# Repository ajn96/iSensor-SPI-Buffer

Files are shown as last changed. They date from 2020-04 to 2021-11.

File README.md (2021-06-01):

# iSensor SPI Buffer
The iSensor SPI Buffer is a hardware and software solution designed to buffer iSensor IMU data, enabling asynchronous sampling systems (specifically embedded Linux systems) such as the Raspberry Pi, BeagleBone, Nvidia Jetson, etc. to capture IMU data at high sampling rates **with accurate timestamps and** **without data loss**. Output data is provided through a USB Virtual COM port and/or a user SPI port allowing transparent augmentation of an existing IMU interface system.

The firmware runs on an STM32F303 microprocessor to enable full-throughput, buffered IMU data capture with a variety of output data formats. An ADG1611 analog switch IC to enable routing SYNC and DATA READY signals from the host system directly to the IMU. The SPI buffer board is designed to be compatible with all current and future iSensor IMU products. 

A custom PCB was designed to fit the profile and form factor of an ADIS1649x IMU. This profile allows the iSensor SPI Buffer to act as a drop-in solution for existing, high-performance solutions. The buffer interface is designed to mimic the iSensor page convention and SPI settings out-of-the box. 

Additional hardware and software resources are linked below.

[Detailed Register Map](markdown/REGISTER_DEFINITION.md)

[USB CLI Definition](markdown/USB_CLI.md)

[Python USB Interfacing Library](PythonUtil/)

[SD Card Data Logging Scripts](markdown/SD_SCRIPTS.md)

[Firmware Documentation (Doxygen)](https://ajn96.github.io/iSensor-SPI-Buffer/files.html)

[Software Timing Characterization](markdown/TIMING.MD)

[STM32 Processor Pin Map](markdown/PIN_MAP.md)

[Programming Guide](markdown/BUILDING.md)

A video walkthrough and tutorial of the SPI Buffer Board's features is hosted on YouTube. Click on the image below to check it out!

(http://www.youtube.com/watch?v=azpeXvWH4VI "iSensor SPI Buffer Board Walkthrough 07/09/2020")

## Hardware Platform

This firmware is designed to operate in the STMicro processor family - specifically the STM32F303 processor. The STM32F303RET6 variant of the processor family was chosen for this application because of its large SRAM and low cost. 

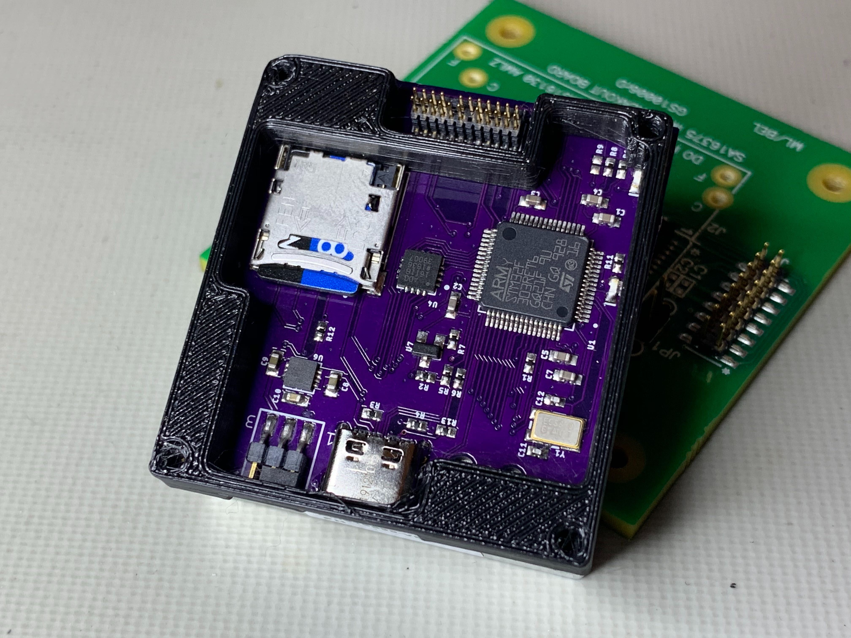
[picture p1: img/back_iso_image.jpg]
iSensor SPI Buffer Isometric Image


Revision B of the PCB design includes the following features:

- STM32F303RET6 processor (64k SRAM, hardware SPI peripherals, DMA fabric)
- ADG1611 analog switch - used for mapping SYNC and DATA READY signals from the IMU to the buffer board or SPI host
- ADP1706 high-transient linear regulator - used to regulate USB 5V and power both the IMU and buffer board
  - Power supply selection jumper for powering the buffer board & IMU from the 24-pin IMU connector or USB
- USB C expansion port - Provides a USB virtual COM port command line interface to read/write registers and stream IMU data
- SD card slot - Allows IMU data to be captured "headless" without the use of a PC or SPI host
- LEDs - used to indicate buffer state and SPI buffer errors
- 24-pin IMU connectors - used to interface with and pass through IMU and SPI Buffer data to and from a host using SPI
- ADIS1650x footprint - used to enable the evaluation and use of compact iSensor IMUs

The iSensor SPI Buffer was designed to sit between an iSensor IMU and the SPI host without changing any existing PCB designs. 

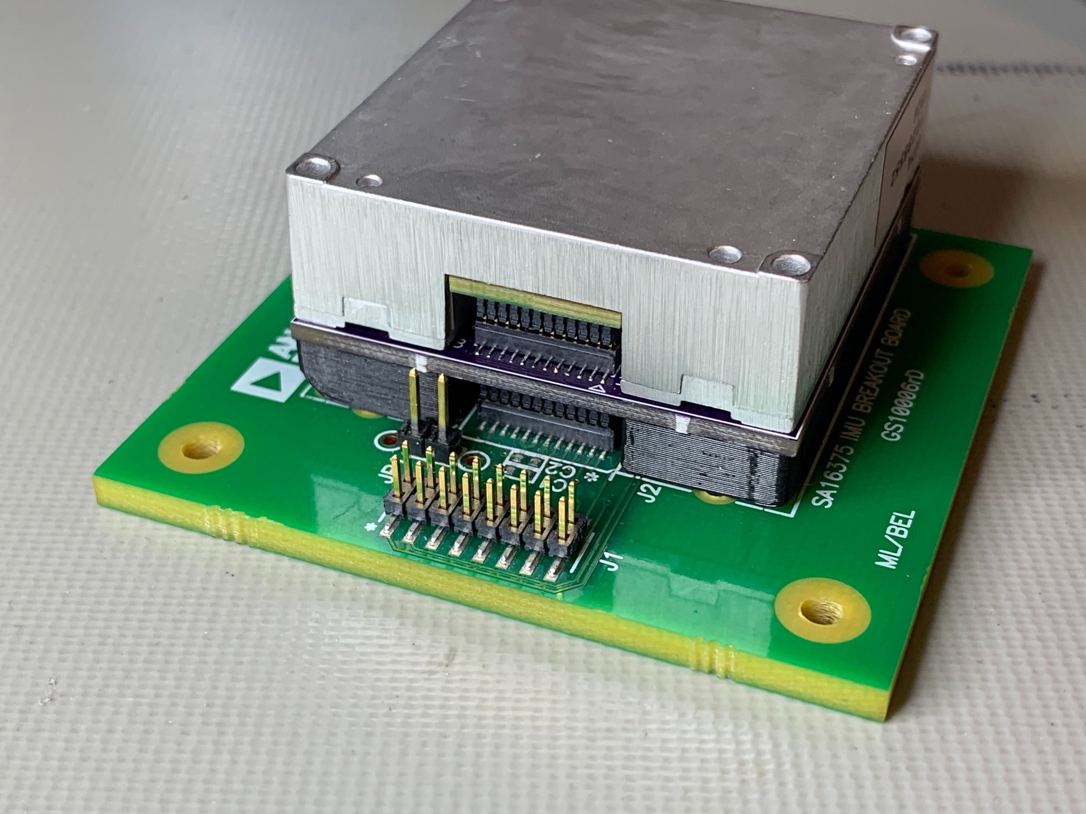
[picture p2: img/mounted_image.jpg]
iSensor SPI Buffer Mounted Image


## Development Environment and Hardware

### Software / IDE

The code contained in this repository was developed using the freely available [STM32 Cube IDE](https://my.st.com/content/my_st_com/en/products/development-tools/software-development-tools/stm32-software-development-tools/stm32-ides/stm32cubeide). A compatible project file is also included in this repository to make getting stared as easy as possible. 

### Hardware

A [TC2030-IDC cable](https://www.tag-connect.com/product/tc2030-idc-6-pin-tag-connect-plug-of-nails-spring-pin-cable-with-legs) must be used to interface with the SWD pads on the Rev B PCB. Development was originally done on an [NUCLEO-F303RE](https://www.st.com/en/evaluation-tools/nucleo-f303re.html) development board. When programming a buffer board, we've continued to use the NUCLEO as the SWD programmer. 

## Linux Driver Support

Support for the SPI Buffer Board in Linux (over SPI) was developed by [spalani7](https://github.com/spalani7). His repository is located  [here](https://github.com/spalani7/adi_imu_driver). For USB interfacing, the included Python library can be utilized for easy integration with any USB capable system.

## Design Requirements and Features

### IMU Register Interface

* "Invisible" SPI pass-through to an iSensor IMU, including modules that implement register pages
* iSensor-SPI-Buffer configuration registers and buffered data acquisition registers will be placed on unassigned IMU pages (Pages 253 - 255)

### Buffered Data Acquisition

* Autonomous IMU data acquisition will be driven by the IMU-generated data ready signal. Data will be stored in the iSensor-SPI-Buffer SRAM until retrieved by a user
* Programmable data request message (MOSI) to be transmitted after each data ready signal. Allows users to customize the register writes, contents, and order
* Programmable data acquisition length after each IMU data ready signal. Allows the user to configure the length of data read back from the IMU
* Programmable data acquisition SPI word size. The default 16-bit length provides support standard register reads, writes, and burst reads on most IMUs

### Configuration Options

* Buffer overflow setting (stop sampling vs delete oldest)
* Data ready input (from IMU) DIO number
* IMU Data ready trigger polarity
* Master SPI (interface between the iSensor-SPI-Buffer firmware and the IMU) 
  * SCLK Frequency
  * Stall time
* Slave SPI (interface between the iSensor-SPI-Buffer firmware and the host processor) 
  * Standard SPI settings (CPOL, CPHA, endianness)

### Buffer Design

* Reading a buffer retrieve register will dequeue data from the buffer data structure to the buffer output registers for retrieval by a user
* The user will can clear the buffer using a control register
* A buffer counter will be added to each buffer for the user to keep track of the state of the buffer. This counter must also be accessible without dequeuing data from buffer
* Using a maximum buffer entry size of 64 bytes, the buffer will provide a minimum of 512 frames of buffering using 32KB SRAM
  * STM32F303 has 80KB of SRAM available, so more than 512 entries may be feasible

## Architecture

### SPI Ports

The iSensor-SPI-Buffer firmware will utilize two hardware SPI ports. One operating as a master (SPI buffer to IMU communication) and the other as a slave (SPI buffer to host)
* The slave SPI port will expose the IMU register interface along with the iSensor-SPI-Buffer configuration registers to the master
* The slave SPI port will support all standard SPI configuration parameters
* The master SPI port will communicate with the IMU using the standard, iSensor SPI protocol
* The master SPI port configuration will be limited to customizing SCLK frequency and stall time

### Program Flow

The iSensor-SPI-Buffer communications interfaces (SPI, SD card logging, USB CLI) are interrupt driven. A main cyclic executive loop handles command execution, interrupt generation, and diagnostics. The cyclic executive flow is shown below:

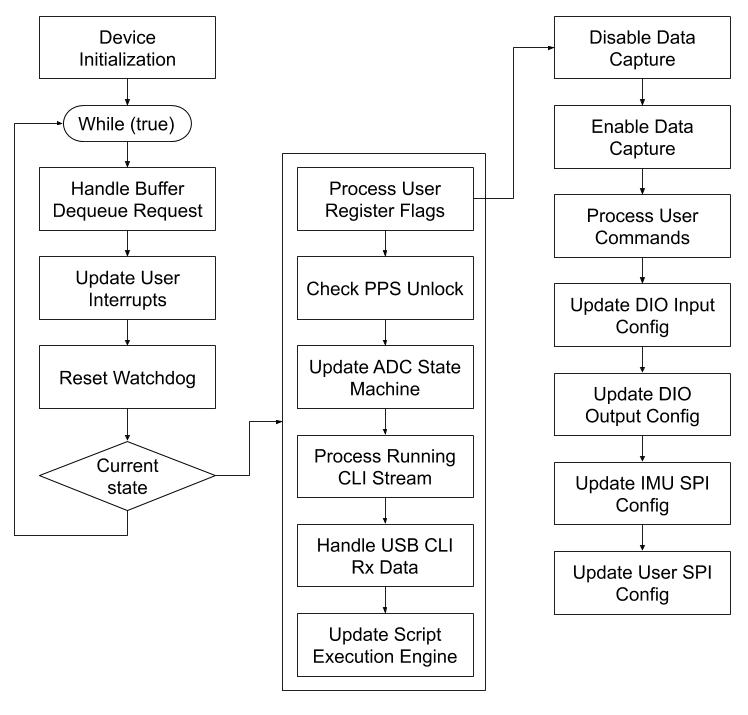
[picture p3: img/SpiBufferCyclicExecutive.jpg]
Cyclic Executive


**User SPI Interrupt**

There will be an ISR to handle user-initiated SPI transactions (slave interface). If the active register page is not one of the SPI buffer pages (253 - 255) all SPI transactions will be forwarded to the IMU downstream. 

SPI transactions will be classified as "read" or "write" by the SPI buffer board the same as the iSensor IMU SPI protocol. A write operation is signaled by setting the MSB of each 16-bit word. The upper 8 bits of the 16-bit transaction contain the register address to be written to as well as the read/write bit. The lower 8 bits of the 16-bit transaction contain the data to be written. 

A single read request transmitted to the SPI buffer on the slave interface will result in *two* SPI transactions sent to the IMU on the master interface. The first transaction sends the register read request to the IMU and the second reads the requested register contents data back from the IMU. The requested IMU register is then loaded into the SPI buffer user SPI transmit buffer so that it is available to the user on the next user SPI transaction.  For write transactions, a single write command will be sent to the IMU. The data resulting from the write transaction is then loaded into the SPI buffer user SPI transmit buffer. Unlike the read operation, a write operation will not automatically generate an additional SPI transaction. The diagram below shows the IMU SPI pass-through process for a register read operation.

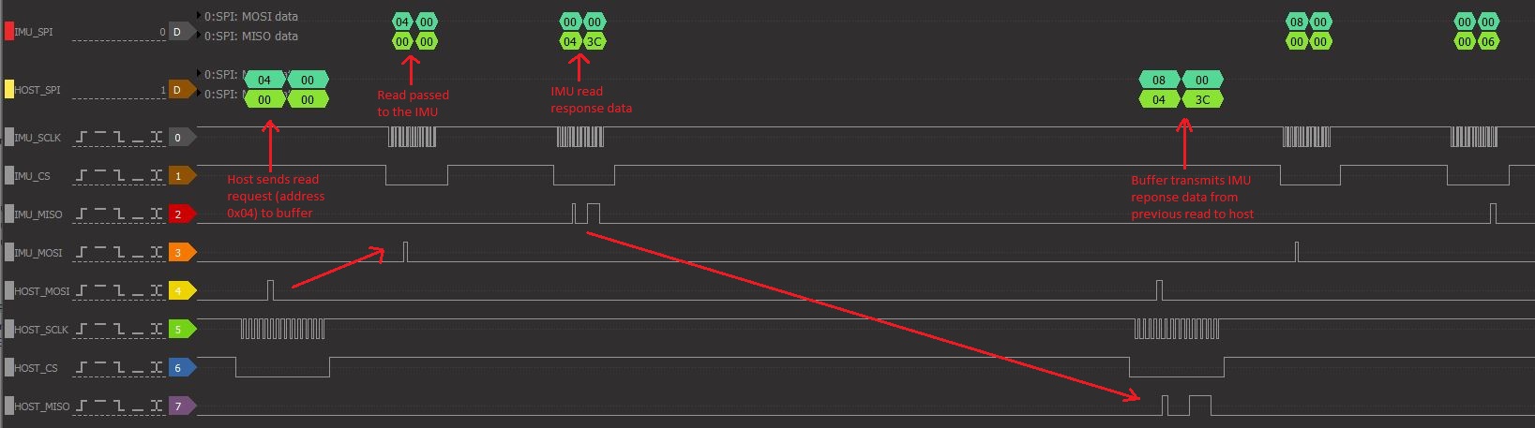
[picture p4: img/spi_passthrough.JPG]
SPI Passthrough


**Autonomous Data Capture**

When the currently selected page is 255 (buffer output register page), the iSensor SPI Buffer firmware will begin to monitor a user-specified GPIO interrupt for data ready signals pulses. Once a data ready pulse is detected, the firmware will transmit the data contained in page 254 (buffer transmit data) in the order specified by the user. Data received from the IMU during each 16-bit transaction will be stored in a new buffer entry in the iSensor-SPI-Buffer SRAM. The firmware will use DMA and timer peripherals to perform the SPI transactions with minimal CPU intervention while giving control over the SPI SCLK and stall time. 

The data capture ISR will be triggered by a user-specified GPIO, corresponding to the IMU data ready signal. The data capture ISR will configure a timer peripheral (which drives SPI word transmission timing) to trigger a DMA between memory and SPI. A DMA done ISR will handle cleaning up the DMA transactions and incrementing buffer pointers following a complete data set acquisition from the IMU. If the selected page is changed off page 255, the IMU data ready interrupt data capture functionality will be disabled (can be re-enabled by writing 255 to the page ID register on any page).

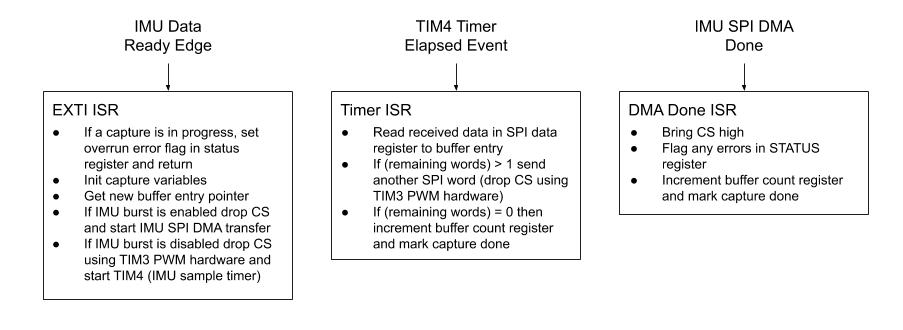
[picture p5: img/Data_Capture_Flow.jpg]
Buffered Capture Data Flow


**User Interrupt Signaling (to host)**

Each of the four DIO lines from the iSensor-SPI-Buffer to the master device can be configured to operate in one of four modes
* Watermark Interrupt Mode: The selected DIO will go high when a specified number of samples are available to be dequeued. This allows a master device to simply monitor the data ready interrupt signal for a positive edge, and then dequeue a large number of IMU data samples
* Buffer Full Interrupt Mode: The selected DIO will go high when the buffer is full
* Error Interrupt Mode: The selected DIO will go high when an error is detected and flagged in the STATUS register
* Pin Pass-Through Mode: The DIO output from the IMU (e.g. a data ready signal or sync signal) will be directly connected to the master device, using an ADG1611 switch. When a DIO is configured in pin pass-through mode it cannot be used for interrupt signaling

The state of each interrupt signal is checked and updated on each iteration of the main cyclic executive loop. This ensures quick response time to changes in the buffer state while maintaining a simple program flow.

**Command Execution**

* When a write is issued the USER_COMMAND register, a COMMAND flag will be set and processed by the cyclic executive loop
* While a command is being executed, the user SPI port will be disabled, and any interrupt lines (data ready or buffer full) will be brought low

### Register Interface

* Configuration registers for iSensor SPI buffer available on page 253
* The data acquisition write data registers (data to transmit per data ready) available on page 254
* Buffer output data registers on page 255
* Volatile output registers available on page 252

## Recovering From a Bad SPI Configuration

This buffer firmware includes a feature that allows the host SPI peripheral on the buffer board to be reconfigured to suit the host's needs. Because of this, it's possible to lock yourself out of the buffer board. A bad SPI configuration will usually look like the buffer board is returning the same value repeatedly for all registers. Note that the buffer board returning 0xFFFF or 0x0000 could be caused by other issues (no power to the buffer board, bad connection to the IMU, etc.) A bad SPI configuration will look similar to the image below.

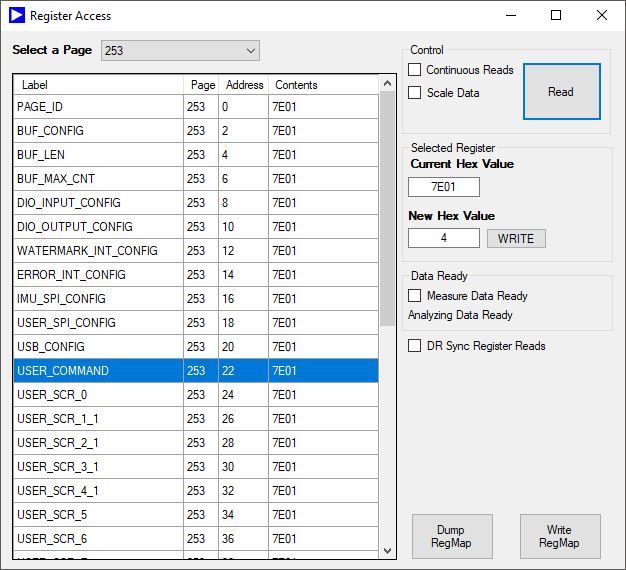
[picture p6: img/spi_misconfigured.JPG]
SPI Misconfigured


Recovering from a bad configuration requires using the USB CLI to communicate with the buffer board's firmware. While not mandatory, we recommend changing the jumper on the buffer board to USB power mode. The jumper just needs to be repositioned as shown below. 

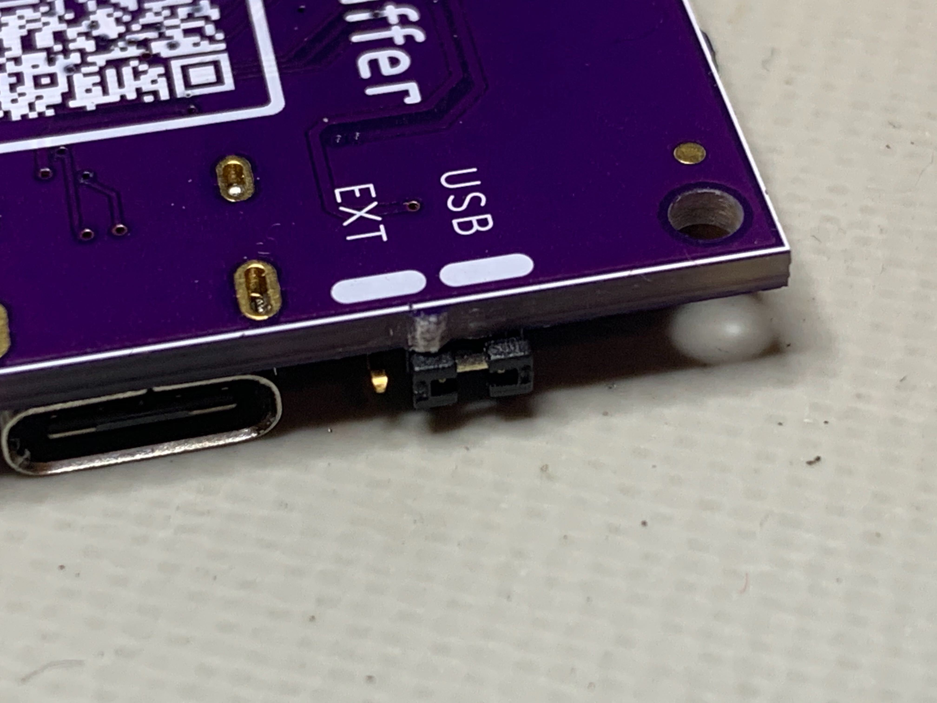
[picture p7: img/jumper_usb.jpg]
USB Jumper Setting


Using a terminal program such as [TeraTerm](https://ttssh2.osdn.jp/index.html.en) or [PuTTY](https://www.chiark.greenend.org.uk/~sgtatham/putty/) in Windows, connect to the board using the enumerated COM port. The virtual USB port will automatically detect the host serial settings, so additional configuration is usually unnecessary. 

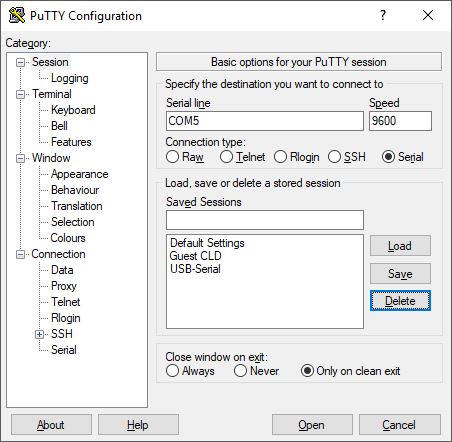
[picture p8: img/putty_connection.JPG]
PuTTY Connection


Once connected to the CLI, you can verify that the board is communicating correctly by typing `help` into the console. You should see a message like the one shown below.

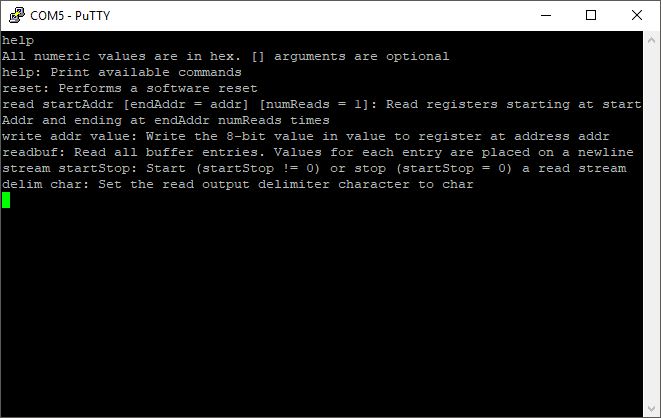
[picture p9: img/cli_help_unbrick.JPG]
CLI Help Print


After you've verified that the CLI is working correctly, type the following command, followed by a carriage return.

`freset`

This will execute a factory reset command followed by a flash update command. The board should now be reset to SPI Mode 3 with CS active low. The default register settings will have also been committed to flash, so they should persist throughout reboots. 

"The SPI who loved me" - PK

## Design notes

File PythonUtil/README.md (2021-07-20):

# iSensor-SPI-Buffer Python Library

This library allows easy programmatic interfacing to the iSensor-SPI-Buffer USB command line interface through a Python API. The API allows for configuration of the iSensor-SPI-Buffer board, as well as double buffered high-throughput data capture from a connected IMU. The image below shows the general flow for IMU data capture using this library.

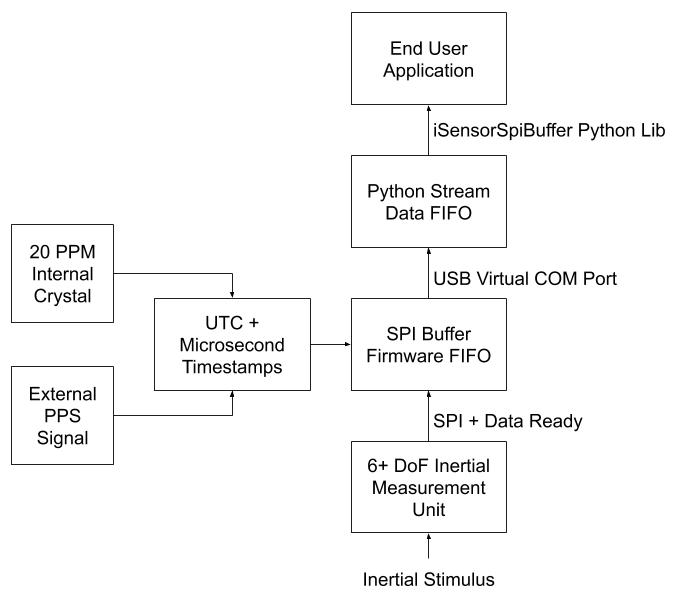
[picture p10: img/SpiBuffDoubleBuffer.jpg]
python_data_flow


### Prerequisites 

* Python 3.7 or newer
* PySerial (pip install pyserial)
* iSensor-SPI-Buffer firmware v1.11 or newer

### Hardware Setup

To use this library, the iSensor-SPI-Buffer board must be connected to your system via USB. For easiest setup, it is recommended to set the buffer board supply jumper to "USB", allowing the buffer board and connected DUT to be powered via a 2A linear regulator (from USB 5V supply).

Once the buffer board is successfully connected and powered over USB, the serial port "ID" must be determined. This port ID is provided to the ISensorSpiBuffer Python class initializer, and is used to set up internal the serial port object for CLI interactions

On Windows, the board will show up as a "USB Serial Device" under the Ports (COM & LPT) section of the device manager. The COM port name (in this example "COM11") is used as the port name for the ISensorSPIBuffer Python library

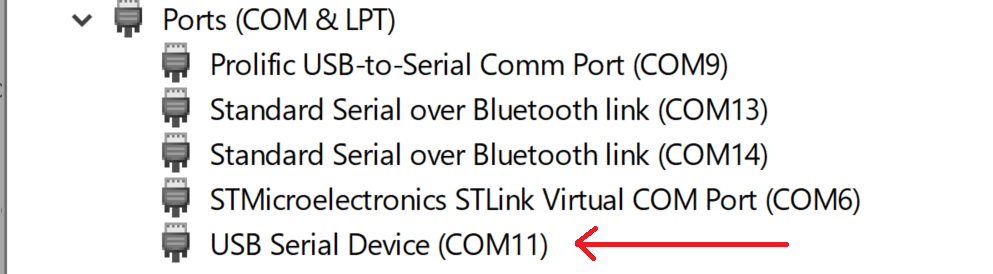
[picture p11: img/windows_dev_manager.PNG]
win_dev_manager


In Linux the port name (dev/ path for the device) can be determined using the included bash script. The following image shows the result from running ListDevPath in a Linux VM (with the buffer board passed in from the VirtualBox host). In this example, the buffer board is "/dev/ttyAMC0", which is provided as the port name for the ISensorSPIBuffer Python library.

linux_dev_list

### Python Setup

The PYTHONPATH variable will likely have to be set to include the spi_buf_cli.py file. To do this on Linux, open a terminal and for example type: `EXPORT PYTHONPATH=/home/usr/pi/Desktop/iSensor-SPI-Buffer/PythonUtil:$PYTHONPATH`. The directory should be modified to point to the location of the PythonUtil folder in the cloned repo.

On Windows, the PYTHONPATH can be updated by setting the Environmental Variable PYTHONPATH to include the PythonUtil directory in the cloned repo.

Once you have identified the port "ID" for the buffer board, connecting to the board is as simple as creating and initializing an instance of the ISensorSPIBuffer Python class. The initializer configures the specified serial port for use with the buffer board and performs basic setup on the buffer board itself.

For the Windows example

`buf = ISensorSPIBuffer("COM11")`

For the Linux example

`buf = ISensorSPIBuffer("/dev/ttyACM0")`

Afterwards, the functionality of the CLI can be checked using the check_connection() function. In addition, the current iSensor-SPI-Buffer firmware version can be checked using the version() call.

The outputs for the included adis1649x example programs are shown below:

**Linux**

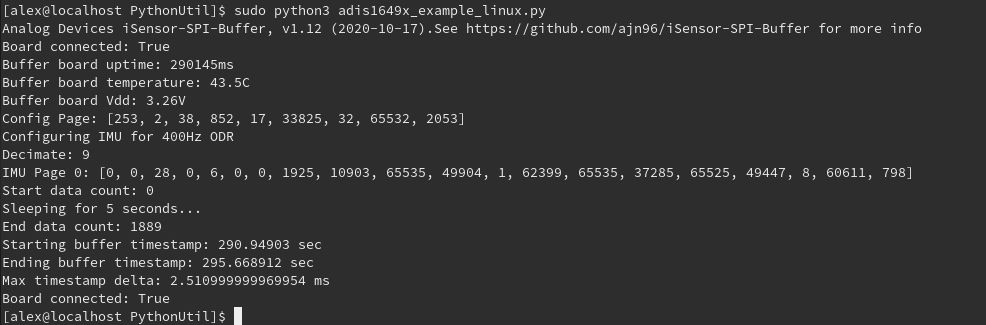
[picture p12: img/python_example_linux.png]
python_example_linux


Note, the IMU output data rate was limited to 400Hz because the program is running in a VM

**Windows**

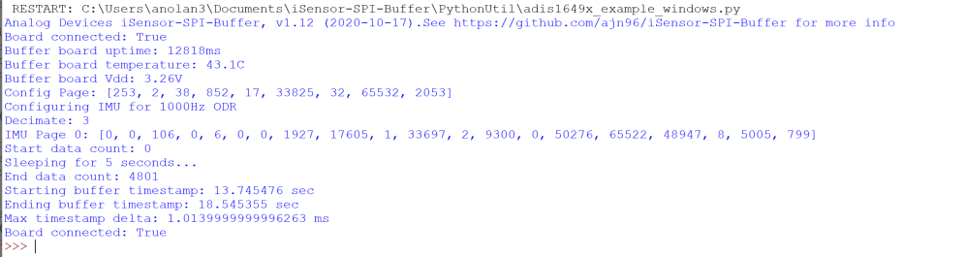
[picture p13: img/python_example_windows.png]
python_example_windows


In this example, the IMU output data rate was set to 1KHz, and each buffer was a burst output from the IMU. Using burst IMU outputs, data rates up to 2KHz seem to work consistently

## Debugging Common Setup Issues

There are a few problems which can cause difficulties using this library with the iSensor-SPI-Buffer board.

1. iSensor-SPI-Buffer firmware version not up to date. This Python library was not designed with backwards compatibility in mind, due to the relatively large number of changes in the firmware CLI behavior over the last few versions. It is intended to be used with the latest version of the iSensor-SPI-Buffer firmware for best operation. If this causes problems and you do not have the ability to update your buffer board firmware, you can download the python library version at the time of the release tag for your older version of firmware. There may be missing features / bug fixes in the older revision.
2. A "halted" stream (on PC side) can cause a watchdog reset event. This occurs when the PC does not request data back from the buffer board fast enough during a stream (mostly see this if you are debugging the Python library execution). After the watchdog reset, the board will show up as "Non-responding" in the Python library. This behavior should be resolved in future revisions of firmware.

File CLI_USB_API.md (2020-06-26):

# iSensor-SPI-Buffer USB Virtual COM Port CLI

## Driver

The USB port on the iSensor-SPI-Buffer is configured to act as a CDC type device, presenting as a virtual COM (serial) port.

The (windows) drivers to interface with the virtual COM port are provided by ST, and can be downloaded here:
https://www.st.com/en/development-tools/stsw-stm32102.html

## Functionality

The iSensor-SPI-Buffer virtual COM port exposes the same iSensor-SPI-Buffer register interface which can be accessed over SPI. In general, the functionality of each register should be the same, regardless of if the register is accessed over USB or SPI. The registers are accessed via a simple command line interface (CLI). This CLI allows a PC to interface with an IMU without the need for a SPI <-> USB board (like EVAL-ADIS-FX3).

## CLI Definition

Commands are sent to the CLI over the virtual COM port. Each command starts with a command word, followed by a number of arguments. Each command ends with a new line character. All values are in hex.

| Command | arg0 | arg1 | arg2 | Description |
| --- | --- | --- | --- | --- |
| help | N/A | N/A | N/A | List available CLI options |
| reset | N/A | N/A | N/A | Trigger a system reset  |
| read | Register address | N/A | N/A | Read a single register, at the address provided |
| read | Start address | End address | N/A | Read multiple registers, accross the address range provided |
| read | Start address | End address | Number of reads | Read multiple registers, accross the address range provided, number of reads times. Each set of reads is terminated by a new line |
| write | Register address | Write Value | N/A | Write a byte to the specified register |

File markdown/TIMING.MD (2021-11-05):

# iSensor-SPI-Buffer Timing Characterization

This document is automatically generated using timing measurements performed by an EVAL-ADIS-FX3, using the NUnit test framework

Test Date: 2021-08-30T10:48:14

Trials per timing measurement: 16

Firmware Revision: 01.15

Firmware Date (YYYY/MM/DD): 2021/08/30

Test source code is available [here](https://github.com/ajn96/iSensor-SPI-Buffer/blob/master/Test/iSensor-SPI-Buffer-Test/FunctionalTimingTests.cs)
## Reset Times

|Parameter|Min|Avg|Max|Units|
| --- | --- | --- | --- | --- |
|Power Cycle Reset||20.31||ms|
|Software Reset Time||28.35||ms|
## SPI Timings

|Parameter|Min|Avg|Max|Units|
| --- | --- | --- | --- | --- |
|Clock Frequency|||11710000|Hz|
|Read Stall|0.40|||us|
|Write Stall|0.80|||us|
|BUF_RETRIEVE Stall|1.20|||us|
## Functional Command Timings

|Parameter|Min|Avg|Max|Units|
| --- | --- | --- | --- | --- |
|Clear Buffer||5.53||us|
|Clear Fault||22.12||ms|
|Factory Reset||2.00||ms|
|Flash Update||29.30||ms|
|PPS Enable||24.56||us|
|PPS Disable||22.02||us|
|IMU Reset||1004.78||us|

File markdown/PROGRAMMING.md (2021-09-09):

# Programming the iSensor SPI Buffer

## Required Hardware

The iSensor SPI Buffer board was heavily based on the STM32 Nucleo-64 ([link](https://www.st.com/en/evaluation-tools/nucleo-f303re.html)) and, as such, is able to be programmed using the same, onboard programmer included with the development board. 

Here's what you'll need to program the SPI Buffer Board:

- STM32 Nucleo-64 ([link](https://www.st.com/en/evaluation-tools/nucleo-f303re.html)) 
- Tag-Connect TC2030-IDC ([link](https://www.tag-connect.com/product/tc2030-idc-6-pin-tag-connect-plug-of-nails-spring-pin-cable-with-legs))
- 6 x 0.1" Jumper Leads/Cables ([link](https://www.amazon.com/Premium-Breadboard-Jumper-100-Pack-Hellotronics/dp/B07GJJRH3M))

## Wiring the Programmer

Using the jumper leads, connect the programmer connector as shown below. 

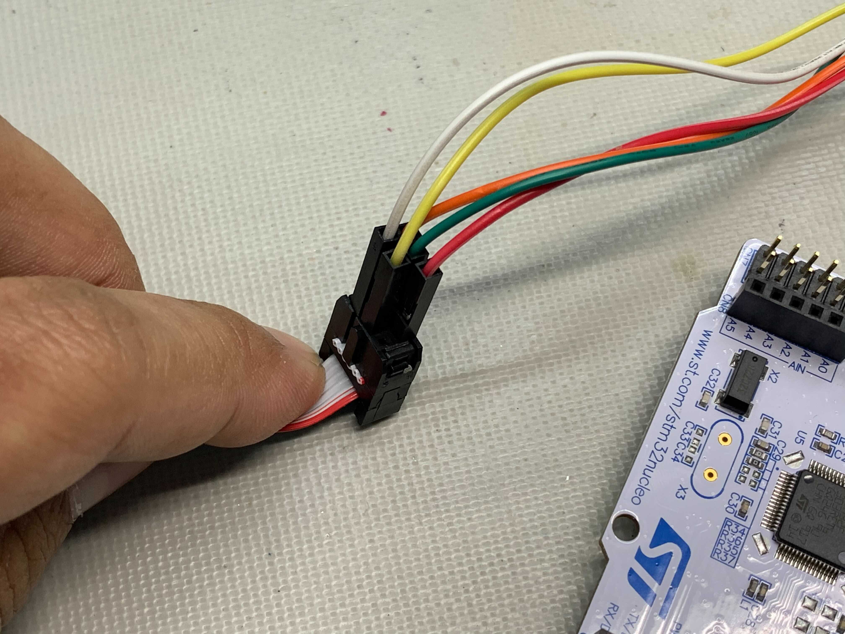
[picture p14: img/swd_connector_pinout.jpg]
SWD Connector Wiring


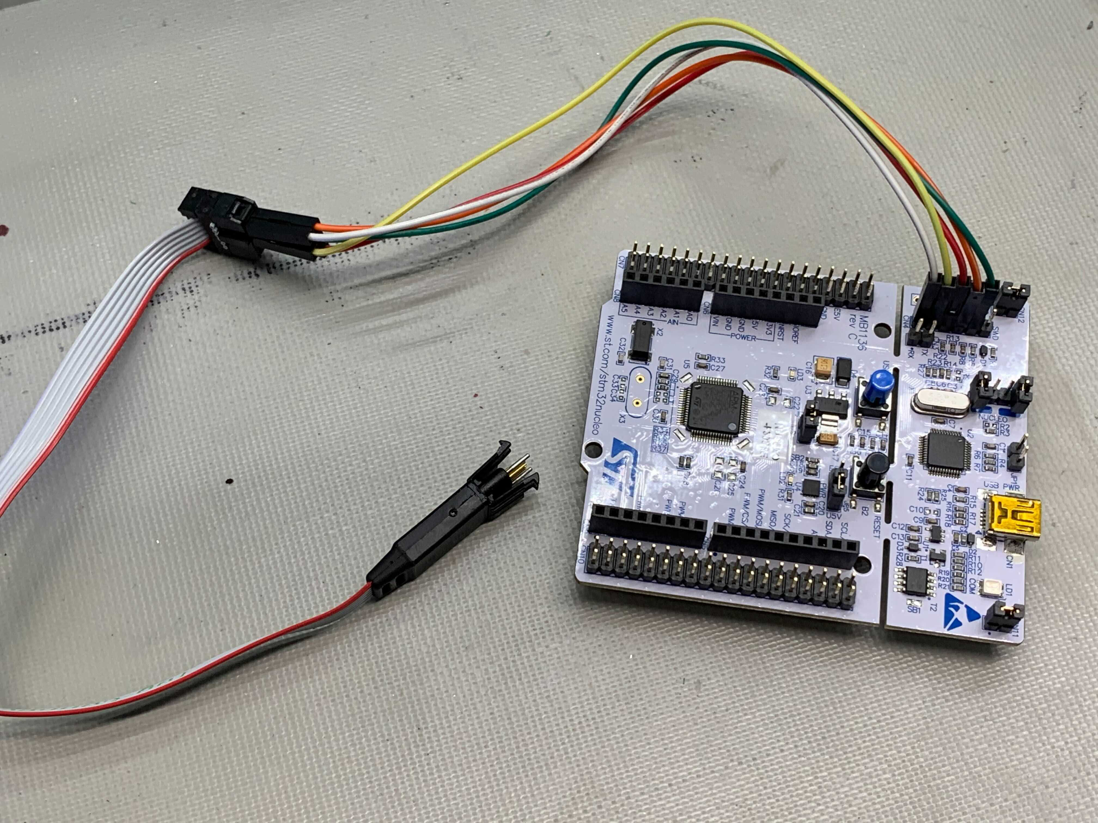
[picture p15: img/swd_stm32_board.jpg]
SWD STM32 Wiring


## Changing the SWD Jumpers to "External Programming" Mode

The STM32 Nucleo-64 must be configured for external programming by changing two jumpers as shown below.

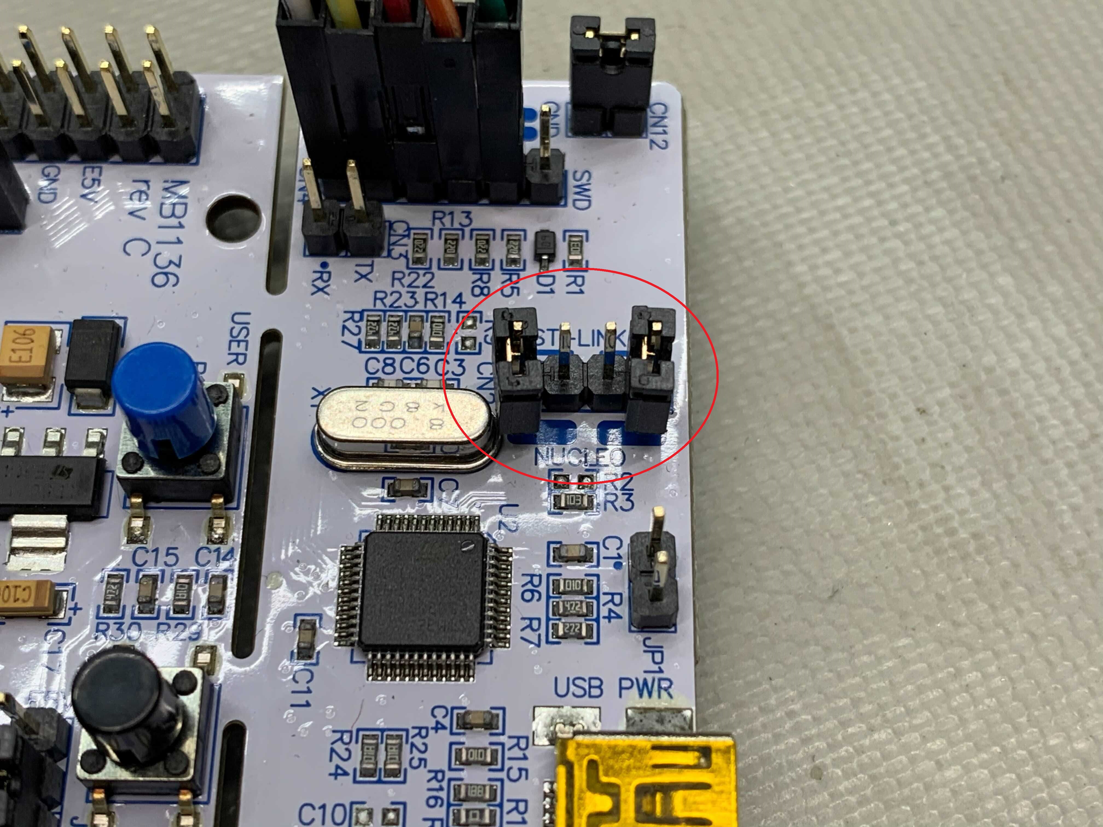
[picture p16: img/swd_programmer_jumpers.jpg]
SWD STM32 External Programming Jumpers


## Connecting the SWD Programmer to the SPI Buffer Board

The Tag-Connect pogo-pin adapter should securely clip into the SWD programming port on the SPI Buffer Board.

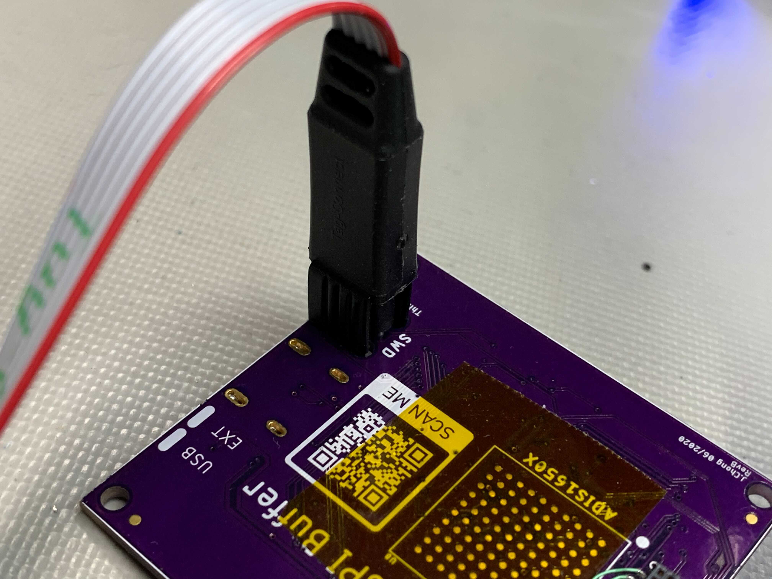
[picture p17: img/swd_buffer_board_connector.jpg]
SWD Tag-Connect Connector


## Powering the Buffer Board

The SPI Buffer Board **must be powered externally during programming!** The SWD port does *not* provide power. Power can be supplied to the SPI Buffer Board using either the USB port or the 24-pin IMU host connector. 

## Loading Firmware to the Buffer Board

To load firmware to the Buffer Board, simply drag and drop iSensor-SPI-Buffer.bin to the "NODE_F303RE" device in the Windows explorer.
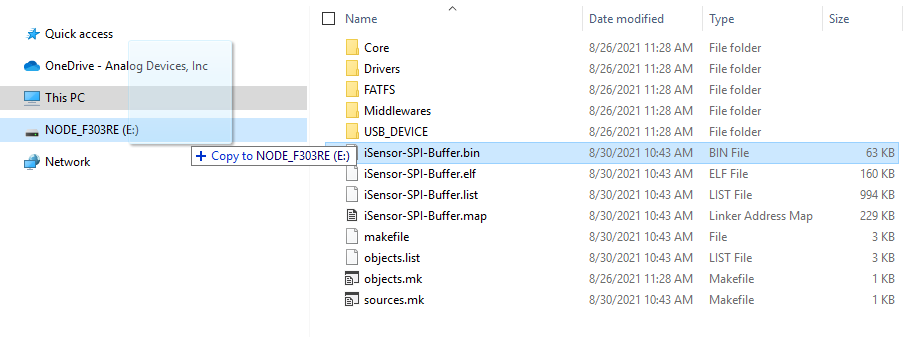
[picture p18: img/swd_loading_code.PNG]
Loading Code


## Debugging Common Issues

### Insufficient Space

If the Programmer cannot connect to the Buffer Board, it may give a "Insufficient Space" error message when attempting to load a firmware binary.

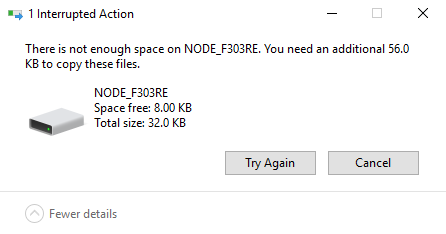
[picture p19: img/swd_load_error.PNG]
Code Loading Error


A common cause of this error is the Buffer Board not being powered up properly. The Buffer Board can be powered over USB or via the 24-pin connector, by changing J4 to the desired setting. The programming process typically works best if you apply power to the buffer board, then plug in the Nucleo pogo pin SWD connection to the buffer board, then finally connect the Nucleo to your PC via USB. Powering up the buffer board after it has already been connected to the Nucleo does not work consistently.

### Invalid Register Values

Updating the buffer board firmware does not change any register values in flash. When code is loaded initially, many registers will start with a value of 0xFFFF. To ensure the buffer board comes up in a good state, it is recommeded to run the Factory Reset command after initial programming (preferrably over the USB CLI).

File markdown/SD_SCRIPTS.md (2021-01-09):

# SD Card Data Logging

The iSensor-SPI-Buffer comes equipped with an microSD card slot to allow for autonomous device configuration and data logging via a simple scripting language. The available SD card script commands are functionally the same as the [USB command line interface](https://github.com/ajn96/iSensor-SPI-Buffer/blob/master/markdown/USB_CLI.md) commands, with a superset of additional program flow commands added.

This SD card script engine can be used for headless data capture with a USB battery pack. This is useful for systems where connecting the IMU to a PC is not feasible.

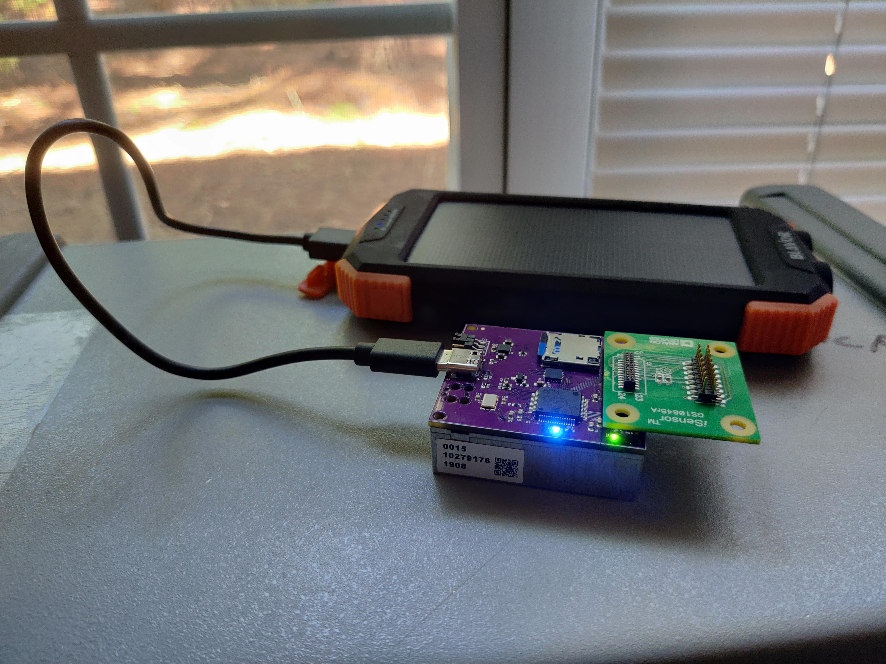
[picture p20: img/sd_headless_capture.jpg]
iSensor SPI Buffer Headless Capture


## Script Format

iSensor-SPI-Buffer SD card scripts use the same command format as the USB CLI, with any data which would normally be sent to the USB virtual COM port being written to the SD card result file. In addition to the USB CLI commands, there are three additional commands supported for SD card scripts which are not supported for the USB CLI:

* loop [loopcount]: Start of a fixed count loop
* endloop: End of a fixed count loop. No loop nesting is allowed
* sleep [sleep time, in ms]: Sleep script execution process

This set of commands gives the user significant flexibility, without making the implementation or script writing process overly complicated. Keeping all loops fixed count, and not including conditional operations ensures that all scripts should finish in a deterministic amount of time. Consistent timing behavior is important, since improperly terminating a script (by power loss, reset, etc) can result in data loss on the SD card.

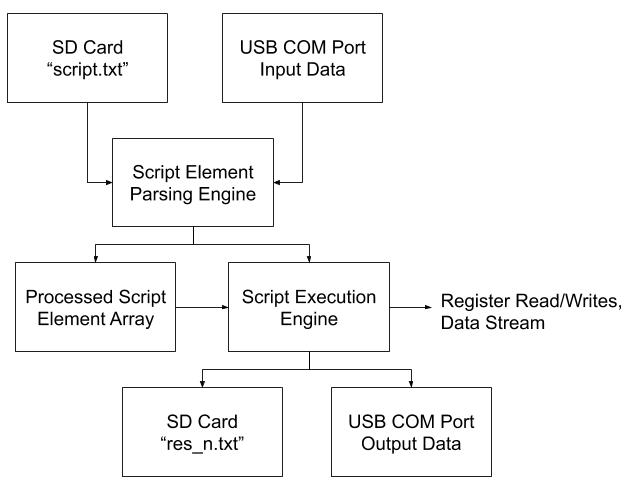
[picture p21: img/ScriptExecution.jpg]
CLI Execution Format


## SD Card Configuration

In order to run an SD card script, the SD card must be formatted FAT32, with a single volume. 

The script file must be saved as "script.txt" in the top level directory of the SD card volume. The output from the script running will be placed in a numbered result file (RES_nnn.TXT, where nnn is the run number, starting at 0) in the top level directory. Each script run will result in a new output file creation by the iSensor-SPI-Buffer firmware, allowing for easy identification of different runs.

At the start of each script run, "Script Starting..." will be printed to the result file.

## Starting a Script

If the iSensor-SPI-Buffer is connected to a host processor, a script can be started by setting the SCRIPT_START bit of the COMMAND register once a correctly formatted SD card is inserted.

If the iSensor-SPI-Buffer is intended to run headless (powered by a USB battery pack), a user can set the SCRIPT_AUTORUN bit of the USB_CONFIG register, and issue a flash update to store the register value to non-volatile memory. If the script autorun bit is set when the iSensor-SPI-Buffer firmware finishes initialization, a script start command will be executed autonomously.

If there is an error starting a script (no SD card, invalid format, invalid script file, etc) the SCRIPT_ERROR bit of the STATUS register will be set. If the script starts successfully, the SCRIPT_RUNNING bit of the STATUS register will be set. This bit will stay set until the script execution process finishes, or is terminated. Once the script has finished, the SCRIPT_RUNNING bit will clear automatically, without the STATUS register being read. This allows a user to monitor the script execution process without register access by looking at the error LED and ERROR interrupt outputs (set ERROR_INT_CONFIG to mask out other error sources).

To cancel a running script, the user can set the SCRIPT_CANCEL bit of the COMMAND register. This will stop the script execution process, close any open files, and unmount the SD card volume. Unfortunately, there is not any way to cancel a script if the iSensor-SPI-Buffer is running headless.

## Example Scripts

These are some potential scripts a user could utilize for the [ADIS16497](https://www.analog.com/en/products/adis16497.html) high performance IMU. These scripts assume that the iSensor-SPI-Buffer registers are already configured as desired by the user.

### Continuous Data Streaming Through Buffer

`write 0 3 //select page 3 on IMU`

`write c 50 //set DEC_RATE to 0x50 (80) to reduce ODR to a rate slower than the SD card can write`

`write 0 0 //Select page 0 on IMU (output data page)`

`stream 1 //enable data streaming`

`write 0 ff //select page 255 (buf data page). This starts data capture process`

`sleep 2710 //sleep for 0x2710ms (10 seconds). The stream will log data while this sleep is processing`

`stream 0 //disable streaming`

### Asynchronous IMU Register Logging

`write 0 0 //select IMU page 0`

`loop 64 //loop 0x64 (100) times`

`read 4 28 //read IMU output data registers`

`sleep 64 //sleep for 100ms`

`endloop //end of loop`

### Full Bandwidth Buffered Data Capture

`write 0 3 //select page 3 on IMU`

`write c 0 //set DEC_RATE to 0 to get max ODR`

`write 0 0 //Select page 0 on IMU (output data page)`

`loop a //loop 10 times`

`write 0 ff //select page 255 (buf data page). This starts buffered data capture process`

`sleep 64 //sleep for 100ms, to allow the buffer to fill with IMU data`

`write 0 fd //select page 253 (buf config page). This stops buffered data capture process`

`readbuf //write full buffer contents to the SD card`

`endloop //end of loop`

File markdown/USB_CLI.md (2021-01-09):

# iSensor-SPI-Buffer USB Virtual COM Port CLI

## Driver

The USB port on the iSensor-SPI-Buffer is configured to act as a CDC type device, presenting as a virtual COM (serial) port.

The default windows virtual COM port driver should allow for communications. 

## Functionality

The iSensor-SPI-Buffer virtual COM port exposes the same iSensor-SPI-Buffer register interface which can be accessed over SPI. In general, the functionality of each register should be the same, regardless of if the register is accessed over USB or SPI. The registers are accessed via a simple command line interface (CLI). This CLI allows a PC to interface with an IMU without the need for a SPI <-> USB board (like EVAL-ADIS-FX3).

The firmware can interface with a terminal emulator at a baud rate up to 1000000 bps. Since the device operates as a virtual COM port, baud rates less than that will work as well.

Putty or TeraTerm work well on Windows for manual interfacing with the CLI.

## Python Library

To enable easy data capture, a Python library has been written which handles interfacing with the iSensor-SPI-Buffer CLI. This library allows for easy iSensor-SPI-Buffer (and IMU) integration with an end user application, in both Linux in Windows. 

The Python API exposes the following functionality:

* 16-bit register reads/writes
* Buffered data streams (data is captured in its own thread and placed into a Python queue)
* Support for all other misc helper CLI operations

The library also handles setting up the serial port (through PySerial) and configuration the buffer board - all the user application has to do is provide the portName.

The full documentation for the python library, source code, and Linux/Windows examples, are [here](https://github.com/ajn96/iSensor-SPI-Buffer/tree/master/PythonUtil/)

## Examples

Several examples demonstrating typical use-cases for the CLI are linked below.

[CLI Stream Tutorial for ADIS1649x IMUs](https://github.com/ajn96/iSensor-SPI-Buffer/blob/master/tutorials/cli_stream_tutorial.md)

## CLI Definition

Commands are sent to the CLI over the virtual serial port. Interfacing with the SPI Buffer Board and ADI IMU follow the following structure:

```
COMMAND [ARG0] [ARG1] [ARG2]
```

Commands are case-sensitive and must include spaces between arguments. Command validation and execution is triggered by sending a new-line character (pressing ENTER). Some commands may have option arguments. The table below shows the possible commands and a brief description of their operation.

**All values should be written in <u>hexadecimal</u> without the leading "0x"**

| COMMAND | ARG0 | ARG1 | ARG2 | DESCRIPTION |
| --- | --- | --- | --- | --- |
| help | - | - | - | List available CLI options |
| read | Start Address | End Address | Number of Reads | Reads the value of a user-specified register or range of registers and prints their contents to the terminal. <br />**ARG0:** Start address or register location to be read<br />**ARG1:** Optional. End address of the register block to be read<br />**ARG2:** Optional. Number of times to read the register block |
| write | Register Address | Byte to Write | - | Writes a byte (8-bits) to a user-specified register. <br />**ARG0:** The register address to be written to<br />**ARG1:** The byte (8-bits) to be written |
| stream | 0 or 1 | - | - | Continuously streams the contents of the SPI buffer (page 255) to the terminal. This command is equivalent to calling `readbuf` every time a watermark interrupt is generated. The length of each packet is determined by the BUF_LEN register.<br />**ARG0:** [0] = stop the stream, [1] = start the stream |
| readbuf | - | - | - | Reads the entire contents of the buffer and prints it to the terminal. Each buffer entry is divided using a new-line character (\n). Issuing this command will set the active page to 255. |
| status | - | - | - | Print the contents of the <u>SPI Buffer Board</u> STATUS register to the terminal. Issuing this command will clear all non-sticky status bits and will not change the currently selected page. |
| delim | Delimiter Character | - | - | Sets the delimiter character inserted between register contents for all read operations. Any ASCII character can be used. The default delimiter used is a space. <br />**ARG0:** Delimiter character |
| echo | 0 or 1 | - | - | Controls the terminal echo configuration. When echo is disabled, characters sent to the SPI Buffer Board through the CLI will not be "echoed" back to the terminal. This setting is useful when interacting with the CLI using scripts.<br />**ARG0:** [0] = disable terminal echo, [1] = enable terminal echo (default) |
| cmd | 16-bit USER_COMMAND Register Value | - | - | Writes a 16-bit value to the <u>SPI Buffer Board</u> USER_COMMAND register in a single CLI operation. The USER_COMMAND [register description](https://github.com/ajn96/iSensor-SPI-Buffer/blob/master/REGISTER_DEFINITION.md#USER_COMMAND) contains more information on the function of each bit. Issuing this command will not change the currently selected page.<br />**ARG0:** 16-bit USER_COMMAND register value. |
| cnt | - | - | - | Prints the contents of the BUFF_CNT register to the CLI. The BUFF_CNT register shows the number of buffers stored in SPI Buffer Board memory. |
| freset | - | - | - | Execute the factory reset and flash update routines. Restores all SPI Buffer Board registers to their default values and commits them to NVM. |
| about | - | - | - | Prints information about the SPI Buffer Board firmware. |
| uptime | - | - | - | Prints the firmware uptime in milliseconds. |

Help Command
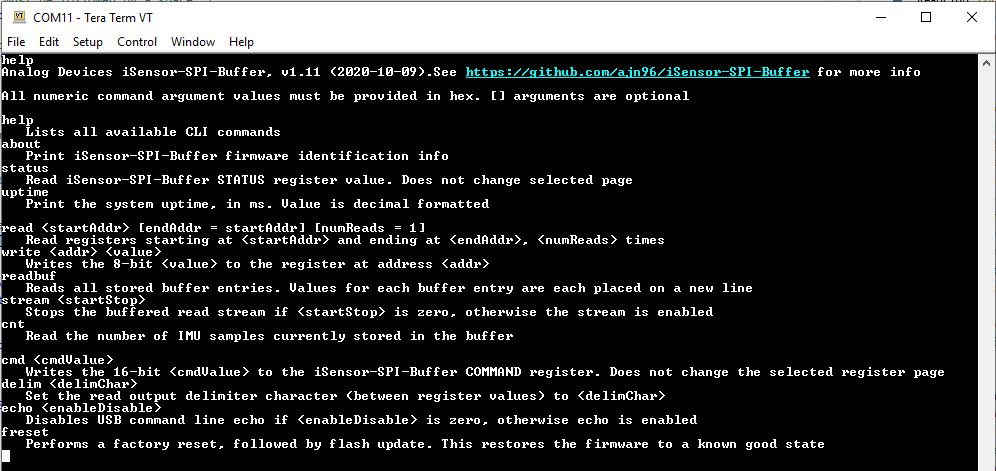
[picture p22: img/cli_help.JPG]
Help


About Command

About

Factory Reset Command
Factory Reset

Register Read Command
Read

Register Write Command
Write

Cmd/Status Commands

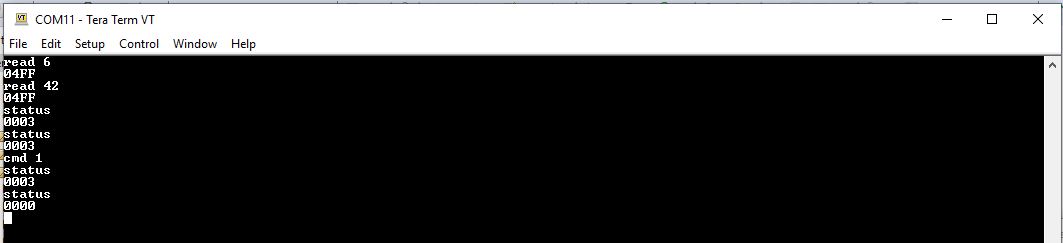
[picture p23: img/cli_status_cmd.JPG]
Cmd_Status


Delim Set Command
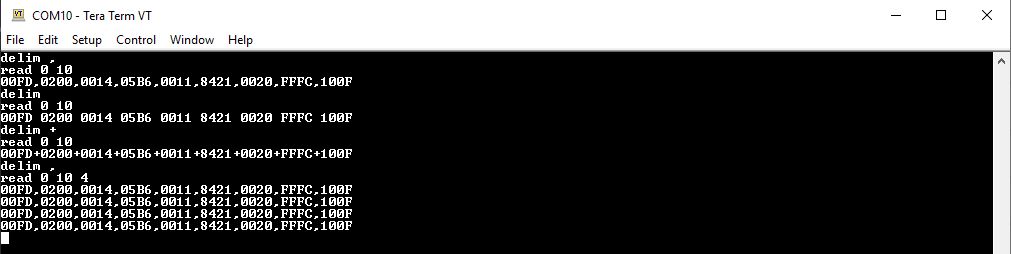
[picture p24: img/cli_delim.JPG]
Delim


Read Buffer Command
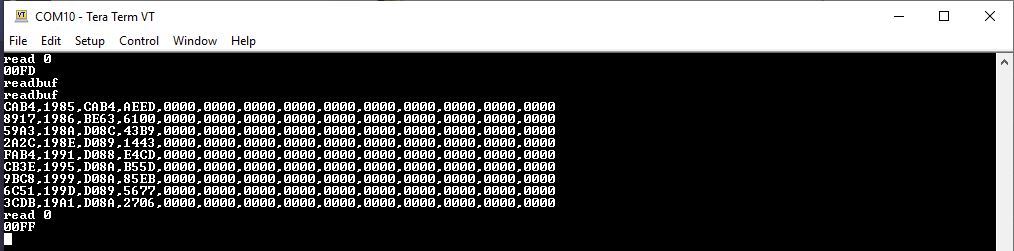
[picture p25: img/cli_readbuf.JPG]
ReadBuf


Stream Command (WATERMARK_INT_CONFIG set to 60)

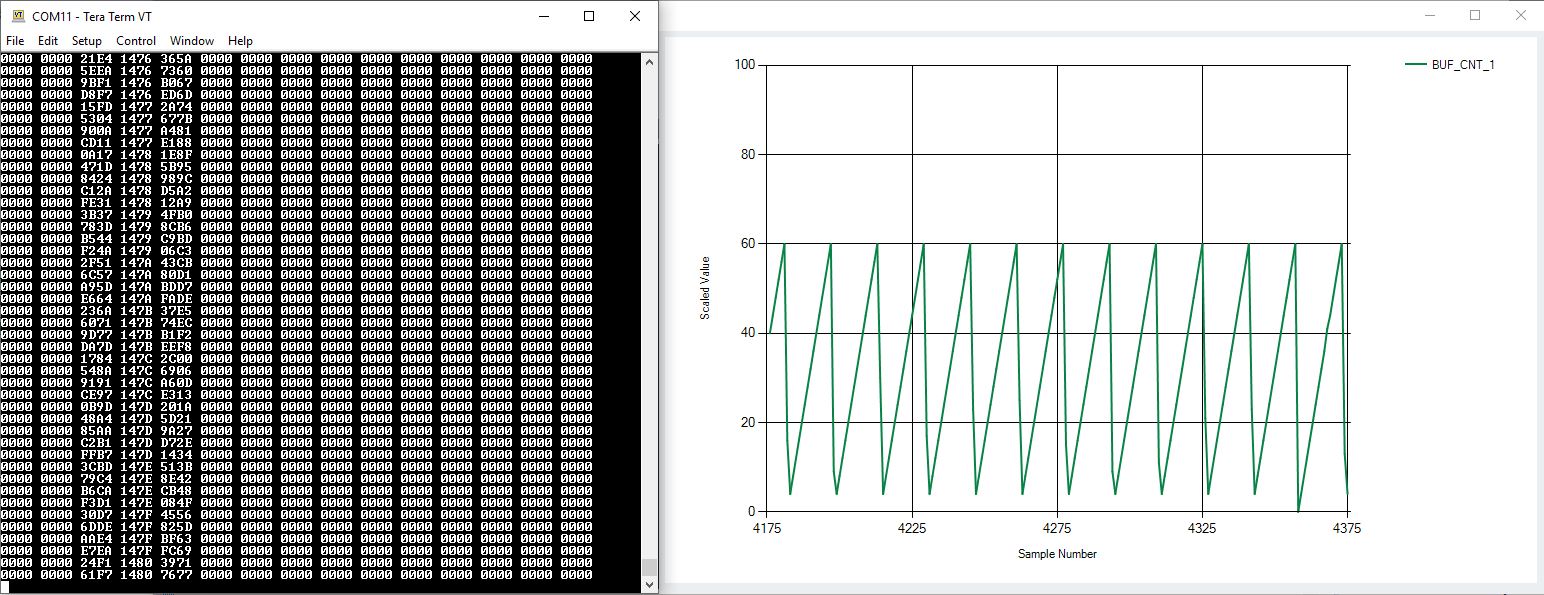
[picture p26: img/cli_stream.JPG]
Stream


Echo Command

Echo

Uptime Command

Uptime

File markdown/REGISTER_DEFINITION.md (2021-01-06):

# iSensor-SPI-Buffer Register Structure

Data and control interfacing to the iSensor SPI Buffer firmware from a master device is done via a set of 16-bit user accessible registers. These registers can be accessed over SPI, using the standard iSensor SPI format (see ADIS16xxx datasheet), or over a USB virtual serial port command line interface (see USB CLI documentation). The register address space is split into three pages, each comprised of 128 addresses. On each page, the PAGE ID register is stored at address 0. Writing to the PAGE ID register will select a different register page for access. 
* Registers which are marked with a "Default Value" will have the specified value loaded when a Factory Reset command is executed
* Registers with a R/W field marked "R" can be read. Registers marked "W" can be written. Any registers in the address space not enumerated in the register map are read only and will always read 0
* Registers which are marked "Flash Backup" are loaded from non-volatile memory on initialization. Issuing a Flash Update command will save the current register contents to non-volatile memory.  These values will then be loaded by default the next time the firmware loads.

## Page 252 - Volatile Scratch

This entire page is currently available for read/write by a user application. None of the registers on page 252 are backed up to flash - they will always initialize with a value of 0. These registers are intended as output data registers for future firmware functionality expansion.

## Page 253 - iSensor-SPI-Buffer configuration

| Address | Register Name | Default | R/W | Flash Backup | Description |
| --- | --- | --- | --- | --- | --- |
| 0x00 | [PAGE_ID](#PAGE_ID) | 0x00FD | R/W | T | Page register. Used to read or change the currently selected register page |
| 0x02 | [BUF_CONFIG](#BUF_CONFIG) | 0x0000 | R/W | T | Buffer configuration settings (overflow behavior, IMU burst data capture, user SPI burst output for buffer contents). |
| 0x04 | [BUF_LEN](#BUF_LEN) | 0x0014 | R/W | T | Length (in bytes) of each buffered data capture |
| 0x06 | [BTN_CONFIG](#BTN_CONFIG) | 0x8000  | R/W  | T | Button configuration register, which maps a button press to bits in the command register |
| 0x08 | [DIO_INPUT_CONFIG](#DIO_INPUT_CONFIG) | 0x0011 | R/W | T | DIO input configuration. Allows data ready (from IMU) and PPS (from host) input selection |
| 0x0A | [DIO_OUTPUT_CONFIG](#DIO_OUTPUT_CONFIG) | 0x8421 | R/W | T | DIO output configuration. Sets up pin pass-through and assigns interrupt outputs (error, watermark, overflow) |
| 0x0C | [WATERMARK_INT_CONFIG](#WATERMARK_INT_CONFIG) | 0x0020 | R/W | T | Watermark interrupt configuration register. Number of samples which must be enqueued in the buffer to trigger a watermark interrupt |
| 0x0E | [ERROR_INT_CONFIG](#ERROR_INT_CONFIG) | 0x03FF | R/W | T | Error interrupt configuration register. Bitmask for STATUS register to determine which bits should trigger an error interrupt |
| 0x10 | [IMU_SPI_CONFIG](#IMU_SPI_CONFIG) | 0x100F | R/W | T | IMU SPI configuration. Set SCLK frequency to the IMU and stall time between IMU SPI words |
| 0x12 | [USER_SPI_CONFIG](#USER_SPI_CONFIG) | 0x0007 | R/W | T | User SPI configuration (SPI mode, etc.). Requires KEY write to unlock |
| 0x14 | [CLI_CONFIG](#CLI_CONFIG) | 0x2000 | R/W | T | Command line interface (CLI) configuration. Configure both USB CLI and SD card data logging CLI. |
| 0x16 | [USER_COMMAND](#USER_COMMAND) | N/A | W | F | Command register (flash update, factory reset, clear buffer, software reset, etc) |
| 0x18 | [SYNC_FREQ](#SYNC_FREQ) | 0x07D0  | R/W  | T | Sets the frequency of the sync signal which can be generated by the iSensor-SPI-Buffer on DIO2_Slave |
| 0x34 | [USER_SCR_0](#USER_SCR_N) | 0x0000  | R/W | T | User scratch 0 register |
| ... | ... | ... | ... | ... | ... |
| 0x3A | [USER_SCR_3](#USER_SCR_N) | 0x0000 | R/W | T | User scratch 3 register |
| 0x3C | [UTC_TIME_LWR](#UTC_TIME_LWR) | 0x0000  | R/W  | F | Lower 16 bits of UTC timestamp (PPS counter) |
| 0x3E | [UTC_TIME_UPR](#UTC_TIME_UPR) | 0x0000  | R/W  | F | Upper 16 bits of UTC timestamp (PPS counter) |
| 0x40 | [STATUS](#STATUS) | N/A | R | F | Device status register. Clears on read |
| 0x42 | [FAULT_CODE](#FAULT_CODE) | 0x0000 | R | N/A | Fault code, stored in case of a hard fault exception. This register is stored on a separate flash page from the primary register array and can only be cleared with a FAULT_CLEAR command |
| 0x44 | [BUF_CNT](#BUF_CNT) | 0x0000 | R | F | The current number of samples stored in buffer |
| 0x46 | [BUF_MAX_CNT](#BUF_MAX_CNT) | N/A | R | F | Maximum entries which can be stored in the buffer. Determined by BUF_LEN and the fixed buffer memory allocation size |
| 0x4A | [TIMESTAMP_LWR](#TIMESTAMP_LWR) | 0x0000 | R | F | Lower 16 bits of microsecond timestamp |
| 0x4C | [TIMESTAMP_UPR](#TIMESTAMP_UPR) | 0x0000 | R | F | Upper 16 bits of microsecond timestamp |
| 0x4E | [TEMP_OUT](#TEMP_OUT) | N/A | R | F | Internal temperature output. 1 degree C = 10LSB |
| 0x50 | [VDD_OUT](#VDD_OUT) | N/A | R | F | Measured Vdd output. 1V = 100LSBs (3.3V supply -> 330 LSBs) |
| 0x64 | [SCRIPT_LINE](#SCRIPT_LINE) | N/A | R | F | Current script line being processed in an SD card script file. If no script is running, this register will be set to 0. |
| 0x66 | [SCRIPT_ERROR](#SCRIPT_ERROR) | N/A | R | F | Flag for any errors which occurs during SD card script execution. |
| 0x6C | [ENDURANCE](#ENDURANCE) | N/A | R | T | Flash update counter |
| 0x6E | [FW_REV](#FW_REV) | N/A | R | T | Firmware revision |
| 0x70 | [FW_DAY_MONTH](#FW_DAY_MONTH) | N/A | R | T | Firmware build day and month |
| 0x72 | [FW_YEAR](#FW_YEAR) | N/A | R | T | Firmware build year |
| 0x74 | [DEV_SN_0](#DEV_SN_N) | N/A | R | T | Processor core serial number register, word 0 |
| ... | ... | ... | ... | ... | ... |
| 0x7E | [DEV_SN_5](#DEV_SN_N) | N/A | R | T | Processor core serial number register, word 5 |

## Page 254 - Buffer write data

| Address | Register Name | Default | R/W | Flash Backup | Description |
| --- | --- | --- | --- | --- | --- |
| 0x00 | [PAGE_ID](#PAGE_ID) | 0x00FE | R/W | T | Page register. Used to change the currently selected register page |
| 0x12 | [BUF_WRITE_0](#BUF_WRITE_N) | 0x0000 | R/W | T | First transmit data register (data sent to IMU DIN) |
| ... | ... | ... | ... | ... | ... |
| 0x50 | [BUF_WRITE_31](#BUF_WRITE_N) | 0x0000 | R/W | T | Last transmit data register |
| 0x7C | [FLASH_SIG_DRV](#FLASH_SIG_DRV) | N/A | R | F | Derived flash memory signature register (determined at initialization) |
| 0x7E | [FLASH_SIG](#FLASH_SIG) | N/A | R | T | Stored flash memory signature register |

## Page 255 - Buffer output registers

| Address | Register Name | Default | R/W | Flash Backup | Description |
| --- | --- | --- | --- | --- | --- |
| 0x00 | [PAGE_ID](#PAGE_ID) | 0x00FF | R/W | T | Page register. Used to change the currently selected register page |
| 0x02 | [STATUS_1](#STATUS) | 0x0000 | R | F | Mirror of the STATUS register. Clears on read |
| 0x04 | [BUF_CNT_1](#BUF_CNT) | 0x0000 | R/W | F | The number of samples stored in the buffer. Write 0 to this register to clear the buffer. Other writes are ignored |
| 0x06 | [BUF_RETRIEVE](#BUF_RETRIEVE) | 0x0000 | R | F | Read this register to dequeue new data from buffer to buffer output registers |
| 0x08 | [BUF_UTC_TIME_LWR](#BUF_UTC_TIME_LWR) | 0x0000 | R | F | Lower 16 bits of buffer entry UTC timestamp (driven by PPS input signal) |
| 0x0A | [BUF_UTC_TIME_UPR](#BUF_UTC_TIME_UPR) | 0x0000 | R | F | Upper 16 bits of buffer entry UTC timestamp (driven by PPS input signal) |
| 0x0C | [BUF_TIMESTAMP_LWR](#BUF_TIMESTAMP_LWR) | 0x0000 | R | F | Lower 16 bits of buffer entry microsecond timestamp |
| 0x0E | [BUF_TIMESTAMP_UPR](#BUF_TIMESTAMP_UPR) | 0x0000 | R | F | Upper 16 bits of buffer entry microsecond timestamp |
| 0x10 | [BUF_SIG](#BUF_SIG) | 0x0000 | R | F | Buffer entry checksum register |
| 0x12 | [BUF_DATA_0](#BUF_DATA_N) | 0x0000 | R | F | First buffer output register (data received from IMU DOUT while transmitting BUF_WRITE_0 data) |
| ... | ... | ... | ... | ... | ... |
| 0x50 | [BUF_DATA_31](#BUF_DATA_N) | 0x0000 | R | F | Last buffer output register |

# iSensor-SPI-Buffer detailed register descriptions

## PAGE_ID

Page: N/A, Address: 0x00 (0)

| Bit | Name | Description |
| --- | --- | --- |
| 15:0 | PAGE | Selected page. Setting the page to a value outside [253-255] will result in SPI traffic being passed to the IMU. Setting the page to 255 will start the buffered data capture process. |

## BUF_CONFIG

Page: 0xFD (253), Address: 0x02 (2)

| Bit | Name | Description |
| --- | --- | --- |
| 0 | OVERFLOW | Buffer overflow behavior. 0 stop sampling, 1 replace oldest data |
| 1 | IMU_BURST | Enables IMU burst data capture for buffer entries (IMU <-> iSensor-SPI-Buffer SPI port) |
| 2 | BUF_BURST | Enables burst reading of buffer output data registers, over the user SPI port |
| 15:3 | RESERVED | Currently unused |

**IMU_BURST**
When the IMU_BURST bit is set, each buffered data capture from the IMU is performed as a single SPI burst transaction (drop CS, clock out all data, raise CS). The length of the burst transaction is determined by BUF_LEN. When the IMU_BURST bit is cleared, IMU data is captured using a sequence of 16 bit SPI words. When the selected page is changed to an IMU page (page != (253, 254, 255)), the IMU SPI port will be restored to register mode, regardless of the BUF_CONFIG setting. The IMU burst data capture will be enabled again when page 255 (buffed data capture page) is re-selected, and the IMU_BURST bit is set.

IMU burst data capture (BUF_CONFIG[1] == 1), with IMU SPI MISO wired to MOSI:

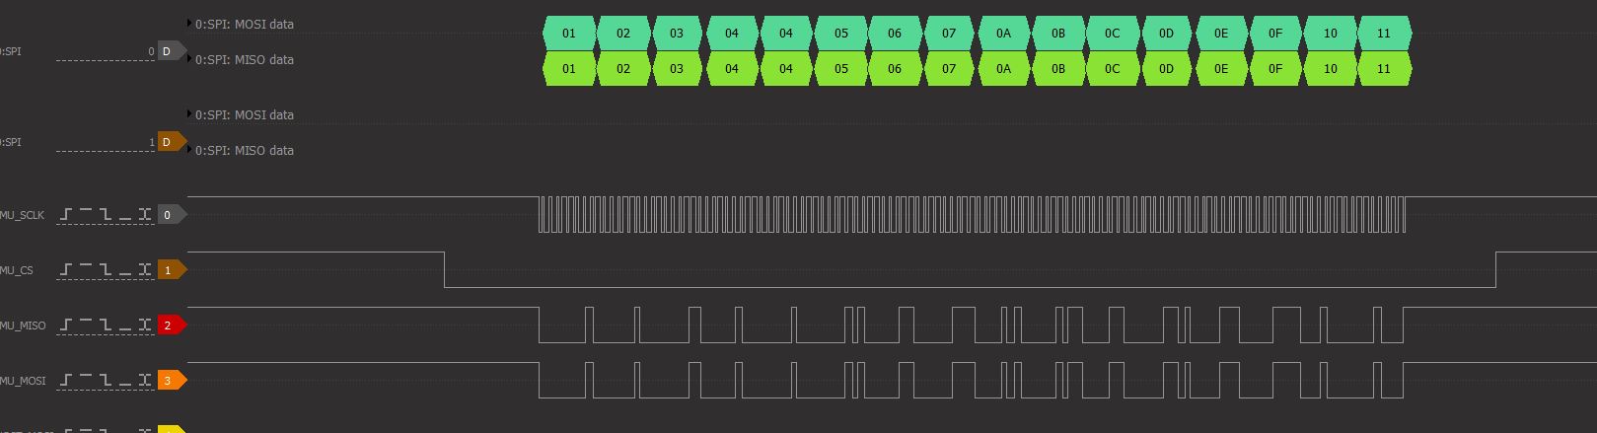
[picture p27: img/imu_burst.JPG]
IMU Burst


Same IMU Data Capture in register mode (BUF_CONFIG[1] == 0):

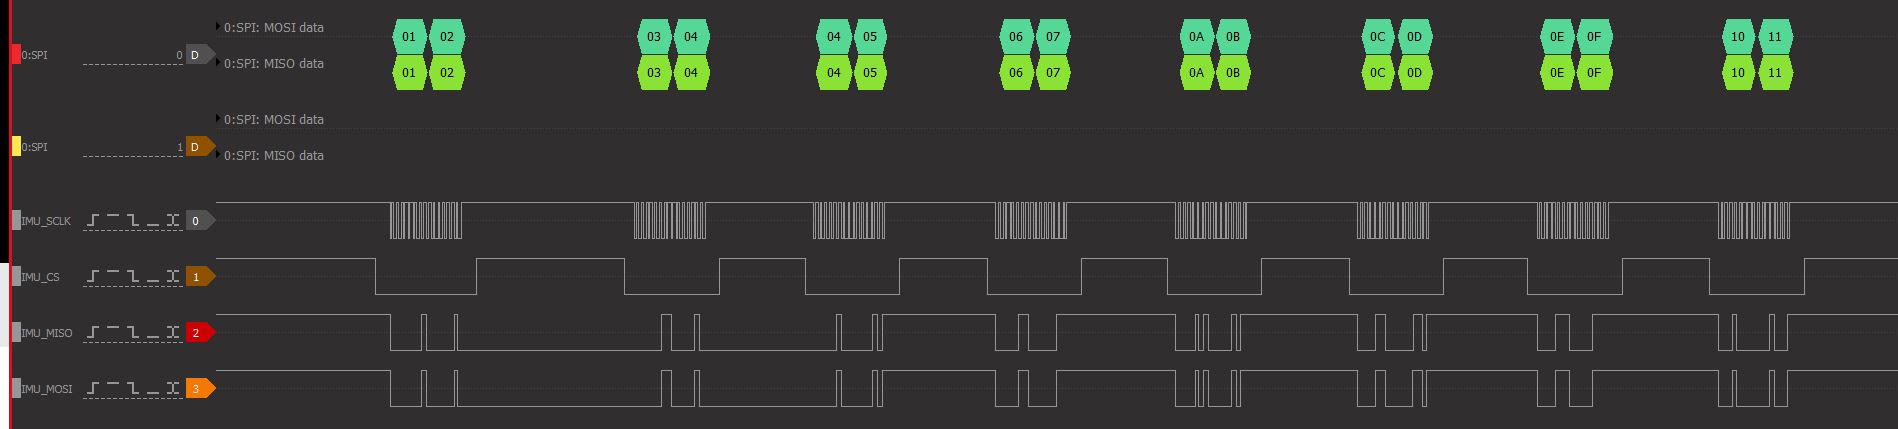
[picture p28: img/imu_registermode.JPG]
IMU Register mode


**BUF_BURST**
When the BUF_BURST bit is set and the buffer retrieve register is read, the user SPI interface is configured to clock out the full buffer entry, starting with the timestamp. Multiple buffer burst reads can be chained together by sending a BUF_RETRIEVE read request at the start of the burst data capture, which will trigger a second buffer burst output after the first read is completed, and so on. After a buffer burst output has been enabled, the iSensor-SPI-Buffer slave SPI port will not return to "normal" mode until the full buffer entry has been read (BUF_LEN + 12 bytes clocked out). More detail about the buffer burst output is included in the  [buffer burst output](#buffer-burst-output) section

## BUF_LEN

Page: 0xFD (253), Address: 0x04 (4)

| Name | Bits | Description |
| --- | --- | --- |
| 15:0 | LEN | Length (in bytes) of each buffer entry. Valid range 2 - 64. Must be a multiple of 2 (16 bit word size) |

If the IMU_BURST bit of the BUF_CONFIG register is set, the IMU burst word length will be determined by the contents of this register.

## BTN_CONFIG

Page: 0xFD (253), Address: 0x06 (6)

| Bit  | Name | Description |
| ---- | --- | --- |
| 15:0 | CMD_MASK | When the user button is pressed, the USER_COMMAND commands corresponding to the bits set in this register are executed. The bits are executed in priority order from LSB to MSB. |

For example, setting this register to 0x800C will trigger a factory reset (0x4), followed by a flash update (0x8) and lastly a software reset (0x8000) when the user button is pressed. 

The primary use case for the button is reset and script management (start/stop)

## DIO_INPUT_CONFIG

Page: 0xFD (253), Address: 0x08 (8)

| Bit | Name | Description |
| --- | --- | --- |
| 3:0 | DR_SELECT | Select which IMU DIO output pin is treated as data ready. Can only select one pin |
| 4 | DR_POLARITY | Data ready trigger polarity. 1 triggers on rising edge, 0 triggers on falling edge |
| 6:5 | RESERVED | Currently unused |
| 7 | PPS_POLARITY | PPS trigger polarity. 1 triggers on rising edge, 0 triggers on falling edge |
| 11:8 | PPS_SELECT | Select which host processor DIO output pin acts as a Pulse Per Second (PPS) input, for time base synchronization |
| 13:12 | PPS_FREQ | Select the PPS input frequency (10 ^ (PPS_FREQ) Hz). A value of 0 corresponds to a real PPS signal (one pulse per second), which is the recommended mode to use the PPS input. A value of 1 -> 10Hz, 2 -> 100Hz and 3 -> 1000Hz for the PPS input signal. The UTC_TIMESTAMP will be scaled based on the frequency value provided here, to ensure it increments once per second |
| 15:14 | RESERVED | Currently unused |

For each field in DIO_INPUT_CONFIG, the following pin mapping is made:
* Bit0 -> DIO1
* Bit1 -> DIO2
* Bit2 -> DIO3
* Bit3 -> DIO4

The following default values will be used for DIO_INPUT_CONFIG:
* DR_SELECT: 0x1. DIO1 is used for data ready
* DR_POLARITY: 0x1. Data ready is posedge triggered
* PPS_SELECT: 0x0. PPS input is disabled by default
* PPS_POLARITY: 0x0. PPS triggers on falling edge
* PPS_FREQ: 0x0. PPS module is configured for 1Hz sync signal

## DIO_OUTPUT_CONFIG

Page: 0xFD (253), Address: 0x0A (10)

| Bit | Name | Description |
| --- | --- | --- |
| 3:0 | PIN_PASS | Select which pins are directly connected from the host processor to the IMU using an ADG1611 analog switch |
| 7:4 | WATERMARK_INT | Select which pins are driven with the buffer watermark interrupt signal from the iSensor-SPI-Buffer firmware |
| 11:8 | OVERFLOW_INT | Select which pins are driven with the buffer overflow interrupt signal from the iSensor-SPI-Buffer firmware |
| 15:12 | ERROR_INT | Select which pins are driven with the error interrupt signal from the iSensor-SPI-Buffer firmware |

For each field in DIO_OUTPUT_CONFIG, the following pin mapping is made:
* Bit0 -> DIO1
* Bit1 -> DIO2
* Bit2 -> DIO3
* Bit3 -> DIO4

The following default values will be used for DIO_OUTPUT_CONFIG:
* PIN_PASS: 0x1. DIO1 (typically acts as IMU data ready) will be passed through using an Analog Switch. This allows for direct reading of the data ready signal
* WATERMARK_INT: 0x2. The buffer watermark interrupt is applied to DIO2 by default
* OVERFLOW_INT: 0x4. The buffer overflow interrupt is applied to DIO3 by default
* ERROR_INT: 0x8. The error interrupt is applied to DIO4 by default

## WATERMARK_INT_CONFIG

Page: 0xFD (253), Address: 0x0C (12)

| Name | Bits | Description |
| --- | --- | --- |
| 14:0 | LEVEL | Number of elements stored in buffer before asserting the iSensor-SPI-Buffer data ready interrupt. Range 0 - BUF_MAX_CNT |
| 15 | TOGGLE | When set, the watermark interrupt output will act as a ~10KHz, 50% duty cycle clock output when the watermark interrupt is triggered. If this bit is cleared, the watermark interrupt output is simply pulled high when triggered. |

The watermark interrupt signal is unique in that it can be configured to act as a static active high interrupt signal, or as a "clock" interrupt signal. The clock mode can be useful for devices which trigger reads from an edge. 

The following capture shows the interrupt behavior with WATERMARK_INT_CONFIG set to 0x8001 (TOGGLE enabled, 1 sample threshold). The attached EVAL-ADIS-FX3 master board is configured to trigger a buffer burst read on the rising edge of DIO2. The iSensor-SPI-Buffer board keeps giving the FX3 master clocks until the buffer is empty, then goes low. Once a new sample has been enqueued from the IMU, another pulse is generated, and clears when the master retrieves the sample.

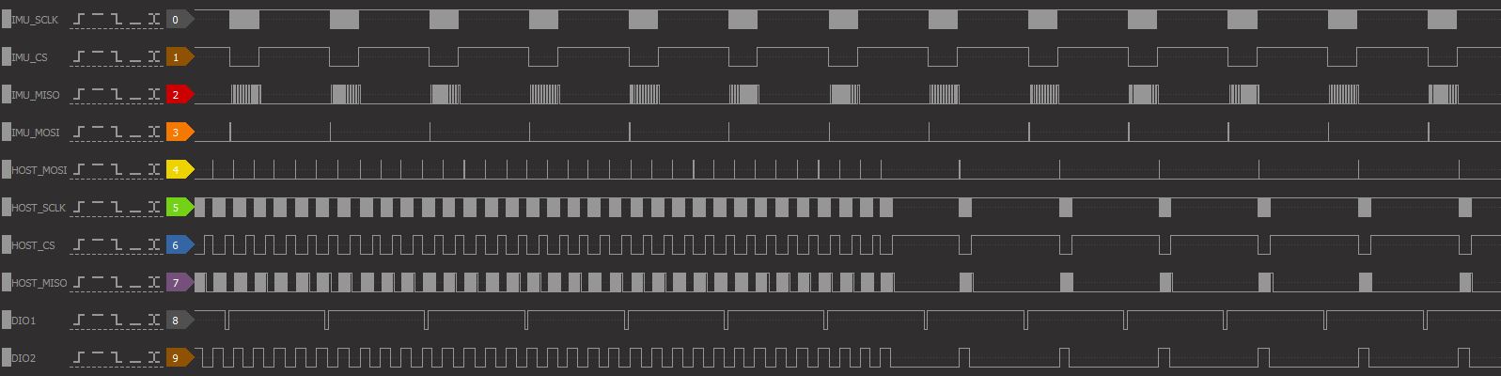
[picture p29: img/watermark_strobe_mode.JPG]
Watermark strobe
 

## ERROR_INT_CONFIG

Page: 0xFD (253), Address: 0x0E (14)

| Name | Bits | Description |
| --- | --- | --- |
| 15:0 | STATUS_MASK | Bitmask to set which bits in the iSensor-SPI-Buffer status register error bits will generate an interrupt when set. Set to 0xFFFF to enable all error interrupts, 0x0000 to disable all. This mask also applies to the error LED on the iSensor-SPI-Buffer, allowing for error detection without reading STATUS. |

## IMU_SPI_CONFIG

Page: 0xFD (253), Address: 0x10 (16)

| Bit | Name | Description |
| --- | --- | --- |
| 7:0 | STALL | Stall time between SPI words (in microseconds). Valid range 2us - 255us |
| 8 | SCLK_SCALE_2 | Sets SCLK prescaler to 2 (18MHz) |
| 9 | SCLK_SCALE_4 | Sets SCLK prescaler to 4 (9MHz) |
| 10 | SCLK_SCALE_8 | Sets SCLK prescaler to 8 (4.5MHz) |
| 11 | SCLK_SCALE_16 | Sets SCLK prescaler to 16 (2.25MHz) |
| 12 | SCLK_SCALE_32 | Sets SCLK prescaler to 32 (1.125MHz) |
| 13 | SCLK_SCALE_64 | Sets SCLK prescaler to 64 (562.5KHz) |
| 14 | SCLK_SCALE_128 | Sets SCLK prescaler to 128 (281.25KHz) |
| 15 | SCLK_SCALE_256 | Sets SCLK prescaler to 256 (140.625KHz) |

The default IMU_SPI_CONFIG value provides an SCLK of 1.125MHz with a stall of 15us. This configuration limits SPI throughput, but should work with all iSensor IMU products. The SPI settings should generally be adjusted to ensure best throughput based on the device in use.

## USER_SPI_CONFIG

Page: 0xFD (253), Address: 0x12 (18)

| Bit | Name | Description |
| --- | --- | --- |
| 0 | CPHA | SPI clock phase |
| 1 | CPOL | SPI clock polarity |
| 2 | MSB_FIRST | 1 = transmit MSB first, 0 = transmit LSB first |
| 7:3 | RESERVED | Currently unused |
| 15:8 | KEY | The KEY field must be set to 0xA5 for a write to USER_SPI_CONFIG to be processed. Any other value will result in the write being rejected, and no change made to the user SPI port functionality. This prevents inadvertent changing of the SPI mode |

## CLI_CONFIG

Page: 0xFD (253), Address: 0x14 (20)

| Bit | Name | Description |
| --- | --- | --- |
| 0 | USB_STREAM | USB data stream running (stream command received). If SD_STREAM is set this bit will be cleared (USB streams have lower priority). This bit is volatile (cannot be set in flash). |
| 1 | SD_STREAM | SD card data stream running (stream command executed as part of SD script execution process). SD card data streams have priority over a USB CLI stream. This bit is volatile (cannot be set in flash). |
| 2 | USB_ECHO_DISABLE | Disable command echo to USB CLI. By default, all characters sent to the CLI input are echoed to the output. Disabling this functionality allows for easier CLI scripting from a host device (don't have to discard command echo back after transmitting a command). |
| 3 | SCRIPT_AUTORUN | Start executing an SD card script automatically after the iSensor-SPI-Buffer firmware has finished initialization. This is equivalent to sending a SCRIPT START command immediately after the initialization process has finished |
| 7:4 | RESERVED | Currently unused |
| 15:8 | DELIM | Register read value delimiter character, in ASCII, for the CLI. Defaults to space character |

For more details on the iSensor-SPI-Buffer USB CLI, see the [USB_CLI](https://github.com/ajn96/iSensor-SPI-Buffer/blob/master/markdown/USB_CLI.md) document

For more details on the iSensor-SPI-Buffer SD Card data logging CLI, see the [SD Scripts](https://github.com/ajn96/iSensor-SPI-Buffer/blob/master/markdown/SD_SCRIPTS.md) document

## USER_COMMAND

Page: 0xFD (253), Address 0x16 (22)

| Bit | Name | Description |
| --- | --- | --- |
| 0 | CLEAR_BUF | Clears any stored buffer contents |
| 1 | CLEAR_FAULT | Clears any fault data logged in flash memory. Until this command is run, status FAULT bit will never clear |
| 2 | FACTORY_RESET | Restores firmware to a factory default state. This command only changes register values in SRAM - to permanently save settings a flash update command must also be issued |
| 3 | FLASH_UPDATE | Save all non-volatile registers to flash memory. The saved values will be persistent through reset events until another flash update command is issued |
| 4 | PPS_ENABLE | Enable PPS timestamp synchronization. Must have PPS_SELECT defined before enabling PPS. The UTC timestamp will start counting up on the next PPS signal |
| 5 | PPS_DISABLE | Disable PPS timestamp synchronization. The microsecond timestamp register will continue free running |
| 6 | SCRIPT_START | Start executing a script from a connected SD card. The script will be loaded from the script.txt file in an attached FAT32 formatted SD card. If any error occurs nothing will be executed, and a script error will be flagged in the STATUS register. In addition, a detailed error will be reported to SCRIPT_ERROR |
| 7 | SCRIPT_CANCEL | Cancel a running script, close any open SD card files, and unmount the SD card file system |
| 8 | WATERMARK_SET | Automatically set the watermark interrupt level for ideal stream operation over the USB command line interface |
| 9 | SYNC_GEN | Start generating sync clock on DIO2_Slave, based on the frequency provided in SYNC_FREQ |
| 12:10 | RESERVED | Currently unused |
| 13 | DFU_REBOOT | Reboot the iSensor-SPI-Buffer into DFU mode. The DFU bootloader stored to ROM will enumerate as an ST USB DFU device which supports firmware updates through the standard ST DFU utility, allowing firmware changes without any external debugger hardware |
| 14 | IMU_RESET | Drive the IMU reset pin low for 1ms, then back high. The user application will have to wait for the reset time of the IMU before reading IMU registers via passthrough. This feature is only implemented on hardware revision C or newer |
| 15 | RESET | Software reset the iSensor-SPI-Buffer firmware |

While commands are being executed, the iSensor-SPI-Buffer slave SPI port is disabled, and all interrupt signals are brought low.

## SYNC_FREQ

Page: 0xFD (253), Address 0x18 (22)

| Bit  | Name | Description |
| ---- | ---- | --- |
| 15:0 | FREQ | The frequency (in Hz) for the sync signal which can be applied to DIO2_Slave |

Sync generation must be started using the SYNC_GEN command. Sync generation can be stopped by writing to DIO_OUTPUT_CONFIG, which will reset the pin to GPIO mode. The generated sync signal has three primary use cases:

* Providing sync signal to connected IMU. For example, proving a 2KHz sync signal to an ADIS1650x will produce better sample timing and stability than using the IMU internal sync source
* Providing reference clock to master system or other device
* Easy standalone testing of the buffer acquisition process. By setting DIO_INPUT_CONFIG to trigger read on DIO2, and setting PIN_PASS for DIO2, the buffer board can trigger itself at a known rate

## USER_SCR_N

Page: 0xFD (253), Address 0x34 - 0x3A (52 - 58)

| Bit | Name | Description |
| --- | --- | --- |
| 15:0 | SCR | User scratch register. Available for end user use |

## UTC_TIME_LWR

Page: 0xFD (253), Address 0x3C (60)

| Bit  | Name | Description |
| ---- | --- | --- |
| 15:0 | UTC_TIME | Lower 16 bits of the 32-bit UTC timestamp |

## UTC_TIME_UPR

Page: 0xFD (253), Address 0x3E (62)

| Bit  | Name | Description |
| ---- | --- | --- |
| 15:0 | UTC_TIME | Upper 16 bits of the 32-bit UTC timestamp |

The UTC timestamp is a 32-bit value which represents the number of seconds since Jan 01 1970. This register must be set by a master device (no RTC). When a PPS input is enabled using the command register PPS_ENABLE bit, and a PPS pin assigned in DIO_INPUT_CONFIG, this register will count up once per PPS interrupt.

Writing to any byte of the 32-bit UTC timestamp will clear the current 32-bit microsecond timestamp (TIMESTAMP).

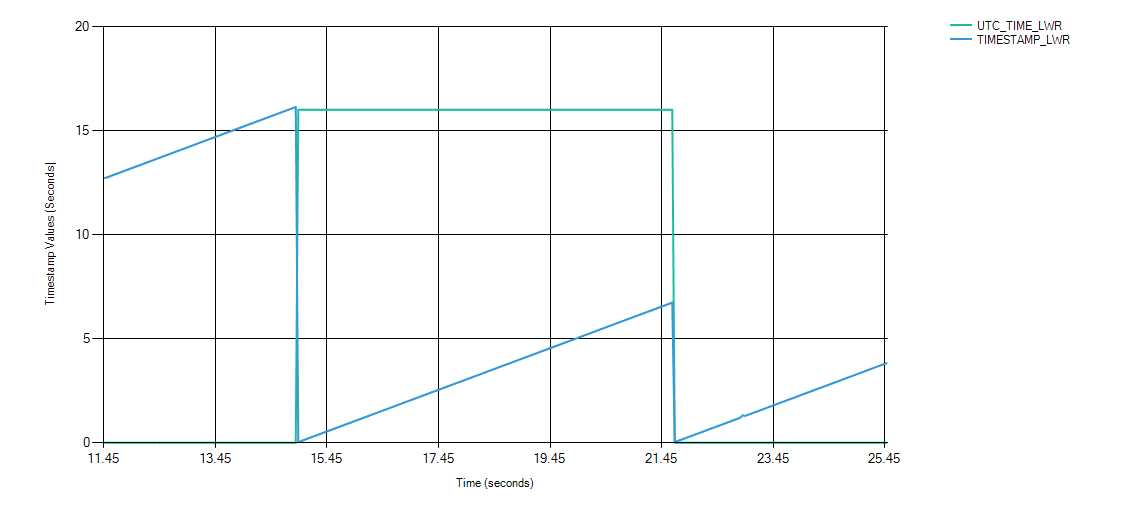
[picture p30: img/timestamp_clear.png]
Timestamp Clear


## STATUS

Page: 0xFD (253), Address 0x40 (64)

Page: 0xFF (255), Address 0x02 (2)

| Bit | Name | Description |
| --- | --- | --- |
| 0 | BUF_WATERMARK | Set when buffer watermark interrupt condition is met (data ready interrupt) |
| 1 | BUF_FULL | Set when buffer is full (overflow interrupt) |
| 2 | SPI_ERROR | SPI error reported by the user SPI or IMU SPI peripheral |
| 3 | SPI_OVERFLOW | User SPI data overflow (min stall time violated). This bit is set when a user SPI interrupt is received, and the previous user SPI interrupt is still being processed |
| 4 | OVERRUN | Data capture overrun. Set when processor receives an IMU data ready interrupt and has not finished the previous data capture |
| 5 | DMA_ERROR | Set when processor DMA peripheral reports an error (user SPI DMA for burst read or IMU SPI DMA) |
| 6 | PPS_UNLOCK | Set when the PPS synchronization clock is enabled, but no PPS signal has been received for over 1100ms. This flag will also set if the measured period of the provided PPS input has an error of greater than 1% |
| 7 | TEMP_WARNING | Set when the SPI buffer internal temperature sensor (value output to TEMP register) measures a value outside the safe operating range [-40C - 85C] |
| 9:8 | RESERVED | Currently unused |
| 10 | SCRIPT_ERROR | Set when there is an error launching a script from an attached SD card. This bit can be set in one of three ways: If there is no attached SD card, if the attached SD card is not formatted correctly or does not contain script.txt, or if script.txt contains invalid script entries. |
| 11 | SCRIPT_ACTIVE | Set by firmware while an SD card script is being executed.  A running script must either terminate by itself, or be cancelled via a SCRIPT_CANCEL command.  Resetting the iSensor-SPI-Buffer while a script is executing may cause data corruption on the SD card. This bit is sticky (does not clear on read) and <u>clears automatically</u> when the script execution process ends. This allows for monitoring of the script execution process via the error interrupt output and error LED |
| 12 | FLASH_ERROR | Set when the register signature stored in flash (stored during flash update) does not match signature calculated from SRAM register contents at initialization. Sticky |
| 13 | FLASH_UPDATE_ERROR | Set when the flash update routine fails. Sticky |
| 14 | FAULT | Set when the processor core generates a fault exception (bus fault, memory fault, hard fault, initialization error). Fault exceptions will force a system reset. Sticky |
| 15 | WATCHDOG | Set when the processor has reset due to a watchdog timeout (2s period). Sticky |

Excluding bits identified as sticky, this register clears on read. The values in this register are used to generate an error interrupt, if error interrupts are enabled.

## FAULT_CODE

Page: 0xFD (253), Address 0x42 (66)

| Bit | Name | Description |
| --- | --- | --- |
| 4:0 | FAULT_SRC | Fault source value. Fault types are defined in flash module https://ajn96.github.io/iSensor-SPI-Buffer/flash_8h.html  |
| 15:5 | RESERVED | Currently unused |

The FAULT_CODE register is stored on a different flash page from the register array. It can only be cleared with a CLEAR_FAULT command.

## BUF_CNT

Page: 0xFD (253), Address 0x44 (68)

Page: 0xFF (255), Address 0x04 (4)

| Bit  | Name | Description |
| ---- | ---- | --- |
| 15:0 | CNT  | Number of entries currently stored in the buffer. Write 0 to clear buffer while on page 255. All other writes ignored |

## BUF_MAX_CNT

Page: 0xFD (253), Address 0x44 (70)

| Name | Bits | Description |
| ---- | ---- | --- |
| 15:0 | MAX  | Total number of entries which can be stored in the buffer. Updates automatically when BUF_LEN is changed |

## TIMESTAMP_LWR

Page: 0xFD (253), Address 0x4A (74)

| Bit | Name | Description |
| --- | --- | --- |
| 15:0 | TIMESTAMP | Lower 16 bits of the 32-bit microsecond timestamp |

## TIMESTAMP_UPR

Page: 0xFD (253), Address 0x4C (76)

| Bit | Name | Description |
| --- | --- | --- |
| 15:0 | TIMESTAMP | Upper 16 bits of the 32-bit microsecond timestamp |

These combined registers form a 32-bit microsecond timestamp which starts counting up as soon as the iSensor-SPI-Buffer firmware finishes initialization and enters its cyclic executive loop.

When a pulse per second (PPS) input is enabled using the PPS_ENABLE command, and a PPS pin is assigned in DIO_INPUT_CONFIG, this microsecond timestamp will reset to 0 every time a PPS pulse is received. This PPS functionality allows the iSensor-SPI-Buffer firmware to track the "wall" time with microsecond accuracy and high long term stability (from PPS clock). Since the microsecond timestamp is reset every second, any error accumulation (due to 20ppm crystal) should be minimal.

The plot below shows the UTC_TIME_LWR and TIMESTAMP_UPR register with a 1Hz PPS signal applied. Each time a PPS edge is received, the TIMESTAMP_UPR (and lower, not shown) are reset to 0, and the UTC_TIME_LWR register increments.

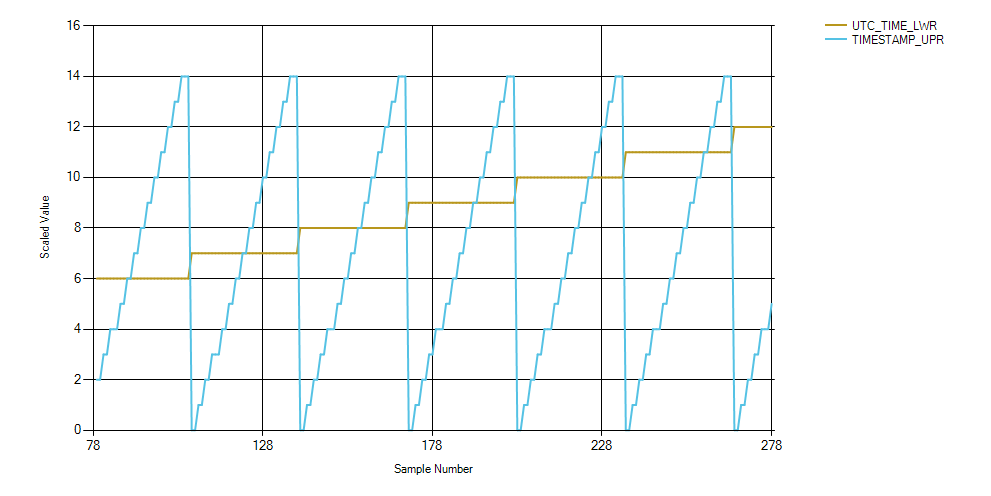
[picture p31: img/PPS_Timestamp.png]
Timestamp Plot


If the PPS signal is lost, the internal microsecond timer will continue counting up, and the STATUS PPS Unlock bit will set. This allows a master device to continue tracking sample timestamps for a significant time even if the PPS signal is lost. The plot below shows that behavior.

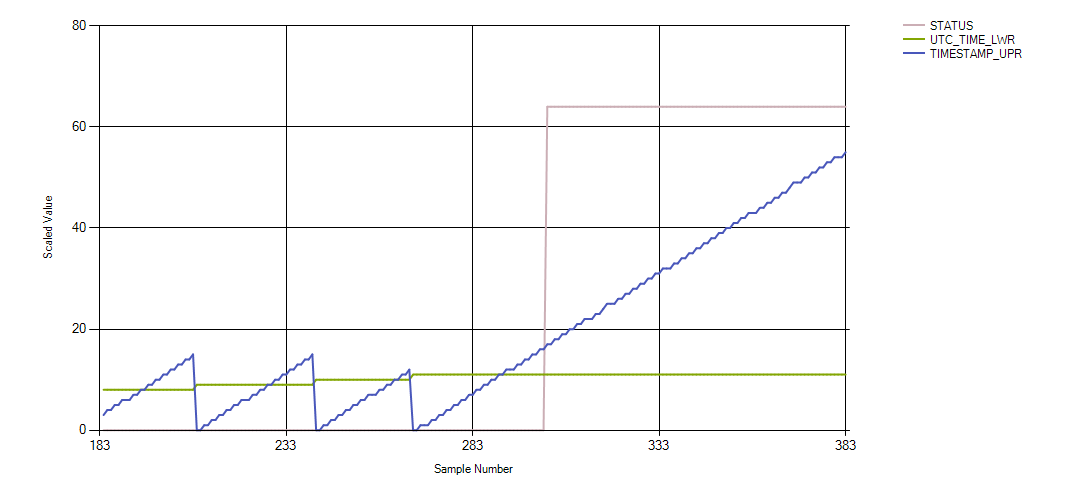
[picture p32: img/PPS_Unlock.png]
PPS Unlock Plot


## TEMP_OUT

Page: 0xFD (253), Address 0x4E (78)

| Bit  | Name | Description |
| ---- | ---- | --- |
| 15:0 | TEMP | Temp sensor output. 1 degree C = 10LSB. Value of 0LSB -> 0C |

This value is sourced from the thermistor embedded in the STM32F303 package. The temperature value is scaled using a two point temperature calibration provided by ST (measurements taken at 30C and 110C). Even though temperature output is calibrated, the measurement is very susceptible to heat from the STM32 processor core. If the temperature measurement ever goes out of range [-40C to 85C] a temperature warning flag will be set in the STATUS register.

The measured value of VDD is used to normalize the TEMP_OUT register value to a 3.3V ADC reference voltage. This normalization ensures good temperature sensor linearity across the valid supply range for the device (TEMP will no longer shift with voltage, as shown [here](https://github.com/ajn96/iSensor-SPI-Buffer/issues/17)). The downside of normalizing the measured temperature value with the measured Vdd value is that the noise of the temp sensor measurement increases, but this is an acceptable tradeoff.

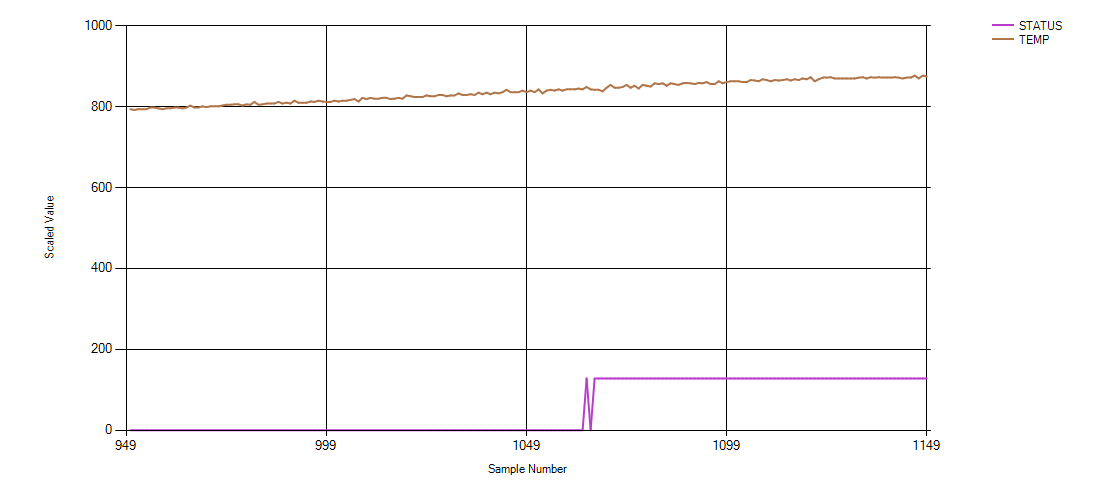
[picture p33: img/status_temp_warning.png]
Temp warning plot


## VDD_OUT

Page: 0xFD (253), Address 0x50 (80)

| Bit  | Name | Description |
| ---- | ---- | --- |
| 15:0 | VDD  | Measured Vdd output. 1V = 100LSBs (3.3V -> 330) |

The value of Vdd is calculated by measuring the value of VREFINT (internal regulated voltage reference) using the ADC and comparing against the expected measurement, with Vdd = 3.3V. Changes in Vdd (VREF) will cause an apparent change in the VREFINT measurement, which can be used to calculate Vdd. 

## SCRIPT_LINE

Page: 0xFD (253), Address 0x64 (100)

| Bit  | Name | Description |
| ---- | ---- | --- |
| 15:0 | LINE | Line number in the provided SD card script (script.txt) which is currently being executed by the script execution engine. Will be set to zero when there is no script running. |

The image below shows the script line number value as a simple script executes:

`sleep 1f4`

`sleep 3e8`

`sleep 5dc`

`sleep 1f4`

`sleep 3e8`

`sleep 5dc`

`sleep 1f4`

`sleep 3e8`

`sleep 5dc`

Script Execution

## SCRIPT_ERROR

Page: 0xFD (253), Address 0x66 (102)

| Bit  | Name | Description |
| ---- | --- | --- |
| 0 | NO_SD | Set when a script start command is processed and there is no SD card attached. This is determined using the SD card detect pin. When this condition is detected, the script start process is aborted. |
| 1 | MOUNT_ERROR | Set when the FAT file system fails to mount the SD card during the script setup process. When this condition is detected, the script start process is aborted. |
| 2 | SCRIPT_OPEN_ERROR  | Set when the software cannot open "script.txt" in read only mode during the script setup process. When this condition is detected, the script start process is aborted. |
| 3 | RESULT_OPEN_ERROR  | Set when the software cannot open "result.txt" in write mode during the script setup process. When this condition is detected, the script start process is aborted. |
| 4 | PARSE_INVALID_CMD  | Set when the software opens script.txt for parsing, but one of the lines contains an invalid command. When this condition is detected, the script start process is aborted. |
| 5 | PARSE_INVALID_ARGS | Set when the software opens script.txt for parsing and detects a valid command with invalid arguments provided. When this condition is detected, the script start process is aborted. |
| 6 | PARSE_INVALID_LOOP | Set when the software opens script.txt for parsing and detects an invalid loop structure. Loops have a fixed loop count, and cannot be nested. When this condition is detected, the script start process is aborted. |
| 7 | WRITE_FAIL | Set when a running script tries to write data to the output file and gets an error. This error does not stop the script execution process. |
| 15:8 | RESERVED | Currently unused |

The script error register is set to 0 when a script start or cancel command is received. Any errors which occur during the script load, parse, and execution process are bit or'd into this register.

## FW_REV

Page: 0xFD (253), Address 0x6E (110)

| Bit  | Name  | Description |
| ---- | ----- | --- |
| 7:0  | MINOR | Minor firmware revision number, in BCD |
| 14:8 | MAJOR | Major firmware revision number, in BCD (second digit limited to 7, giving max possible firmware rev 79.99) |
| 15 | DEBUG | Set if the running firmware was compiled with debug flags enabled. The recommended way to use the iSensor-SPI-Buffer firmware is in release mode (DEBUG = 0). |

This rev corresponds to the release tag for the firmware. For example, rev 1.15 would be represented by 0x0115 in FW_REV.

## FW_DAY_MONTH

Page: 0xFD (253), Address 0x70 (112)

| Bit | Name | Description |
| --- | --- | --- |
| 7:0 | MONTH | Firmware program month, in BCD |
| 15:8 | DAY | Firmware program day, in BCD |

For example, April 24th would be represented by 0x2404. The DAY/MONTH/YEAR values are generated automatically at compile time using the C DATE preprocessor macro. 

## FW_YEAR

Page: 0xFD (253), Address 0x72 (114)

| Bit | Name | Description |
| --- | --- | --- |
| 15:0 | YEAR | Firmware program year, in BCD |

For example, the year 2020 would be represented by 0x2020. The DAY/MONTH/YEAR values are generated automatically at compile time using the C DATE preprocessor macro. 

## DEV_SN_N

Page: 0xFD (253), Address 0x74 - 0x7E (116 - 126)

| Bit | Name | Description |
| --- | --- | --- |
| 15:0 | SN | These six registers contain the 96 bit unique serial number in the STM32 processor core |

## BUF_WRITE_N

Page: 0xFE (254), Address 0x12 - 0x50 (18 - 80)

| Bit | Name | Description |
| --- | --- | --- |
| 15:0 | WRITE_N | Write data to transmit on MOSI line while capturing a buffered data entry |

## FLASH_SIG_DRV

Page: 0xFE (254), Address 0x7C (124)

| Bit | Name | Description |
| --- | --- | --- |
| 15:0 | CHKSUM | Derived signature for all registers stored to flash memory. This value is determined at initialization and compared to "FLASH_SIG" to determine if flash memory contents are valid |

## FLASH_SIG

Page: 0xFE (254), Address 0x7E (126)

| Bit | Name | Description |
| --- | --- | --- |
| 15:0 | CHKSUM | Signature for all registers stored to flash memory. This value is stored in flash, and is updated when a flash update command is executed |

## BUF_RETRIEVE

Page: 0xFF (255), Address 0x06 (6)

| Bit | Name | Description |
| --- | --- | --- |
| 15:0 | RETRIEVE | Read to place a new sample from the buffer into the BUF_READ output registers. Will always contain 0 |

## BUF_UTC_TIME_LWR

Page: 0xFF (255), Address 0x08 (8)

| Bit | Name | Description |
| --- | --- | --- |
| 15:0 | TIMESTAMP | Lower 16 bits of the 32-bit buffer entry UTC timestamp value which is stored at the start of each data capture. Resolution: 1LSB = 1 second (driven by PPS input) |

## BUF_UTC_TIME_UPR

Page: 0xFF (255), Address 0x0A (10)

| Bit | Name | Description |
| --- | --- | --- |
| 15:0 | TIMESTAMP | Upper 16 bits of the 32-bit buffer entry UTC timestamp. |

## BUF_TIMESTAMP_LWR

Page: 0xFF (255), Address 0x0C (12)

| Bit | Name | Description |
| --- | --- | --- |
| 15:0 | TIMESTAMP | Lower 16 bits of a 32-bit buffer entry timestamp value which is stored at the start of each data capture. Resolution: 1LSB = 1us |

## BUF_TIMESTAMP_UPR

Page: 0xFF (255), Address 0x0E (14)

| Bit | Name | Description |
| --- | --- | --- |
| 15:0 | TIMESTAMP | Upper 16 bits of a 32-bit buffer entry timestamp. |

## BUF_SIG

Page: 0xFF (255), Address 0x10 (16)

| Bit | Name | Description |
| --- | --- | --- |
| 15:0 | SIGNATURE | Buffer signature. This is the sum of all 16-bit words stored in the buffer (including timestamp) |

## BUF_DATA_N

Page: 0xFF (255), Address 0x12 - 0x50 (18 - 80)

| Bit | Name | Description |
| --- | --- | --- |
| 15:0 | READ_N | Read data received on the MISO line while capturing a buffered data entry |

# Buffer Burst Output

Burst output functionality for buffered data is provided to allow faster dequeuing of accumulated buffer entries over the user SPI port. Each burst buffer output includes all the data from a single buffer entry, and can be read without toggling chip select, allowing for significantly faster throughput. In addition, the data is moved from the buffer output register to the user SPI port using a DMA peripheral, which offloads work from the CPU. This potentially allows for higher IMU data rates, without experiencing overrun. 

### Triggering a buffer burst read

* First, the BUF_BURST bit must be set in the BUF_CONFIG register. If this bit is not set, all buffered data must be read in register mode (16-bit SPI transactions for each word read)
* The iSensor-SPI-Buffer firmware needs to be set to page 255 (to start the buffered data capture process)
* Once at least one IMU data sample has been accumulated in the buffer, reading the BUF_RETRIEVE register will set up the first buffer burst output (send 0x0600 to the iSensor-SPI-Buffer in a single 16 bit word)
  * Note: To simplify the interface code for the master device, it is possible to make the first read of BUF_RETRIEVE be a "burst" read (SPI word of length BUF_LEN + 12 bytes). The extra data clocked back after sending the first BUF_RETRIEVE read request will not contain valid data however.
* After sending the first BUF_RETRIEVE read request, the following SPI word must be BUF_LEN + 12 bytes long, to receive an entire buffer entry. To chain a second burst read, the master device must transmit 0x0600 (read of BUF_RETRIEVE) to the iSensor-SPI-Buffer in the first two bytes of the SPI word (effectively requesting another buffer burst output). If a read request for BUF_RETRIEVE is not sent, the first two bytes from the burst are processed as a standard SPI command, and the user SPI port is placed back in 16-bit register mode.

### Buffer burst data format

| SPI Word Number (16 bit words) | Master -> iSensor-SPI-Buffer | iSensor-SPI-Buffer -> Master |
| --- | --- | --- |
| 0 | 0x0600 | BUF_CNT (after dequeue) |
| 1 | 0x0000 (Don't care) | BUF_UTC_TIME_LWR |
| 2 | 0x0000 (Don't care) | BUF_UTC_TIME_UPR |
| 3 | 0x0000 (Don't care) | BUF_TIMESTAMP_LWR |
| 4 | 0x0000 (Don't care) | BUF_TIMESTAMP_UPR |
| 5 | 0x0000 (Don't care) | BUF_SIG |
| 6 | 0x0000 (Don't care) | BUF_DATA_0 |
| n | 0x0000 (Don't care) | BUF_DATA_N |

The image below shows the buffer burst output format with BUF_LEN set to 8 bytes, and the IMU MOSI wired to IMU MISO (BUF_WRITE[n] -> BUF_DATA[n]). The UTC timestamp was set to 0x56781234.

User Burst

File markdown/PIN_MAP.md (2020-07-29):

# iSensor-SPI-Buffer STM32 Pin Mapping

**Slave SPI Interface (to host microprocessor)**

| Pin Name | STM32 Pin | Description |
| --- | --- | --- |
| CS_Slave | PB12 | Chip select signal. Bring low to select the iSensor-SPI-Buffer for communications. This pin is an input for the iSensor-SPI-Buffer |
| SCLK_Slave | PB13 | SPI clock signal. This pin is an input for the iSensor-SPI-Buffer |
| MISO_Slave | PB14 | Master in slave out (MISO) signal. This pin is an output from the iSensor-SPI-Buffer |
| MOSI_Slave | PB15 | Master out slave in (MOSI) signal. This pin is an input for the iSensor-SPI-Buffer |

**Master SPI Interface (to IMU)**

| Pin Name | STM32 Pin | Description |
| --- | --- | --- |
| CS_Master | PA4 | Chip select signal, used to enable the IMU slave SPI interface. This pin is an output from the iSensor-SPI-Buffer |
| SCLK_Master | PA5 | SPI clock signal. This pin is an output from the iSensor-SPI-Buffer |
| MISO_Master | PA6 | Master in slave out (MISO) signal. This pin is an input for the iSensor-SPI-Buffer |
| MOSI_Master | PA7 | Master out slave in (MOSI) signal. This pin is an output from the iSensor-SPI-Buffer |

The IMU reset pin is mapped to PA3 (hardware rev C or newer)

**SPI 3 (master to communicate with SD card/etc)**

| Pin Name | STM32 Pin | Description |
| --- | --- | --- |
| CS_SD | PA15 | Chip select signal |
| SCLK_SD | PC10 | SPI clock signal |
| MISO_SD | PC11 | Master in slave out (MISO) signal |
| MOSI_SD | PC12 | Master out slave in (MOSI) signal |

SW_SD (SD card detect line) is mapped to PD2

**DIO / ADG1611 Control**

| Pin Name | STM32 Pin | Description |
| --- | --- | --- |
| DIO1_Master | PB5 | DIO1 input signal from IMU to iSensor-SPI-Buffer |
| DIO2_Master | PB9 | DIO2 input signal from IMU to iSensor-SPI-Buffer |
| DIO3_Master | PC6 | DIO3 input signal from IMU to iSensor-SPI-Buffer |
| DIO4_Master | PA9 | DIO4 input signal from IMU to iSensor-SPI-Buffer |
| DIO1_Slave | PB4 | DIO1 output signal from iSensor-SPI-Buffer to master |
| DIO2_Slave | PB8 | DIO2 output signal from iSensor-SPI-Buffer to master |
| DIO3_Slave | PC7 | DIO3 output signal from iSensor-SPI-Buffer to master |
| DIO4_Slave | PA8 | DIO4 output signal from iSensor-SPI-Buffer to master |
| SW_IN1 | PB6 | Switch control from iSensor-SPI-Buffer. If set DIO1 will be directly passed from master to IMU |
| SW_IN2 | PB7 | Switch control from iSensor-SPI-Buffer. If set DIO2 will be directly passed from master to IMU |
| SW_IN3 | PC8 | Switch control from iSensor-SPI-Buffer. If set DIO3 will be directly passed from master to IMU |
| SW_IN4 | PC9 | Switch control from iSensor-SPI-Buffer. If set DIO4 will be directly passed from master to IMU |

**LED Control**

| Pin Name | STM32 Pin | Description |
| --- | --- | --- |
| LED_RED | PC0 | Output signal from iSensor-SPI-Buffer which drives a red LED |
| LED_GREEN | PC1 | Output signal from iSensor-SPI-Buffer which drives a green LED |

**ID Pins**

| Pin Name | STM32 Pin | Description |
| --- | --- | --- |
| ID0 | PC2 | Identifier pin 0. These pins can be populated with a pull up/down to differentiate between different hardware configurations (e.g. SD card, etc) |
| ID1 | PC3 | Identifier pin 1 |

Dev Board Pin Map

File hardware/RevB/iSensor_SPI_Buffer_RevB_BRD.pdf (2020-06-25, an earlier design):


6/25/2020 7:21 PM f=2.00 C:\Users\Juan\Nextcloud\Eagle\projects\ADI\iSensor SPI Buffer\iSensor_SPI_Buffer_RevB.brd

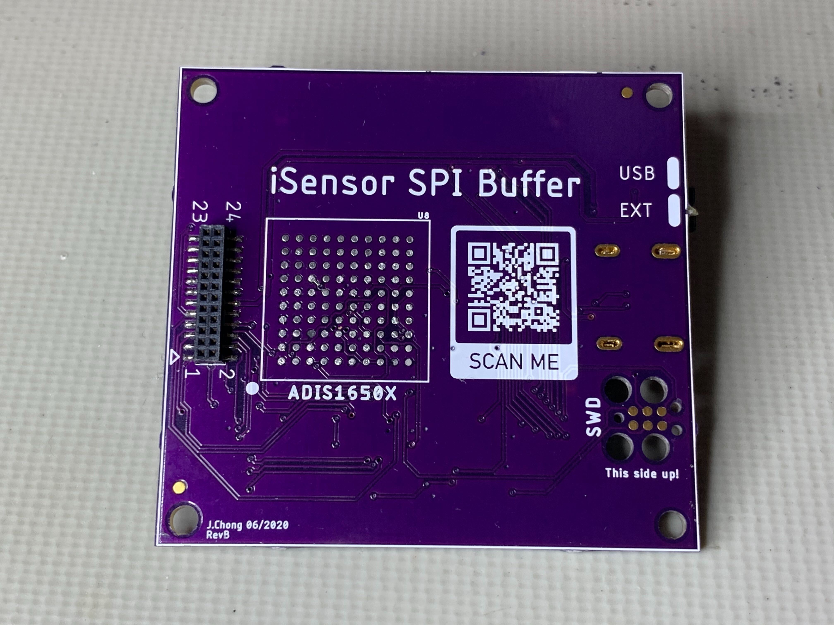
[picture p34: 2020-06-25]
img/top_image.jpg

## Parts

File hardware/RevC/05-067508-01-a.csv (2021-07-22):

TITLE: Bill of Materials
BOM NO: 05-067508-01-a.csv
DATE: 04/23/2021
DESIGN: 02_067508a_top
TEMPLATE: Z:\allegro\v172_site\cdssetup\template.bom
CALLOUT:
ITEM# | Qty | WW_PN | DESCRIPTION | VALUE | JEDEC_TYPE | TOL | VOLTAGE | WATTAGE | LOCATION | MFG | MFG_PN | HLM_STATUS | STOCKROOM_WL | STOCKROOM_GT | STOCKROOM_LK | STOCKROOM_GBO | STOCKROOM_NSH | CUSTOM_PART | DNI
1 | 1 | 08_067438a | PCB | ? | ? | ? | ? | ? | ? | Analog Devices Supplied | 08_067438a | N/A | ? | ? | ? | ? | ? | ? | ?
2 | 9 | E025746 | CAP CER 0.1uF 50V 10% X5R 0402 | 0.1uF | C0402 | 10 | 50V | N/A | C1,C2,C8,C10,C11,C12,C13,C14,C15 | MURATA | GRM155R61H104KE19D | REL | N/A | N/A | N/A | N/A | N/A | ? | ?
3 | 1 | E007203 | CAP CER 0.01uF 25V 10% X8R 0402 | 0.01uF | C0402 | 10 | 25V | N/A | C16 | TDK | C1005X8R1E103K | REL | A004-0011-086 | 40302JH399 | N/A | N/A | 7001959 | ? | ?
4 | 1 | E018707 | CAP CER 0.1uF 16V 10% X7R 0402 | 0.1uF | C0402 | 10 | 16V | N/A | C17 | KEMET | C0402C104K4RACTU | REL | N/A | N/A | N/A | N/A | 7002106 | ? | ?
5 | 2 | E022190 | CAP CER 4.7uF 16V 10% X6S 0603 | 4.7uF | C0603 | 10 | 16V | N/A | C3,C5 | MURATA | GRM188C81C475KE11D | REL | N/A | N/A | N/A | N/A | N/A | ? | ?
6 | 1 | E020410 | CAP CER 0.01uF 25V 5% X7R 0402 | 0.01uF | C0402 | 5 | 25V | N/A | C4 | KEMET | C0402C103J3RACTU | REL | N/A | N/A | N/A | N/A | N/A | ? | ?
7 | 2 | E007476 | CAP CER 18pF 50V 5% C0G 0402 | 18pF | C0402 | 5 | 50V | N/A | C6,C7 | MURATA | GJM1555C1H180JB01D | REL | ADD_TO_STOCK_246 | N/A | N/A | 1572_CAB3 | 7002671 | ? | ?
8 | 1 | E026618 | CAP CER 1uF 25V 10% X5R 0402 | 1uF | C0402 | 10 | 25V | N/A | C9 | TDK | C1005X5R1E105K050BC | REL | N/A | N/A | N/A | N/A | N/A | ? | ?
9 | 1 | E049966 | LED GREEN CLEAR CHIP SMD, 571NM | LTST-S270KGKT | LEDSML63W24H49 | N/A | 2V | 3/40W | DS1 | LITE-ON TECHNOLOGY | LTST-S270KGKT | REL | N/A | N/A | N/A | N/A | N/A | ? | ?
10 | 1 | E049965 | LED RED CLEAR CHIP SMD , 621NM | LTST-S270EKT | LEDSML63W24H49 | N/A | 2V | 1/10W | DS2 | LITE-ON TECHNOLOGY | LTST-S270EKT | REL | N/A | N/A | N/A | N/A | N/A | ? | ?
11 | 1 | E025013 | MOD USB TYPE-C CONNECTOR | DX07S024JJ3 | MDX07S024JJ3 | N/A | N/A | N/A | J1 | JAE (JAPAN AVIATION ELECTRONICS) | DX07S024JJ3 | REL | N/A | N/A | N/A | N/A | N/A | ? | ?
12 | 1 | E034453 | CONN-PCB MICRO-SD CARD SKT, NONE PUSH TOP MOUNT | 114-00841-68 | CNAMP114-00841-68 | N/A | N/A | N/A | P1 | AMPHENOL | 114-00841-68 | REL | N/A | N/A | N/A | N/A | N/A | ? | ?
13 | 1 | E034396 | CONN-PCB 24POS RUGGED RELIABLE MICRO SKT, FEMALE DUAL ROW, 1MM PITCH, WITH ALIGNMENT PIN | CLM-112-02-LM-D-A | CNSMFHDR2X12L485W100H91 | N/A | N/A | N/A | P2 | SAMTEC INC. | CLM-112-02-LM-D-A | REL | N/A | N/A | N/A | N/A | N/A | ? | ?
14 | 1 | E021619 | CONN-PCB TAG-CONNECT IN CKT CABLE WITH RJ12 MODULAR PLUG | TC2030-MCP-NL | CNTAGTC2030-MCP-NL | N/A | N/A | N/A | P6 | TAG-CONNECT,LLC | TC2030-MCP-NL | REL | N/A | N/A | N/A | N/A | N/A | ? | ?
15 | 1 | E049971 | CONN-PCB 5POS DISCONNECTABLE INSULATION DISPLACEMENT HDR, 1MM PITCH SIDE ENTRY | SM05B-SRSS-TB(LF)(SN) | CNJSTSM05B | N/A | N/A | N/A | P7 | JST | SM05B-SRSS-TB(LF)(SN) | REL | N/A | N/A | N/A | N/A | N/A | ? | ?
16 | 1 | E049733 | CONN-PCB 3POS UNSHROUDED HDR RA 2MM PITCH | MMT-103-01-L-SH-P | CNSMHDR1X3L236W79H84 | N/A | N/A | N/A | P8 | SAMTEC INC. | MMT-103-01-L-SH-P | REL | N/A | N/A | N/A | N/A | N/A | ? | ?
17 | 1 | E049735 | CONN-PCB 24POS BOARD STACKER HDR 1MM PITCH | MW-12-03-H-D-130-112-A | CNSMMHDR2X12L472W125H315 | N/A | N/A | N/A | P9 | SAMTEC INC. | MW-12-03-H-D-130-112-A | REL | N/A | N/A | N/A | N/A | N/A | ? | ?
18 | 1 | E049741 | TRAN P-CHANNEL MOSFET 20V 4.3A | DMP2045U | SOT23_B | N/A | -20V | N/A | Q1 | DIODES INCORPORATED | DMP2045U-7 | REL | N/A | N/A | N/A | N/A | N/A | ? | ?
19 | 2 | E024499 | RES SMD 22 Ohm 1% 1/20W 0201 | 22 | R0201 | 1 | 15V | 1/20W | R1,R4 | SUSUMU CO, LTD | RR0306R-220-F | REL | N/A | N/A | N/A | N/A | N/A | ? | ?
20 | 2 | E034346 | RES SMD 330 Ohm 1% 1/20W 0201 | 330 | R0201 | 1 | N/A | 1/20W | R10,R12 | PANASONIC | ERJ-1GNF3300C | REL | N/A | N/A | N/A | N/A | N/A | ? | ?
22 | 1 | E003751 | RES SMD 10K Ohm 1% 1/10W 0402 AEC-Q200 | 10K | R0402 | 1 | N/A | 1/10W | R13 | PANASONIC | ERJ-2RKF1002X | REL | A003-0035-004 | 41816DG719 | N/A | N/A | 7000582 | ? | ?
23 | 1 | E026676 | RES SMD 3.3K Ohm 1% 1/20W 0201 | 3.3K | R0201 | 1 | N/A | 1/20W | R14 | PANASONIC | ERJ-1GNF3301C | REL | N/A | N/A | N/A | N/A | N/A | ? | ?
24 | 3 | E032279 | RES SMD 10K Ohm 5% 1/20W 0201 | 10K | R0201 | 5 | N/A | 1/20W | R6,R15,R16 | PANASONIC | ERJ-1GNJ103C | REL | N/A | N/A | N/A | N/A | N/A | ? | ?
25 | 2 | E007054 | RES SMD 5.1K Ohm 1% 1/20W 0201 | 5.1K | R0201 | 1 | N/A | 1/20W | R2,R3 | PANASONIC | ERJ-1GNF5101C | REL | N/A | N/A | N/A | 1406_CAB3 | 7007835 | ? | ?
26 | 1 | E010371 | RES SMD 1.5K Ohm 5% 1/20W 0201 | 1.5K | R0201 | 5 | 8.66V | 1/20W | R5 | YAGEO | RC0201JR-071K5L | REL | N/A | 41816JH1494 | N/A | N/A | 7005565 | ? | ?
28 | 1 | E032382 | RES SMD 0 Ohm 5% 1/20W 0201 | 0 | R0201 | 5 | N/A | 1/20W | R9 | BOURNS | CR0201-J/-000GLF | REL | N/A | N/A | N/A | N/A | N/A | ? | ?
29 | 1 | E049739 | SWITCH TACTILE NO SPST 0.01A | KMS223GPLFG | SWSML181W140H56 | N/A | 32VDC | N/A | S1 | C&K | KMS223GPLFG | REL | N/A | N/A | N/A | N/A | N/A | ? | ?
30 | 1 | E049740 | IC MCU 32-BIT ARM CORTEX M7 RISC 512KB FLASH 3.3V | STM32F722RE | LQFP64 | N/A | N/A | ? | U1 | ST MICROELECTRONICS | STM32F722RET6 | REL | N/A | N/A | N/A | N/A | N/A | ? | ?
31 | 1 | E006927 | IC-ADI 4/1-CHANNEL MUX | ADG1204YCPZ-500RL7 | QFN12_3X3_PAD1_3X1_3 | N/A | N/A | ? | U2 | ADI | ADG1204YCPZ-500RL7 | REL | A999-1204-001 | 40901DG1081 | N/A | N/A | N/A | ? | ?
32 | 1 | E007976 | IC-ADI LOW DROPOUT CMOS LIN REG | ADP1706ACPZ-3.3 | QFN8_3X3_PAD1_75X1_45 | N/A | 3.3V | ? | U3 | ANALOG DEVICES | ADP1706ACPZ-3.3-R7 | REL | N/A | 40901JH1367 | N/A | N/A | N/A | ? | ?
33 | 1 | E018673 | IC ADI QUAD SPST SWITCHES | ADG1611BCPZ | QFN16_4X4_PAD2_5X2_5 | N/A | N/A | ? | U4 | ANALOG DEVICES | ADG1611BCPZ-REEL | REL | N/A | N/A | N/A | N/A | 1003175 | ? | ?
34 | 1 | E034466 | IC CRYSTAL GLASS SEALING, 18PF LOAD CAPACITANCE 80OHM ESR | 8MEGHZ | YSML197W126H59 | N/A | N/A | N/A | Y1 | TXC CORPORATION | 7A-8.000MAAJ-T | REL | N/A | N/A | N/A | N/A | N/A | ? | ?
The following components are part of the PCB or are NOT to be installed
ITEM# | Qty | WW_PN | DESCRIPTION | VALUE | JEDEC_TYPE | TOL | VOLTAGE | WATTAGE | LOCATION | MFG | MFG_PN | HLM_STATUS | STOCKROOM_WL | STOCKROOM_GT | STOCKROOM_LK | STOCKROOM_GBO | STOCKROOM_NSH | CUSTOM_PART | DNI
21 | 1 | E032382 | RES SMD 0 Ohm 5% 1/20W 0201 | 0 | R0201 | 5 | N/A | 1/20W | R11 | BOURNS | CR0201-J/-000GLF | REL | N/A | N/A | N/A | N/A | N/A | ? | DNI
27 | 1 | E032279 | RES SMD 10K Ohm 5% 1/20W 0201 | 10K | R0201 | 5 | N/A | 1/20W | R8 | PANASONIC | ERJ-1GNJ103C | REL | N/A | N/A | N/A | N/A | N/A | ? | DNI

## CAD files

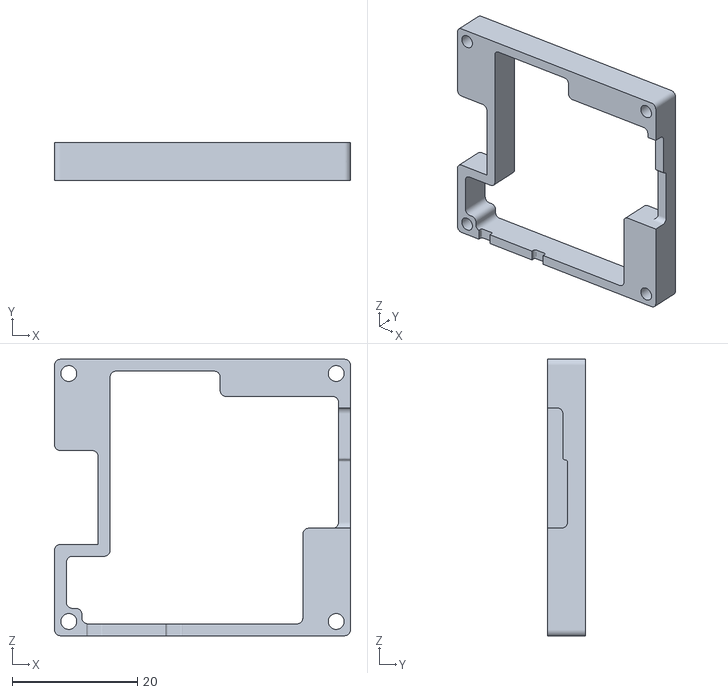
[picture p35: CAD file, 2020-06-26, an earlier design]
hardware/RevB/3d_printable_interposer/SPI-Buffer-Interposer.stl
47.3 x 6.02 x 44.2

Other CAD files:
hardware/RevB/3d_printable_interposer/SPI-Buffer-Interposer.ipt

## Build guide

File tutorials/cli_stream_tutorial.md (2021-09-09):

## Tutorial: Configuring The Buffer Board For Use With An ADIS1649x Module

The SPI Buffer Board includes many features that expand the ADI IMU's capabilities and make interfacing with a Linux environment more accessible. The USB CLI enables users to get started with capturing sensor data very quickly. The virtual serial port (virtual COM port) is compatible with any modern operating system and does not require any additional drivers to operate. This example walks users through configuring both the SPI buffer board and the IMU to stream data to a PC or embedded Linux device. 

### Configuring the SPI Buffer Board Using the CLI

This guide assumes that you've connected the SPI Buffer Board to the PC and opened a terminal connection to the board. The commands shown below should be typed into the console in the order shown. Note that each `write` command is designed to only write 8 bits (one byte) at a time. 

```
write 0 FD	//Change the active page to page 253
write 2 2	//Write to the BUF_CONFIG register - stop sampling when sensor data overflows, enable data capture using the IMU burst mode
write 3 0 	//Upper 8-bits of BUF_CONFIG
write 4 28	//Write the desired buffer size (correct value for ADIS1649x IMUs)
write 5 0 	//Upper 8-bits of BUF_LEN
write 8 12	//Set buffer board data ready polarity to rising edge, set buffer board data ready to DIO2
write 9 0 	//Upper 8-bits of DIO_INPUT_CONFG
write A 2	//Pass DIO2 through to the host SPI connector
write B 0 	//Upper 8-bits of DIO_OUTPUT_CONFIG 
write C 4	//Set the buffer board watermark for 4 samples
write D 0 	//Upper 8-bits of watermark
write 10 5	//Set the IMU SPI to a 5us stall
write 11 8	//Set the IMU SPI SCLK to 2.25MHz

write 0 FE	//Change the active page to page 254
write 12 0	//Write the lower byte of the burst trigger command to the request buffer
write 13 7C	//Write the upper byte of the burst trigger command to the request buffer

cmd 8		// Issue buffer board flash write command - NOTE: issuing this command will commit the current configuration to the buffer board NVM. These settings will be recalled next time the buffer board is powered on.
```

### Configuring the IMU  using the CLI

The following steps outline the minimum configuration required to capture data from an ADIS1649x IMU at a 400Hz data output rate. Additional write commands can be added to the sequence to suit your specific application.

```
write 0 3	//Change the active page to page 3 on the IMU
write 6 D	//Set the data ready output to DIO2
write 7 0 //Upper 8-bits
write C 9	//Set the datarate to 400SPS (Hz)
write D 0 //Upper 8 bits
write 2 8	//Write the lower byte of the IMU flash write command
write 3 0	//Write the upper byte of the IMU flash write command - NOTE: issuing this command will commit the current configuration to the IMU NVM. These settings will be recalled next time the buffer board is powered on
write 0 0	//Set the active IMU to page 0 - NOTE: this step is only necessary when first configuring the IMU and does not need to be performed in subsequent power cycles
```

**NOTE:** If the flash write feature on the SPI Buffer Board and IMU were used as shown above, then the configuration routines <u>do not</u> need to be executed every time at startup. 

**TIP:** The entire contents of a configuration page can be printed to the screen by issuing the following command: 

```
read 0 7F	//Read the entire contents of the active configuration page
```

Each set of four values corresponds to the contents of each 16-bit register. When executed, the output of the command should like this:

CLI Page Read

### Triggering the Data Capture

Once the buffer board and IMU have been configured, issuing the following commands in the order shown will start the data capture sequence and the data stream.

```
stream 1 	//Enable data streaming from buffer
write 0 FF	//Change the active page to page 255 to start capture
```

This will start automatic printing of each buffer sample. To put the data in a CSV format, use the "delim ," command (default delimiter is a space)

Stream Data

### Triggering Data Capture

To stop a data capture, send a "stream 0" command to disable streaming

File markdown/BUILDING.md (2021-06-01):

# Building the iSensor-SPI-Buffer Firmware

The iSensor-SPI-Buffer firmware can be built using the free eclipse-based [STM32Cube IDE](https://www.st.com/en/development-tools/stm32cubeide.html)

For hardware setup instructions for debugging or loading new firmware, see [PROGRAMMING.md](https://github.com/ajn96/iSensor-SPI-Buffer/blob/master/markdown/PROGRAMMING.md)

## Cloning Repo

First, clone the repo locally using the Git client of your choice. The clone link can be found here on the GitHub repo page:

Clone Link

Example git clone command through Git bash:

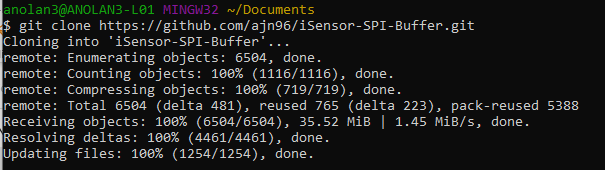
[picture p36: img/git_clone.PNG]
Clone Process


## Importing Project in STM32Cube IDE

Once the repo is cloned locally and STM32CubeIDE is installed, the firmware project can be added to your IDE workspace. Within STM32CubeIDE, select "File" -> "Open Projects from File System":

Add Project

Then browse to the /firmware directory within the iSensor-SPI-Buffer repo:

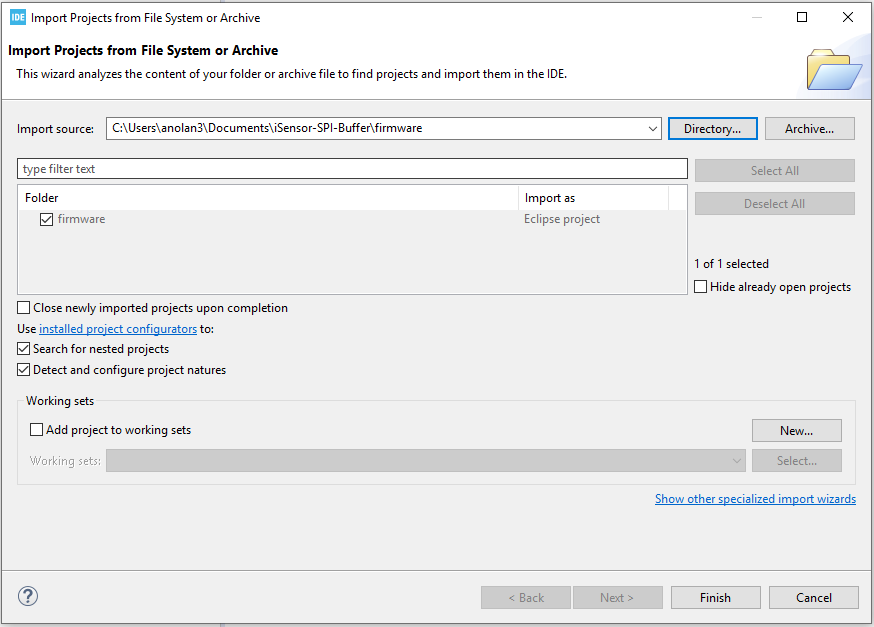
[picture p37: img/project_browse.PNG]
Load Project


After clicking "Finish", the iSensor-SPI-Buffer project should be added to the project explorer menu.

## Building Project

To build the firmware, right click on the iSensor-SPI-Buffer project in the project explorer, then select "build". This will build the active configuration (debug or release). The build result will be printed to the console (bottom of the window by default).

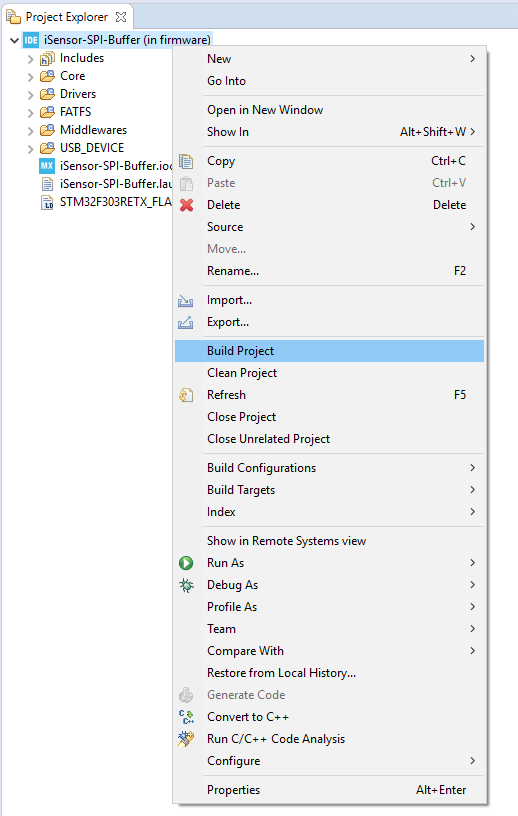
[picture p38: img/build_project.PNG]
Build


To change the selected build configuration (Debug without optimization or Release with optimization) right click and select "Build Configurations" -> "Set Active" -> Debug/Release. Generally, release configuration should be used, unless you are debugging and want to step through the code, in which case Debug should be used. Due to compiler optimizations, debugging with release configuration will produce unexpected/erratic results.

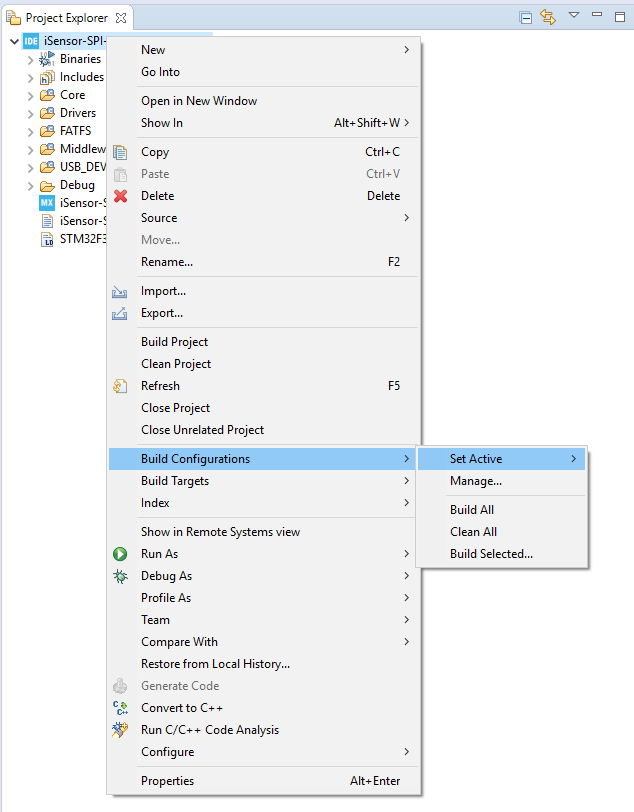
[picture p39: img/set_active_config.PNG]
Set Config


## Loading Code to Hardware

Once the project has been built and the hardware environment is configured as shown in the [programming guide](https://github.com/ajn96/iSensor-SPI-Buffer/blob/master/markdown/PROGRAMMING.md), you can now load code to the iSensor-SPI-Buffer board. To load a release binary to flash, simply drag the Release/iSensor-SPI-Buffer.bin file to the nucleo board device in "This PC". The programmer will enumerate as a drive labeled "NODE_F303".

To debug the code, select "Debug As" -> "Debug Configurations" within the project menu.

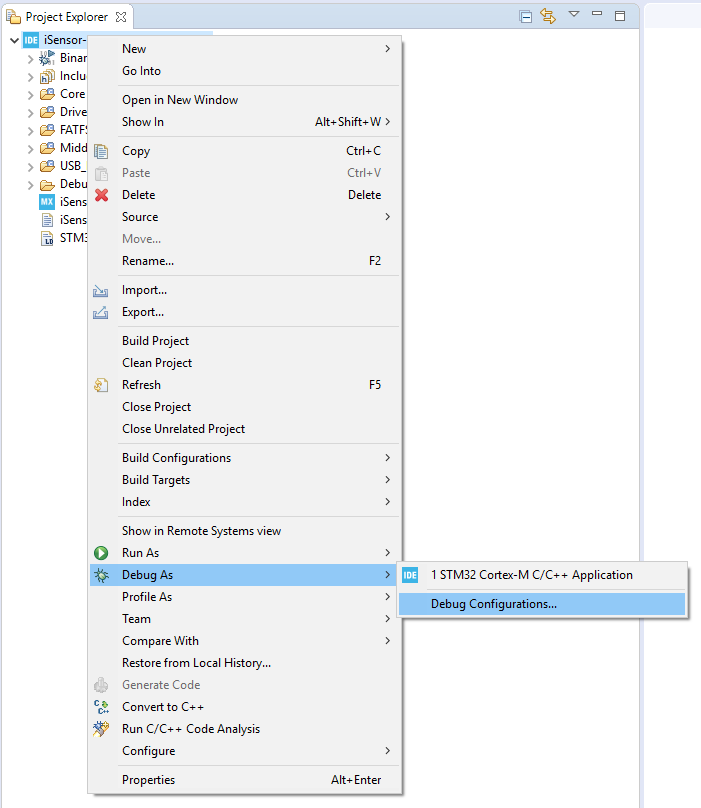
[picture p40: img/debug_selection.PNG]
Debug Config


In the debug configuration menu, select the SWD option and scan for an ST-Link device. If one is detected, the serial number should be populated automatically. Once a ST-Link SN is listed, click "Apply" then "Debug" to start the debug session and begin stepping though code. The code should break at the first line of main() by default. If the IDE shows a warning about "Symbols not found" or the debugger fails to halt at a breakpoint, ensure the active configuration is debug, not release.

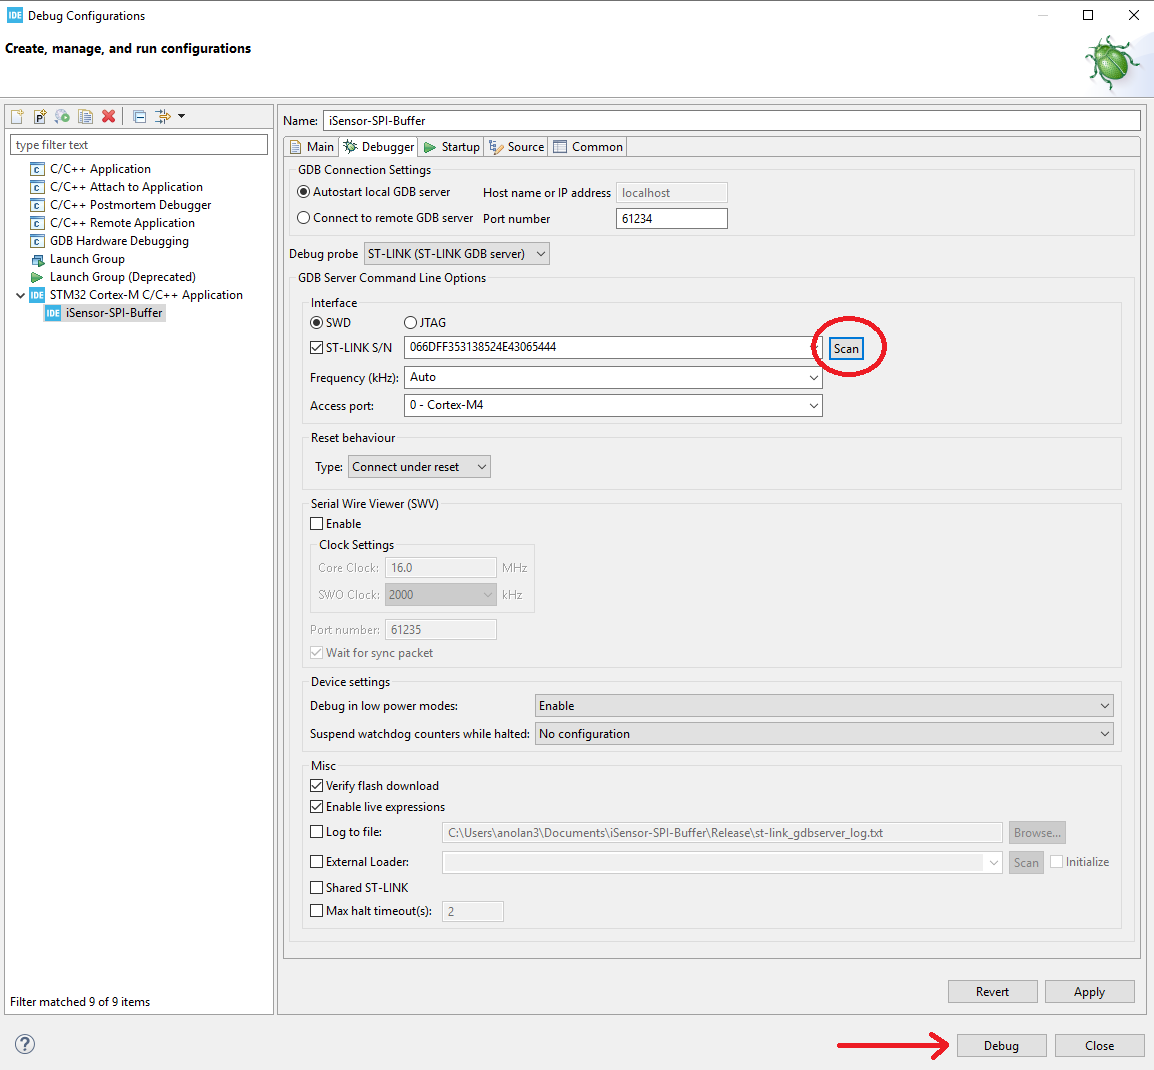
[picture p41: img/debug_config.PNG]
Debug Config Window


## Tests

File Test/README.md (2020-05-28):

# iSensor-SPI-Buffer Test Project

## Software Setup

* These tests use the NUnit 2.6.4 testing framework (bin included in repo) to perform system level testing on the iSensor-SPI-Buffer firmware
* Test cases interface to the iSensor-SPI-Buffer DUT over USB using an [iSensor FX3 Eval Board](https://github.com/juchong/iSensor-FX3-API), via the FX3 API
* Test cases exercise system level functionality of the iSensor-SPI-Buffer firmware and hardware
* The iSensor-SPI-Buffer firmware to be tested must already be loaded and running on the DUT prior to starting the test process - test cases do not cover source code compilation (may be added in the future)

## Hardware Setup

In order for all test cases to function as expected, the iSensor-SPI-Buffer DUT must be connected as follows:
* iSensor-Buffer-SPI Slave SPI port connected to iSensor FX3 master SPI port
* iSensor FX3 DIO1 - DIO4 connected to corresponding iSensor-SPI-Buffer slave DIO1 - DIO4
* iSensor-SPI-Buffer IMU SPI MOSI connected to IMU SPI MISO (for loop back)
* iSensor-SPI-Buffer master DIO1 (would typically be connected to IMU DIO1) connected to FX3_GPIO1 

It is recommended to use an iSensor FX3 eval board with a programable power supply

## Running Tests

After setting up the appropriate hardware/software environment, the test project must be built. This can be done in visual studio by loading the .sln file and compiling, or via msbuild

After the test project is built, test cases can be loaded via the nunit GUI using launcher.bat. Once test cases are loaded into the GUI, they can be run by selecting a test case and clicking "run"

The NUnit test cases can also be executed via command line using the included nunit-console-x86.exe

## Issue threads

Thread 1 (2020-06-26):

Add support for IMU burst data capture

ajn96, 2020-06-26:
Currently, the buffered data capture process only supports "standard" SPI reads to the ADIS IMU. Want to add support for burst reads, to enable better throughput.

ajn96, 2020-07-22:
Implemented. Setting BUF_CONFIG bit 1 will enable a single SPI transaction for all buffer data (burst from IMU). This enables better throughput without data loss by eliminating the per-spi-word interrupt in register mode

Closed 2020-07-22.

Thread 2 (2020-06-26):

Add support for buffer output via burst SPI

ajn96, 2020-06-26:
Allow users to clock out an entire buffer entry in a single SPI transaction using a memory to SPI DMA. This will offload work from the CPU and allow for better buffered data capture throughput.

ajn96, 2020-07-23:
Implemented

Closed 2020-07-23.

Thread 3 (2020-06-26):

Add USB virtual serial port support

ajn96, 2020-06-26:
Virtual serial port will provide a CLI to the same register interface which can be accessed by the SPI port. This will allow data capture directly to a PC, without an intermediary SPI board (like EVAL-ADIS-FX3)

ajn96, 2020-07-01:
Done. See USB CLI documentation

Closed 2020-07-01.

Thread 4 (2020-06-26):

Add SD card data logging capability

ajn96, 2020-06-26:
The iSensor-SPI-Buffer hardware platform has a SD card slot connected to SPI3. Need to develop software support for autonomous data logging to the SD card (for use in battery powered applications without a PC).

juchong, 2020-07-24:
In an effort to prevent data corruption, we might be able to use the [LTC4412](https://www.analog.com/media/en/technical-documentation/data-sheets/4412fb.pdf) to detect power loss and swap over the MCU supply to a supercap backup. The proposed supercap is [CPH3225A-2K](https://www.digikey.com/product-detail/en/seiko-instruments/CPH3225A-2K/728-1067-1-ND/4747400).

ajn96, 2020-08-15:
Software support in progress. Should be mostly done, having issue getting SD card to mount correctly.

ajn96, 2020-10-01:
Finally done!!! Want to resolve USB data corruption issues, then will push a firmware rev 2.0 release with this data logging feature

Closed 2020-10-01.

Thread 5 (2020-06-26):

Inconsistent IMU stall time under heavy SPI load

ajn96, 2020-06-26:
The user SPI interrupt has highest priority in the system. This can cause the IMU SPI transactions to be delayed if they overlap with a user SPI interrupt. However, the timer which drives the IMU SPI transaction period is not delayed, potentially causing a stall time violation on the following transaction.

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

ajn96, 2020-07-15:
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

Resolved by resetting the SPI timing timer to 0 at the start of the SPI word ISR. This ensures that the minimum stall time cannot be violated

Closed 2020-07-21.

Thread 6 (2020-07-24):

Occasional data corruption for high throughput USB stream

ajn96, 2020-07-24:
Sometimes a character will be omitted in a USB stream when the IMU data production rate is too high. Might need to switch to a ping/pong architecture for the USB transmit buffer.

ajn96, 2020-08-10:
Switched to ping/pong which did not resolve the issue. Might need to go look in the USB CDC libraries.

ajn96, 2020-10-05:
I believe this has been resolved. Was a problem in the string formatting

Closed 2020-10-05.

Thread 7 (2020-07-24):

Modify rev C hardware to give buffer board reset control over IMU

ajn96, 2020-07-24:
On Rev A/B of the buffer board, the hardware reset pin only goes to the IMU. This makes it so there is no way to force a hardware reset on the buffer board itself.

A more flexible solution would be to wire the reset output from the master device to the reset input on the buffer board. Then, the IMU reset output can be driven from a GPIO on the buffer board (with a pull up). This gives the flexibility for the buffer board to reset the IMU on demand (via command register bit), and also allows users to reset the buffer board firmware, without power cycle or SPI port access required.

ajn96, 2020-07-31:
Will use PA3 for IMU reset control

ajn96, 2021-04-06:
This has been incorporated into the rev C board design

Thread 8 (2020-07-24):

Add hardware power loss protection

ajn96, 2020-07-24:
SD cards (especially with FAT file system) are very vulnerable to corruption if a file write is not properly terminated (due to power loss).

This vulnerability can be mitigated by placing a high capacitance capacitor on the buffer board supply line (after the 3.3V regulator), and monitoring the input voltage to the cap in software using the STM32 ADC. If the input voltage falls under a low operating threshold, the software can stop any running SD card data logging and safely clean up any open files, before the system loses power.

The STM32F303 can operate with VDD = 2.0V, and SD cards can safely operate with VDD = 2.7V. Powering the buffer board and SD card will require ~50mA of average current. To ensure a consistently safe amount of file cleanup time, VDD must stay above 2.7V for at least 100ms after power is lost.

(3.3V - 2.7V) = 50mA * 100ms / C
C = 8.3 milliFarads to ensure 100ms uptime for SD card + micro

This capacitor (designed as "battery" back up) could work well:
https://www.digikey.com/product-detail/en/seiko-instruments/CPH3225A/728-1127-1-ND/8692445

ajn96, 2020-08-07:
Will probably have to do some bench prototype testing for this feature. May not make it into rev C.

ajn96, 2020-10-01:
This feature might not be needed. Each SD card write syncs immediately, so power loss most of the time will not cause problems

ajn96, 2020-10-09:
Won't do - board does not seem super susceptible to data loss, and button will reduce occurrences of data loss during a script run

Closed 2020-10-09.

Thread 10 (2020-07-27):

Loss of PPS input question

NevadaMark, 2020-07-27:
In the second figure, under the TIMESTAMP_UPR register description, it appears like the period of the last PPS signal is shorter than the previous two pulses, as evidenced by attributes in the UTC_TIME_LWR (time period of the last increment was shorter, when compared to the previous two cycles.
https://github.com/ajn96/iSensor-SPI-Buffer/blob/master/REGISTER_DEFINITION.md#TIMESTAMP_UPR

Could this be indicative of a signal artifact, which came from the act of removing the PPS clock signal?  In other words, did a glitch cause this to trigger sooner than it would have otherwise or is there another reason for the difference in period?  Thank you!

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

ajn96, 2020-07-27:
Hi Mark,

You're correct, the short period on the last PPS input period was likely due to an input glitch when disabling the PPS signal.

The PPS input to the SPI buffer for this image was being generated by an FX3 PWM output (1Hz, 50% duty cycle). When a PWM output is disabled on the FX3, the pin is tri-stated. This caused a low to high transition to be seen by the SPI buffer, which triggered the PPS ISR (DIO_INPUT_CONFIG PPS Polarity bit was set to 0).

Do you think it would be valuable to detect an error like this for the PPS_UNLOCK bit? Currently, this bit is only set when the PPS signal is lost - it would be easy enough to flag an invalid PPS period as well (allowed freq of 1Hz +- 3%).

NevadaMark, 2020-07-27:
Thank you, Alex!
This confirmation helps strengthen my understanding of this function, which by the way, is pretty cool!
With respect to detecting an error, based on the time period, I can imagine that being useful.  What would limit the precision of this detection method?

ajn96, 2020-07-27:
> Thank you, Alex!
> This confirmation helps strengthen my understanding of this function, which by the way, is pretty cool!
> With respect to detecting an error, based on the time period, I can imagine that being useful. What would limit the precision of this detection method?

There are two major limits to the precision of the PPS error detection:
* CPU activity can make interrupt latency (to process PPS edge) somewhat variable. The PPS input has a lower interrupt priority than the user SPI, so if the processor is executing the user SPI ISR when the PPS input comes in the "measured" period could be off by ~1us. In addition, the PPS input shares the same interrupt vector as the IMU data ready, so if an IMU data ready comes in just before the PPS that could push the inaccuracy of the period measurement out further.
* Accuracy of the crystal used to clock the SPI buffer. 20ppm shouldn't drift much over 1 second, but wouldn't want to pull the margins in too close and start reporting false PPS_UNLOCK failures.

Thinking about the possible error sources more now, I suspect I could very safely assert an error if the PPS period is off by +-10ms (1%).

It might be possible to set up another timer peripheral on the ST processor to operate in input capture mode to monitor the PPS input, which would give much more precise and accurate timing measurements.

NevadaMark, 2020-07-28:
Thank you!  Based on what I know so far, +/-1% seems like it would suffice.  Perhaps some applications will value more precise detection, but I am not sure that should be the responsibility of the IMU (which in this context, would include this FIFO/Buffer). I will keep thinking about this, in my research.  Thank you for the education on the capability.

ajn96, 2020-07-28:
Added +- 1% error detection on release 1.3

Closed 2020-07-28.

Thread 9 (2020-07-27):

TIMESTAMP_UPR negative value?

NevadaMark, 2020-07-27:
Should the minimum value of the TIMESTAMP_UPR register be zero or is this a twos complement number?  Thank you!
https://github.com/ajn96/iSensor-SPI-Buffer/blob/master/REGISTER_DEFINITION.md#TIMESTAMP_UPR

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

ajn96, 2020-07-27:
Hi Mark,

The timestamp register is unsigned, 32-bits. The negative is due to an offset applied by the FX3 data plotting GUI by the "autonull" functionality. I had autonulled the plot to make it easier to see both signals.

I'll generate a new plot with the offset set to 0 for the timestamp, to avoid potential confusion.

ajn96, 2020-07-28:
Updated image

Closed 2020-07-28.

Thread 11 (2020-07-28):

TIMESTAMP_UPR Peak Value, when using 1Hz PPS Signal

NevadaMark, 2020-07-28:
If I understand correctly, and TIMESTAMP_UPR and TIMESTAMP_LWR represent a 32-bit counter, which represents the number of microseconds (1us = 0.000001s) since the trigger edge of the PPS signal.   Assuming ideal conditions, that will result in the following value for the TIMESTAMP:

- TIMESTAMP = 0x000F4240 (hexadecimal equivalent of 1000000)
- TIMESTAMP_UPR = 0x000F
- TIMESTAMP_LWR = 0x4240

If TIMESTAMP_UPR should be 0x000F, which represents a decimal of 15, why is the peak value, in this figure, only 14?
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

ajn96, 2020-07-28:
Hi Mark,

This cap at 14 is likely an artifact due to the relatively low sample frequency the plotting for was set to (20Hz). Reading the timestamp registers faster shows results in-line with what we would expect:

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

Running the same plot again with a higher Fs sometimes "catches" the timestamp upper register at 15
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

NevadaMark, 2020-07-28:
Thank you, Alex!
That makes sense. Thank you for running that experiment.
If we divide 10^6 by 65535 (2^16 - 1), we arrive at a nominal value of 15.259.
If we subtract 15 from this number, we arrive at 0.259 is ~1.7% of 15.259 (nominal expectation), which is not far from the +/-1% tolerance that you predicted for the tolerance in detecting clock frequency error (in a separate issue).  Could the combination of accuracy of the PPS signal and accuracy of the measurement method also be contributing to the variation in the count, for each cycle?  Again, many thanks for supporting the discussion!  This is good stuff!

ajn96, 2020-07-29:
Hi Mark,

Sorry for the misunderstanding - the TIMESTAMP_UPR register in the plot above is truly just the upper 16 bits of the microsecond timestamp. The lower 16 bits were not plotted individually because it changes too fast (0 - 65535 every time TIMESTAMP_UPR increments). I guess I should probably set one of the registers up as 32-bit in the regmap!

The measurement variation is just a function of the "slow" plotting utility. For each PPS period, the TIMESTAMP_UPR is only at 15 for ~16ms (0x4240 microseconds) before being reset to 0. The plotter utility only reads the register every 50ms with Fs = 20Hz, so the odds of it "catching" the TIMESTAMP_UPR register at 15 aren't great.

NevadaMark, 2020-07-29:
Hi Alex,
This makes sense to me! Thank you for offering this level of detail and explanation.
Mark

Closed 2020-07-31.

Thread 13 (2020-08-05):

Add test points to enable debugging the IMU-Buffer Board SPI Port

juchong, 2020-08-05:

juchong, 2021-02-05:
The addition of the 16-pin connector should provide a good spot to easily solder in test points.

ajn96, 2021-04-06:
Not currently in the rev C hardware design. Need to decide if test points for the SPI lines are still necessary

ajn96, 2021-07-22:
Rev C board design will not include IMU SPI test points

Closed 2021-07-22.

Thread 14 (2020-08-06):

Add Vdd measurements to output registers

ajn96, 2020-08-06:
Internally the STM32F303 has a regulated low noise reference voltage connected on a single ended ADC input. ST provides the measured value for this reference voltage in NVM (with Vfref+ at 3.3V). By measuring this voltage again at runtime, and comparing the value to the reference measurement, the Vdd (used for Vref+) voltage can be determined implicitly. The scaled Vdd voltage can be placed in the output register array, to alert users of potential voltage drop or supply issues.

ajn96, 2020-08-15:
Set up scaling logic, still need to configure ADC to actually read both values (temp + VREFINT). Might use DMA or a state machine and just check from main loop, not sure.

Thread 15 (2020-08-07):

Add watermark interrupt strobe functionality

ajn96, 2020-08-07:
Add enable bit to make watermark interrupt behave like a "data ready" signal when the interrupt is triggered.

When the bit is set, instead of keeping watermark interrupt signal constantly high, the signal will toggle at ~10KHz. This will allow a master device (specifically the EVAL-ADIS-FX3) to trigger reads on data ready, ensuring that the buffer outputs are only read/logged when buffered data is available. When the watermark interrupt is not triggered the selected line will return to 0.

ajn96, 2020-08-07:
Done.

Closed 2020-08-07.

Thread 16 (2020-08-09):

Place interrupt vectors in core coupled memory

ajn96, 2020-08-09:
Want to modify startup code and linker script to place all ISR's in the STM32 core coupled memory. This memory has a separate bus from the regular data mem/flash, allowing for single cycle execution, with no possibility for bus contention. Per ST's application notes, this can yield up to a 30% performance improvement over executing ISR's from flash.

ajn96, 2020-08-10:
https://www.st.com/resource/en/application_note/dm00083249-use-stm32f3stm32g4-ccm-sram-with-iar-ewarm-keil-mdkarm-and-gnubased-toolchains-stmicroelectronics.pdf

ajn96, 2020-10-09:
Not doing - moving to STM32F7 for next hardware rev

Closed 2020-10-09.

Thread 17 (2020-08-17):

Add additional decoupling for the IMU

juchong, 2020-08-17:
Resetting the IMU causes VDD to fluctuate significantly. More decoupling should be added to lessen this behavior.
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

ajn96, 2020-08-24:
Added a decimation filter to the temp sensor output to make it look a little cleaner. Can still see the noise from a messy supply being multiplied into the temp measurement, but it's not as bad.
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

ajn96, 2021-04-06:
This has been incorporated into the rev C board design (100 puf caps decoupling IMU supply)

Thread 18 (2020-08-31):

Add a solder pad that disconnects the 24-pin connector VDD input from the buffer board

juchong, 2020-08-31:
This is useful to avoid back-driving 3.3V into a pre-existing system.

ajn96, 2021-04-06:
@juchong On the marked up schematic for rev C of the buffer board, you added a solder jumper for VUSB vs VDD as the input to the regulator. Did you mean to have VUSB vs VIN? Or is this issue referencing a different pad?
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

ajn96, 2021-07-22:
Adding two solder jumpers:

1. First allows selection of input to the regulator from VDD_USB or VIN
2. Second allows selection of IMU supply voltage as 3.3 or VIN

This allows a higher voltage IMU to operate from VDD_USB or VIN directly, while the STM32 operates from a 3.3V regulated supply with minimal rework required

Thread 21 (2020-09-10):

Make the SD card accessible from the outside

acloitre, 2020-09-10:
The current design prevents the installation or removal of the SD card when the IMU and its buffer board are mounted on an interfacing board. It would be easier to access the SD card if the slot was facing towards one edge of the buffer board, and the 3D-printed support could be updated for it.

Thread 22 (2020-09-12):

Add frequency selection register for "PPS" signal

ajn96, 2020-09-12:
Add a register to program the expected "PPS" frequency, in Hz. This will allow the UTC timestamp register to accurately track the wall time, even when a sync clock source not at 1Hz is used (some GPS receivers output 10Hz). The expected sync clock period for unlock detection can be scaled based on the programmed frequency.

Could also put the measured sync frequency in an output register. Not really that useful, but the value is being measured

ajn96, 2020-09-21:
May just make this a 10^n value for freq, for n = 0 - 3. Supported frequencies of 1Hz, 10Hz, 100Hz, 1000Hz

ajn96, 2020-09-22:
Done

Closed 2020-09-22.

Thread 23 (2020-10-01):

Investigate firmware compatibility with STM32F446

ajn96, 2020-10-01:
The STM32F446 is generally a much more performant processor than the F303. Twice the RAM (valuable for this firmware, with current setup is ~80% of the 64KB is in use), and more than twice the throughput (180MHz vs 72MHz). The processors are the same footprint.

Want to see how hard it would be to port firmware and hardware design to this micro, while there are relatively few boards out in the field. Don't want to potentially limit the platform down the line (could be used for algorithm development, pose calculations, etc).

ajn96, 2020-10-02:
Peripherals should be ok:
4x SPI (3 needed)
USB 2.0 controller
17 timers
16 stream DMA (3 needed)
3 ADC (1 needed). Has temp and VREFINT as well

Better RC oscillator but still probably want XTAL for more stable timestamps

ajn96, 2020-10-02:
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

ajn96, 2020-10-02:
spi2 is the same pins

ajn96, 2020-10-02:
IMU SPI CS would need to be changed. This pin operates as a PWM output (not available on this pin on F4)

ajn96, 2020-10-02:
SPI3 (SD card SPI) is good

ajn96, 2020-10-02:
DIO / ADG1611 Control: Most are good. To make firmware simpler change SW_IN3 from PC8 to PB4 and DIO1_Slave from PB4 to PC8 (single ISR handles all PPS/DR interrupts)

ajn96, 2020-10-02:
USB data lines are good. Need to check about the USB_PU connected to PB11. PB11 cannot be used as a GPIO on this processor

ajn96, 2020-10-04:
Also looking into STM32F722 - go big or go home!

ajn96, 2020-10-07:
@juchong

If we move to F722 there are more EXTI vectors available (16). Would be nice to avoid any potential ISR overlap between Data Ready and PPS.

So for example, DIOx_Slave pins could be PA8, PB8, PC8, and PC7 (interrupts 7/8 for PPS)
DIOx_Master pins could be PA9, PB9, PC9, and PA10 (interrupts 9/10 for data ready)

ajn96, 2020-10-09:
Will be moving to STM32F722

Closed 2020-10-09.

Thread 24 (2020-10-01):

Add user programmable button

ajn96, 2020-10-01:
Add button which can be reconfigured on the fly by software. A BTN_CONFIG register could be created, which maps the button press to a bit in the command register. This would allow users to start/stop SD scripts, reset DUT, flush buffer, etc while operating headless.

Ideally it would be nice for button to be rotated 90 degrees relative to the board (accessible from the side), but in plane with the micro could also work (primary use case is for headless data logging).

ajn96, 2020-10-01:
@juchong I will figure out what pin would be best for this - ideally a GPIO which doesn't share an interrupt with other parts of firmware

ajn96, 2021-04-06:
This has been incorporated into the rev C board design

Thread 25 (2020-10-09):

Add DFU command bit

ajn96, 2020-10-09:
Added bit to command register to force reboot into DFU mode to enable firmware update without external hardware

ajn96, 2020-10-09:
Started implemented. Kinda works, device fails to enumerate. Probably not cleaning something up correctly

ajn96, 2021-04-06:
This will be finalized for the rev C hardware. The STM32F722 has somewhat different DFU behavior vs the STM32F303

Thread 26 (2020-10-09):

Change processor from STM32F303 to STM32F722

ajn96, 2020-10-09:
Moving to STM32F722 will provide more resources (256KB RAM, 180MHz core clock) and capability for future algorithm development.

There are more EXTI vectors available (16). Would be nice to avoid any potential ISR overlap between Data Ready and PPS.

So for example, DIOx_Slave pins could be PA8, PB8, PC8, and PC7 (interrupts 7/8 for PPS)
DIOx_Master pins could be PA9, PB9, PC9, and PA10 (interrupts 9/10 for data ready)

SPI pins should be good to keep the same, with the exception of IMU CS, which needs to be on a timer output channel pin

ajn96, 2020-10-09:
Will leave current firmware for F3 on branch when this change is made. Not planning on adding new features to F3 version afterwards

ajn96, 2020-11-09:
@juchong Before we pull the trigger on this change we should probably have a deeper discussion (and maybe pull in other team members?) about the future of this platform. Current processor is fine for the "comms" operations the board performs currently (SPI, USB, or SD logging). Main advantage of going to different board would be potential for adding Kalmann filtering, pose estimates, or other IMU aware DSP. Need to figure out if that is something we want to do, and if it is worth the extra development effort to port design, and BoM cost / power consumption.

juchong, 2020-11-09:
From my discussions with other internal teams, I've been told that the increased ”horsepower” will be greatly valued and will help merge several, independent efforts to create a reasonable sensor fusion platform. Some of the feature requests listed in the repository are a product of those discussions.

ajn96, 2020-11-09:
Ok. Just wanted to make sure we had thought through everything. From my initial review, I think porting the firmware should be fairly straight forward, as long as there aren't any big whoopsies porting the hardware design over that require fixes in software. Most of the functionality offered by the F7 is a superset of the functionality offered F3. New processor should allow up to 1 second of buffered data capture from the high performance IMU's as well, which is a metric I know some folks were looking for.

ajn96, 2021-02-06:
@juchong STM32F722 processor pin map for buffer board hardware rev C

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

ajn96, 2021-02-08:
@juchong
https://www.analog.com/en/products/amplifiers/specialty-amplifiers/current-sense-amplifiers.html
Just saying. We're going to have the A/D running anyways

juchong, 2021-02-08:
@ajn96 I don't think we picked a GPIO for triggering an IMU Reset (IMU_RST_OUT). We picked PA3 to act as IMU_RST_IN

ajn96, 2021-02-08:
> @ajn96 I don't think we picked a GPIO for triggering an IMU Reset (IMU_RST_OUT). We picked PA3 to act as IMU_RST_IN

I was intended PA_03 to drive the IMU reset line. What would the IMU reset input do? I think the host reset line should connect directly to the STM32 hardware reset input

juchong, 2021-02-08:
Agreed. I forgot what the intended behavior was supposed to be

juchong, 2021-02-08:
Here's the proposed schematic @ajn96
[BufferBoardRedesign-02082021 - Feb 8 2021 - 12-50 PM.pdf](https://github.com/ajn96/iSensor-SPI-Buffer/files/5945712/BufferBoardRedesign-02082021.-.Feb.8.2021.-.12-50.PM.pdf)

juchong, 2021-03-10:
Updated schematic with slightly different (but more convenient) part numbers:
[iSensor-SPI-Buffer-RevC - Feb 24 2021 - 11-22 AM.pdf](https://github.com/ajn96/iSensor-SPI-Buffer/files/6118604/iSensor-SPI-Buffer-RevC.-.Feb.24.2021.-.11-22.AM.pdf)

ajn96, 2021-04-06:
Updated the pin map diagram with final net names:
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

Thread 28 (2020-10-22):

Use the unallocated pin on the USBC connector as a PPS input pin

juchong, 2020-10-22:

ajn96, 2020-10-23:
@juchong good idea! We should be able to use on of the dedicated USB alternate function pins. I'll need to take a look at what pin would be good on the micro. In general before you start the layout on the Rev C we should probably do a full schematic review

juchong, 2020-11-09:
An additional adapter/injection board will need to be developed to take advantage of this feature.

ajn96, 2021-04-06:
This has been incorporated into the rev C board design. The USB alternate function line goes into a mux, which can be configured by software to connect the line to any of the IMU DIO lines.

ajn96, 2021-11-03:
Plan is to add a "SB_MUX" bitfield to CLI_CONFIG to support this mux functionality

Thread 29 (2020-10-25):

Issue with timestamp over USB CLI stream

ajn96, 2020-10-25:
There appears to be an issue where buffer values can be received improperly over the USB CLI. This happens very periodically (every 60ms at 1KHz sample freq), and does not appear to depend on the data ready freq.

165613195
165614195
165613015
Invalid timestamp freq -847.457627118644
165614015
165615015
165616015
165617015

165677017
165678017
165676837
Invalid timestamp freq -847.457627118644
165677837
165678837
165679837

This issue does not appear to happen when buffered data is retrieved via the SPI port (plot below shows sample timestamp deltas)
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

ajn96, 2020-10-25:
Appears to just be an issue with the timestamp? The IMU data count associated with each sample increments as expected, even when the timestamp "jumps"

419
420
421
Invalid delta!
422
423
424

ajn96, 2020-10-25:
Doesnt happen for low data rates (400Hz). My guess is this is an issue with the ping-pong used for USB transmit

ajn96, 2020-10-25:
Data is coming out of the FIFO in firmware in the correct order. Added test code to the firmware which never tripped

		/* Check timestamp */
		counter++;
		timestamp = ReadReg(BUF_BASE_ADDR + 4) | (ReadReg(BUF_BASE_ADDR + 6) << 16);
		if(timestamp < lastTime)
			g_regs[USER_SCR_0_REG] = counter;
		lastTime = timestamp;
		g_regs[USER_SCR_0_REG + 1] = timestamp;

So issue has to be on USB transmit layer

ajn96, 2020-11-09:
Fixed. Was issue with the python library

Closed 2020-11-09.

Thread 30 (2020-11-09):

"Halted" USB port during steam causes watchdog reset

ajn96, 2020-11-09:
Currently, readbuf handler will keep trying to transmit data until it is successful. This can cause the firmware to undergo a watchdog reset if the USB host device stops requesting stream data (if you are debugging in the Python runtime for instance).

Fix will probably be to make the readbuf handler exit if a transmit timeout occurs. Ideally, it should check that the USB is not busy prior to dequeue, to prevent data from being dequeued and then not transmitted. This has to be balanced with the potential stream throughput implications.

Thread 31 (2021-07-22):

Add support for automotive SPI protocol

ajn96, 2021-07-22:
The current buffer board firmware supports only the standard ADIS IMU SPI protocol. It would be useful to add "invisible" support for the automotive SPI protocol (see ADXC1500) w/ CRC (see ADXC1500). This will require a few tweaks:

1. Add code for generating SPI words based on the requested read/write, rather than simply passing transactions
2. Add logic for supporting writes. The automotive SPI protocol uses read16/write16, rather than the read16/write8 protocol used by the IMU product line. This can be worked around by adding logic to the IMU write reg routine which waits for two consecutive 8-bit writes to be requested, then performs a single 16-bit write.

Plan: Add two bits to IMU_SPI_CONFIG: AUTO_SPI and AUTO_SPI_WRITE16 to support this functionality

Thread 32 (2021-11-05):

Convert SD card driver from SPI to SDMMC

ajn96, 2021-11-05:
Current FW uses SPI to communicate with SD card. To improve throughput, revC uses SDMMC. Will need to swap the driver used by FATFS.

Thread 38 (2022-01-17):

Ambiguous License

xjzi, 2022-01-17:
The repository is under the MIT license, but many files have headers saying the following:

>  Copyright (c) Analog Devices Inc, 2020
>  All Rights Reserved.

This loosely means that no one can use this file without your permission. What is the intentional license for your code?
Please clarify in the file headers if it is under the MIT license.

ajn96, 2022-01-17:
Hello,
Thanks for bringing up this issue. The intent is for the entire project to be MIT licensed - I will update the source file headers to reflect this.

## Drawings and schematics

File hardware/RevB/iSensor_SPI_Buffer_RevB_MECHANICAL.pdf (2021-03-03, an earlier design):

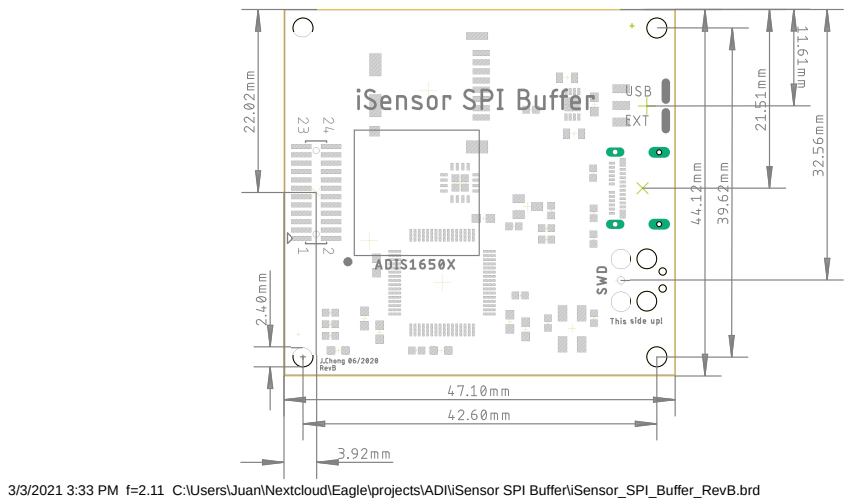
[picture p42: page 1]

3/3/2021 3:33 PM f=2.11 C:\Users\Juan\Nextcloud\Eagle\projects\ADI\iSensor SPI Buffer\iSensor_SPI_Buffer_RevB.brd

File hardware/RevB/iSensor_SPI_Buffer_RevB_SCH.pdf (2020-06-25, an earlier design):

A

A

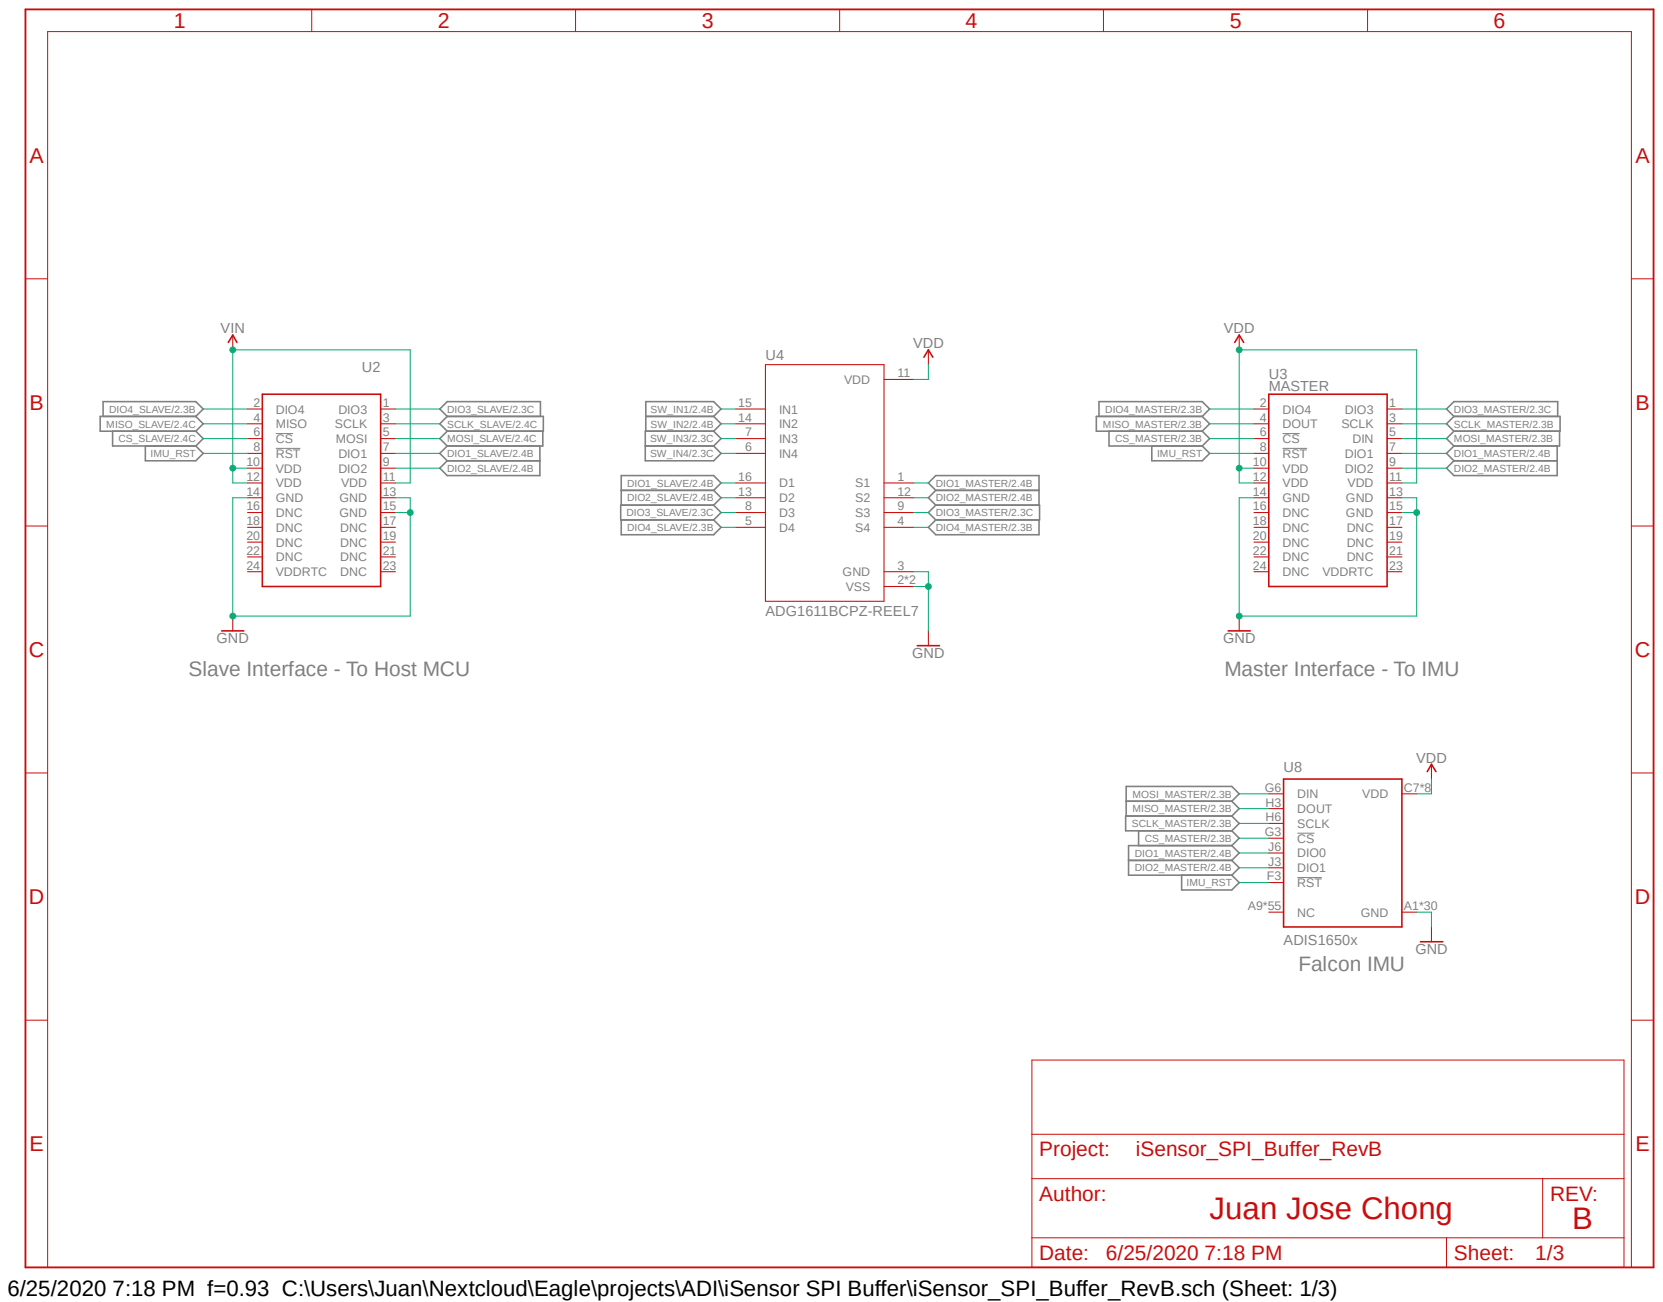
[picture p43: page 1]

Author: Juan Jose Chong | REV: B

Date: 6/25/2020 7:18 PM | Sheet: 1/3

6/25/2020 7:18 PM f=0.93 C:\Users\Juan\Nextcloud\Eagle\projects\ADI\iSensor SPI Buffer\iSensor_SPI_Buffer_RevB.sch (Sheet: 1/3)

A

A

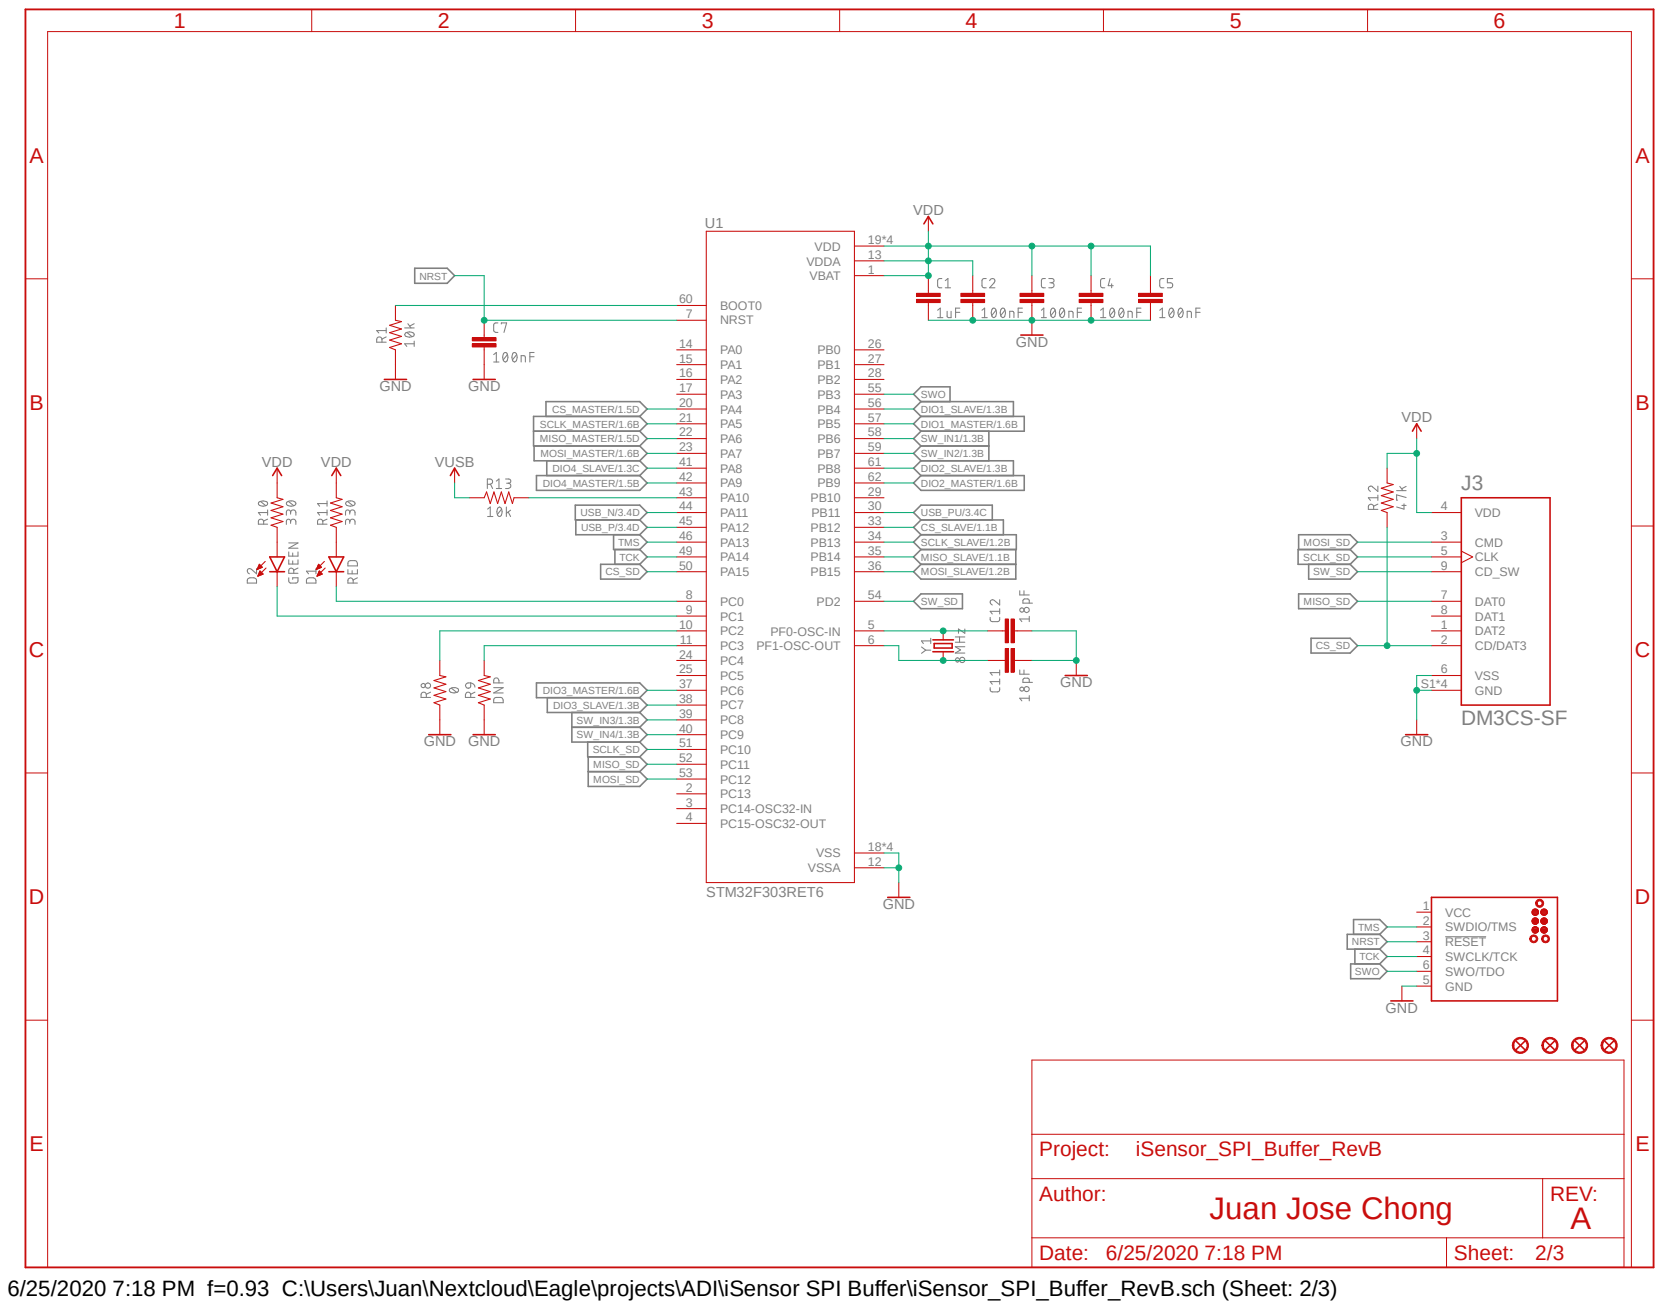
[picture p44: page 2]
STM32F303RET6; GND; VDD; GND GND; VUSB; VBAT; PC14-OSC32-IN 3; PC15-OSC32-OUT 4; PF0-OSC-IN; 5 PF1-OSC-OUT; NRST 7; VSSA; VDDA; VSS; BOOT0 60; VCC 1; SWDIO/TMS 2; RESET 3; SWCLK/TCK 4; SWO/TDO 6; GND 5; DAT0 7; DAT1 8; DAT2 1; CD/DAT3 2; CMD 3; CLK 5; VDD 4; VSS 6; GND S1*4; J3 TMS; TMS; NRST; TCK; SWO; CS_MASTER/1.5D; SCLK_MASTER/1.6B MISO_MASTER/1.5D MOSI_MASTER/1.6B DIO3_SLAVE/1.3B; DIO2_SLAVE/1.3B; SW_IN2/1.3B CS_SLAVE/1.1B; SCLK_SLAVE/1.2B MISO_SLAVE/1.1B MOSI_SLAVE/1.2B; DIO4_SLAVE/1.3C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

6/25/2020 7:18 PM f=0.93 C:\Users\Juan\Nextcloud\Eagle\projects\ADI\iSensor SPI Buffer\iSensor_SPI_Buffer_RevB.sch (Sheet: 2/3)

A

A

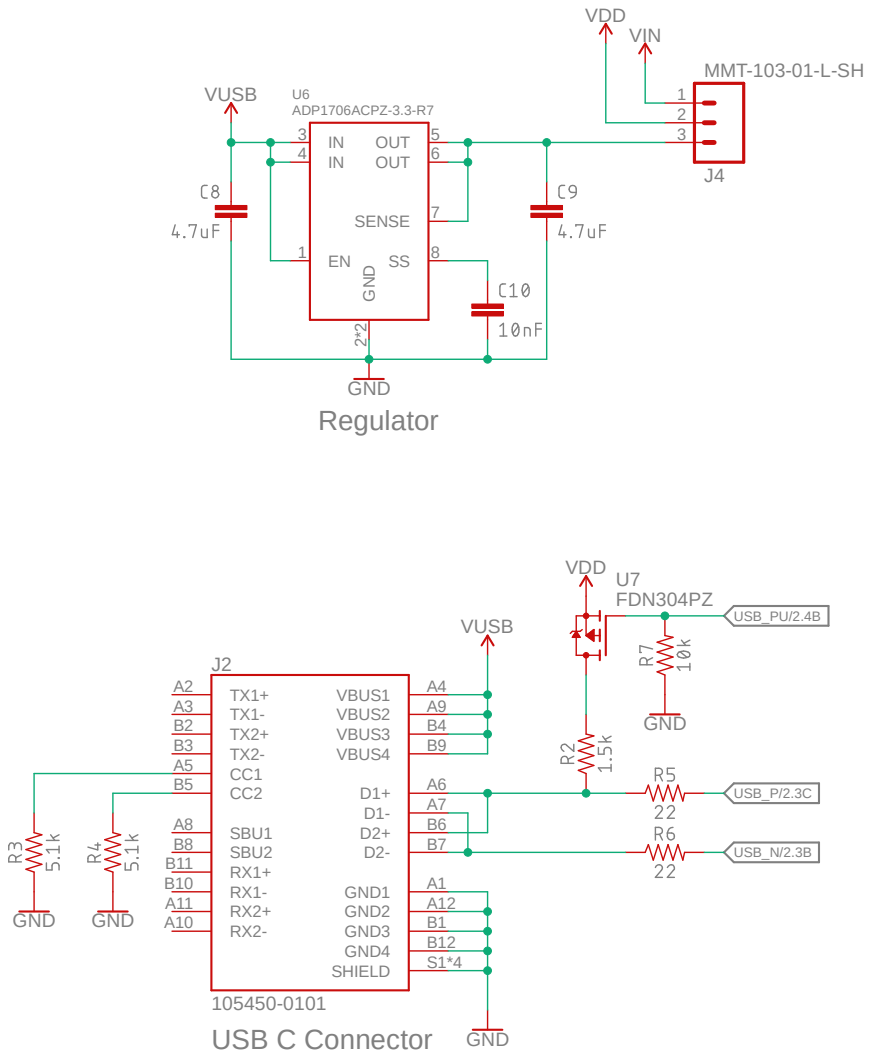
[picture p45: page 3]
USB C Connector; Regulator ADP1706ACPZ-3.3-R7; MMT-103-01-L-SH; VDD; VIN; VUSB; GND; FDN304PZ; GND 2*2; OUT; 5 OUT; 6 SENSE; GND1; VBUS1; A7 SBU1 A8; GND2; A12 VBUS2; A9 GND3; B1 GND4; B12 VBUS3; B4 VBUS4; B9 SBU2 B8; B7 SHIELD; USB_P/2.3C; USB_N/2.3B USB_PU/2.4B; Project:; iSensor_SPI_Buffer_RevB

6/25/2020 7:18 PM f=0.93 C:\Users\Juan\Nextcloud\Eagle\projects\ADI\iSensor SPI Buffer\iSensor_SPI_Buffer_RevB.sch (Sheet: 3/3)

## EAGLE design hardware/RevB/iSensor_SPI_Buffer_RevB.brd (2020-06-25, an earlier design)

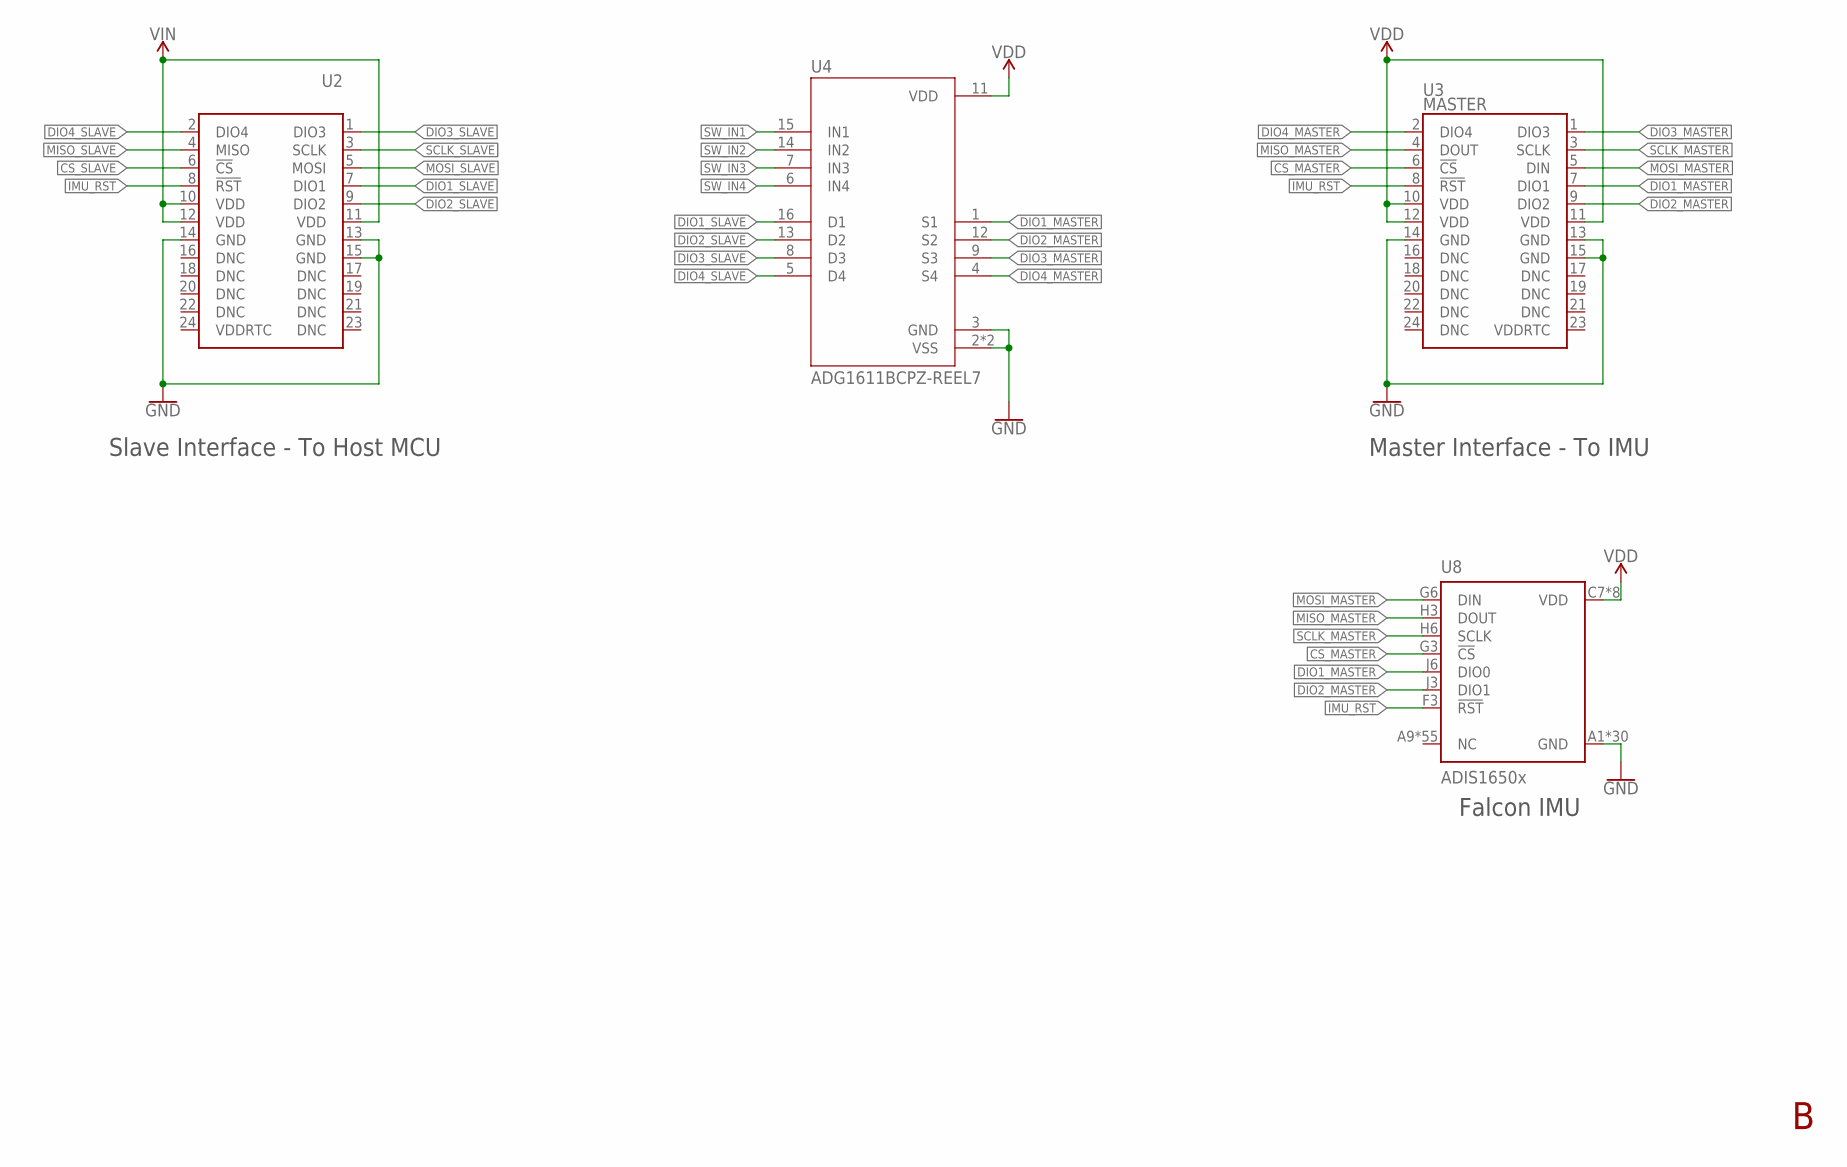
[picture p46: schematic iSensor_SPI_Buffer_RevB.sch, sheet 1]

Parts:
U2: MW-12-03-H-D-130-112
U3: MASTER; ADIS1648X
U4: ADG1611BCPZ-REEL7; QFN65P400X400X80-17N
U8: ADIS1650x; ADIS1650X

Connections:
CS_MASTER: U3.6 (!CS), U8.G3 (!CS); also elsewhere on the board
CS_SLAVE: U2.6 (!CS); also elsewhere on the board
DIO1_MASTER: U3.7 (DIO1), U4.1 (S1), U8.J6 (DIO0); also elsewhere on the board
DIO1_SLAVE: U2.7 (DIO1), U4.16 (D1); also elsewhere on the board
DIO2_MASTER: U3.9 (DIO2), U4.12 (S2), U8.J3 (DIO1); also elsewhere on the board
DIO2_SLAVE: U2.9 (DIO2), U4.13 (D2); also elsewhere on the board
DIO3_MASTER: U3.1 (DIO3), U4.9 (S3); also elsewhere on the board
DIO3_SLAVE: U2.1 (DIO3), U4.8 (D3); also elsewhere on the board
DIO4_MASTER: U3.2 (DIO4), U4.4 (S4); also elsewhere on the board
DIO4_SLAVE: U2.2 (DIO4), U4.5 (D4); also elsewhere on the board
GND: U2.13 (GND), U2.14 (GND), U2.15 (GND), U3.13 (GND), U3.14 (GND), U3.15 (GND), U4.2 (VSS), U4.3 (GND), U4.17 (VSS), U8.A1 (GND), U8.A2 (GND), U8.A3 (GND), U8.A4 (GND), U8.A5 (GND), U8.A6 (GND), U8.A7 (GND), U8.A8 (GND), U8.B3 (GND), U8.B4 (GND), U8.B5 (GND), U8.B6 (GND), U8.C2 (GND), U8.C6 (GND), U8.D3 (GND), U8.E2 (GND), U8.E6 (GND), U8.E7 (GND), U8.F1 (GND), U8.F5 (GND), U8.F6 (GND), U8.F8 (GND), U8.G2 (GND), U8.G7 (GND), U8.H8 (GND), U8.J2 (GND), U8.J7 (GND), U8.K1 (GND), U8.K3 (GND), U8.K8 (GND); also elsewhere on the board
IMU_RST: U2.8 (!RST), U3.8 (!RST), U8.F3 (!RST)
MISO_MASTER: U3.4 (DOUT), U8.H3 (DOUT); also elsewhere on the board
MISO_SLAVE: U2.4 (MISO); also elsewhere on the board
MOSI_MASTER: U3.5 (DIN), U8.G6 (DIN); also elsewhere on the board
MOSI_SLAVE: U2.5 (MOSI); also elsewhere on the board
SCLK_MASTER: U3.3 (SCLK), U8.H6 (SCLK); also elsewhere on the board
SCLK_SLAVE: U2.3 (SCLK); also elsewhere on the board
SW_IN1: U4.15 (IN1); also elsewhere on the board
SW_IN2: U4.14 (IN2); also elsewhere on the board
SW_IN3: U4.7 (IN3); also elsewhere on the board
SW_IN4: U4.6 (IN4); also elsewhere on the board
VDD: U3.10 (VDD), U3.11 (VDD), U3.12 (VDD), U4.11 (VDD), U8.C7 (VDD), U8.D6 (VDD), U8.E3 (VDD), U8.G1 (VDD), U8.H1 (VDD), U8.J4 (VDD), U8.J5 (VDD), U8.K6 (VDD); also elsewhere on the board
VIN: U2.10 (VDD), U2.11 (VDD), U2.12 (VDD); also elsewhere on the board

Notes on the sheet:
Slave Interface - To Host MCU
Master Interface - To IMU
Falcon IMU

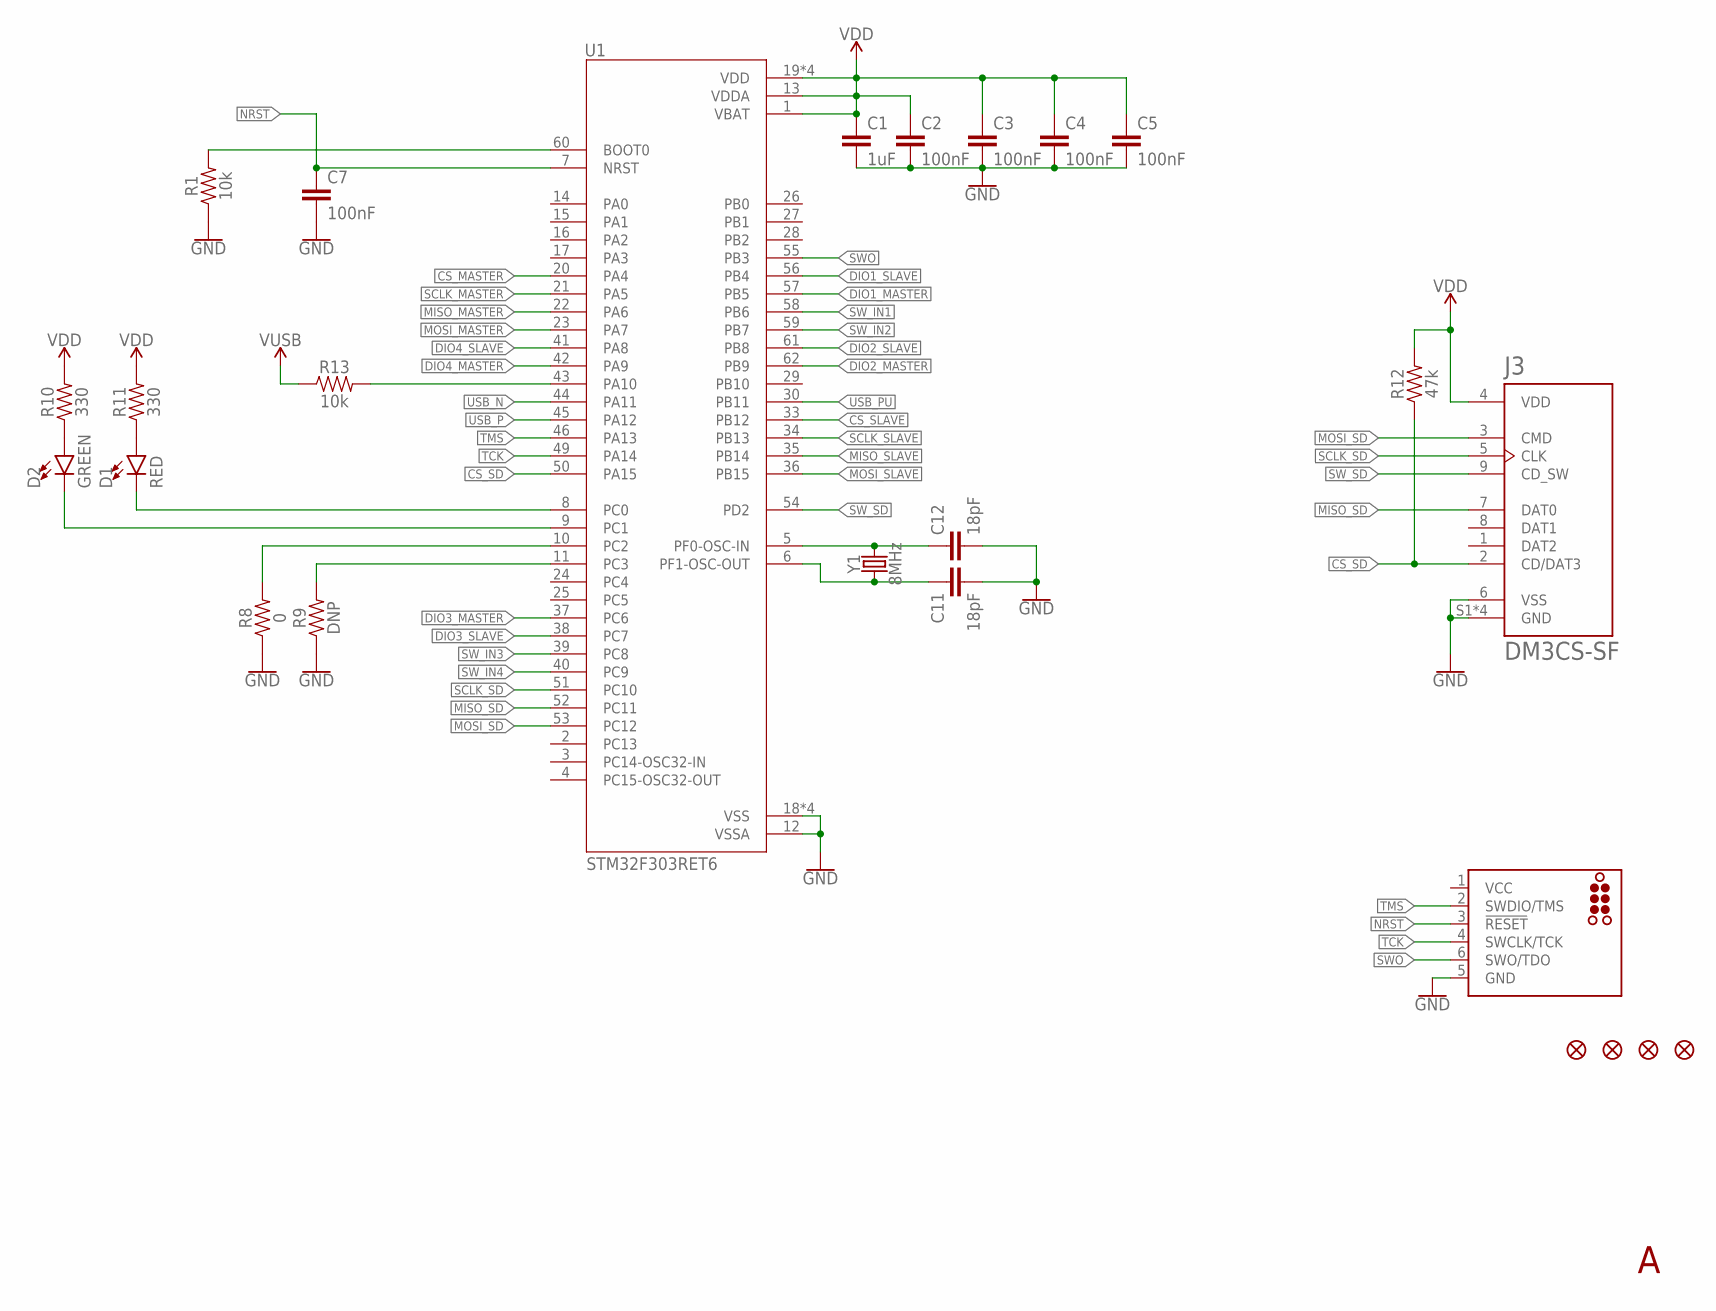
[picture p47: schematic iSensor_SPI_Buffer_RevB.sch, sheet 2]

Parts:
C1: 1uF; 0603
C2, C3, C4, C5, C7: 100nF; 0603
C11, C12: 18pF; 0402
D1: RED; LED-0603
D2: GREEN; LED-0603
FD1, FD2, FD3, FD4: FIDUCIAL1X2; FIDUCIAL-1X2
J1: TC2030_SWD-MCP; TC2030-MCP
J3: DM3CS-SF; HRS_DM3CS-SF
R1, R13: 10k; 0402
R8: 0; 0402
R9: DNP; 0402
R10, R11: 330; 0402
R12: 47k; 0402
U1: STM32F303RET6; QFP50P1200X1200X160-64N
Y1: 8MHz; CRYSTAL-SMD-5X3.2-4PAD

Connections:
CS_MASTER: U1.20 (PA4); also elsewhere on the board
CS_SD: J3.2 (CD/DAT3), R12.1, U1.50 (PA15)
CS_SLAVE: U1.33 (PB12); also elsewhere on the board
DIO1_MASTER: U1.57 (PB5); also elsewhere on the board
DIO1_SLAVE: U1.56 (PB4); also elsewhere on the board
DIO2_MASTER: U1.62 (PB9); also elsewhere on the board
DIO2_SLAVE: U1.61 (PB8); also elsewhere on the board
DIO3_MASTER: U1.37 (PC6); also elsewhere on the board
DIO3_SLAVE: U1.38 (PC7); also elsewhere on the board
DIO4_MASTER: U1.42 (PA9); also elsewhere on the board
DIO4_SLAVE: U1.41 (PA8); also elsewhere on the board
GND: C1.2, C2.2, C3.2, C4.2, C5.2, C7.2, C11.2, C12.2, J1.5 (GND), J3.6 (VSS), J3.S1 (GND), J3.S2 (GND), J3.S3 (GND), J3.S5 (GND), R1.1, R8.1, R9.1, U1.12 (VSSA), U1.18 (VSS), U1.31 (VSS), U1.47 (VSS), U1.63 (VSS); also elsewhere on the board
MISO_MASTER: U1.22 (PA6); also elsewhere on the board
MISO_SD: J3.7 (DAT0), U1.52 (PC11)
MISO_SLAVE: U1.35 (PB14); also elsewhere on the board
MOSI_MASTER: U1.23 (PA7); also elsewhere on the board
MOSI_SD: J3.3 (CMD), U1.53 (PC12)
MOSI_SLAVE: U1.36 (PB15); also elsewhere on the board
unnamed: R1.2, U1.60 (BOOT0)
unnamed: D1.C, U1.8 (PC0)
unnamed: D2.C, U1.9 (PC1)
unnamed: R8.2, U1.10 (PC2)
unnamed: R9.2, U1.11 (PC3)
unnamed: D2.A, R10.1
unnamed: D1.A, R11.1
unnamed: R13.2, U1.43 (PA10)
unnamed: C11.1, U1.6 (PF1-OSC-OUT), Y1.1
unnamed: C12.1, U1.5 (PF0-OSC-IN), Y1.3 (2)
NRST: C7.1, J1.3 (!RESET), U1.7 (NRST)
SCLK_MASTER: U1.21 (PA5); also elsewhere on the board
SCLK_SD: J3.5 (CLK), U1.51 (PC10)
SCLK_SLAVE: U1.34 (PB13); also elsewhere on the board
SWO: J1.6 (SWO/TDO), U1.55 (PB3)
SW_IN1: U1.58 (PB6); also elsewhere on the board
SW_IN2: U1.59 (PB7); also elsewhere on the board
SW_IN3: U1.39 (PC8); also elsewhere on the board
SW_IN4: U1.40 (PC9); also elsewhere on the board
SW_SD: J3.9 (CD_SW), U1.54 (PD2)
TCK: J1.4 (SWCLK/TCK), U1.49 (PA14)
TMS: J1.2 (SWDIO/TMS), U1.46 (PA13)
USB_N: U1.44 (PA11); also elsewhere on the board
USB_P: U1.45 (PA12); also elsewhere on the board
USB_PU: U1.30 (PB11); also elsewhere on the board
VDD: C1.1, C2.1, C3.1, C4.1, C5.1, J3.4 (VDD), R10.2, R11.2, R12.2, U1.1 (VBAT), U1.13 (VDDA), U1.19 (VDD), U1.32 (VDD), U1.48 (VDD), U1.64 (VDD); also elsewhere on the board
V_USB: R13.1; also elsewhere on the board

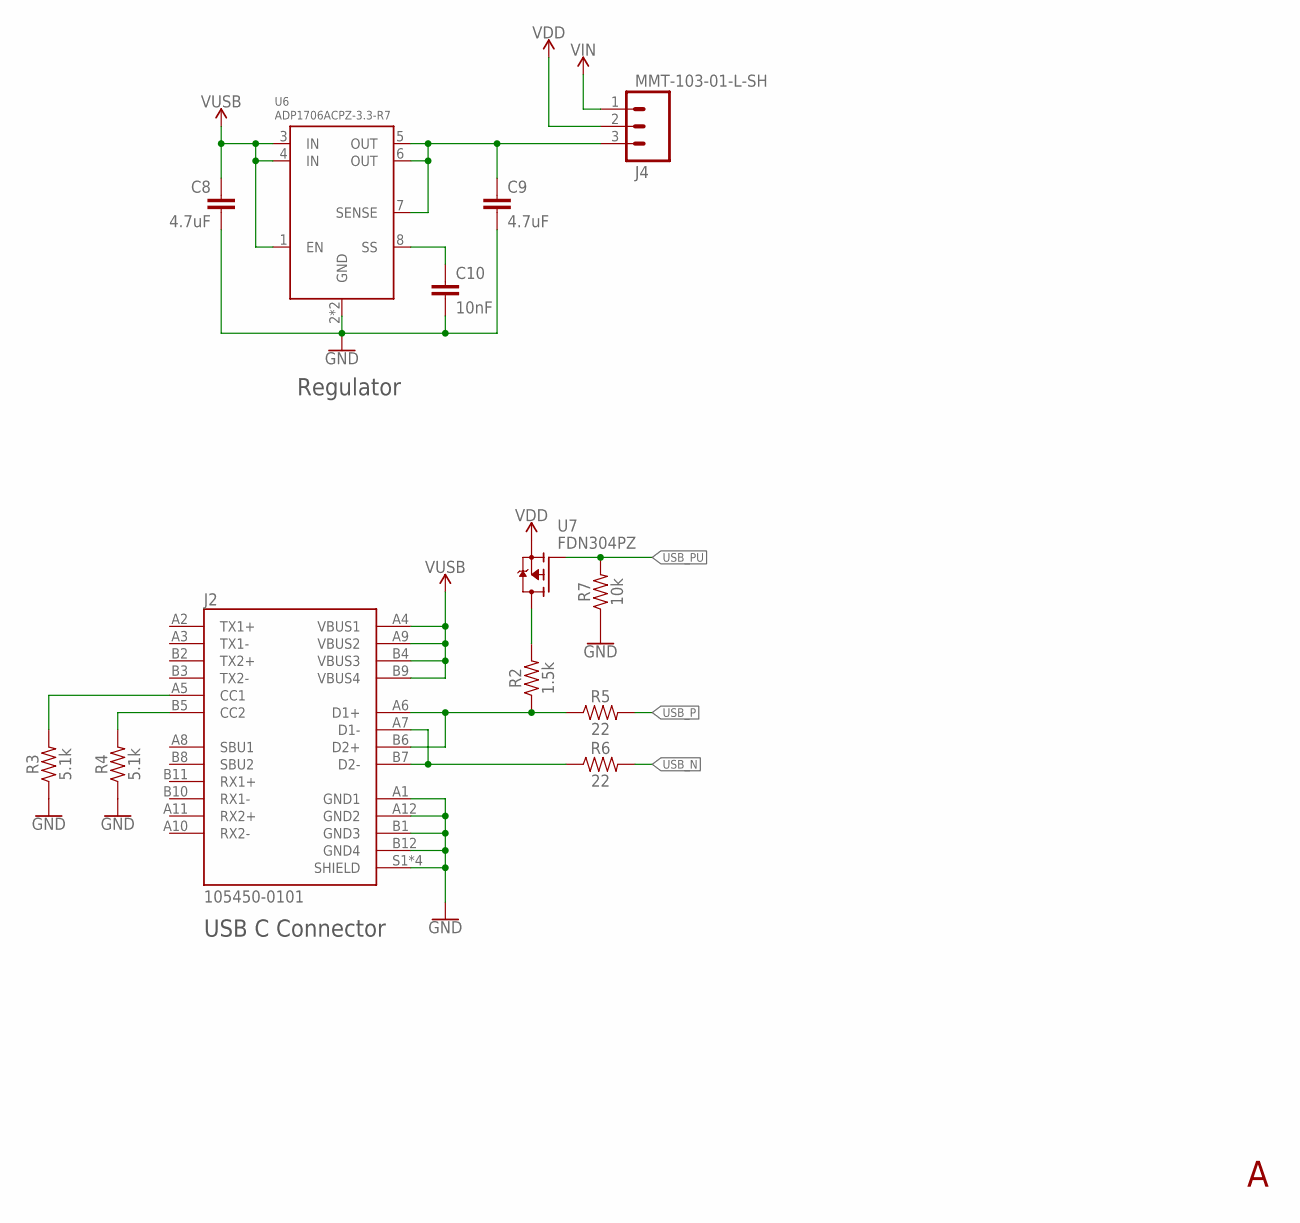
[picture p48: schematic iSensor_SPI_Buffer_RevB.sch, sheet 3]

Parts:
C8, C9: 4.7uF; 0805
C10: 10nF; 0603
J2: 105450-0101; MOLEX_105450-0101
J4: MMT-103-01-L-SH; SAMTEC-MMT-103-01-X-SH
R2: 1.5k; 0402
R3, R4: 5.1k; 0402
R5, R6: 22; 0402
R7: 10k; 0402
U6: ADP1706ACPZ-3.3-R7; DFN300X300X90-9N
U7: FDN304PZ; SOT23

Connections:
GND: C8.2, C9.2, C10.2, J2.A1 (GND1), J2.A12 (GND2), J2.B1 (GND3), J2.B12 (GND4), J2.S1 (SHIELD), J2.S2 (SHIELD), J2.S3 (SHIELD), J2.S4 (SHIELD), R3.1, R4.1, R7.1, U6.2 (GND), U6.9 (GND); also elsewhere on the board
unnamed: J2.A5 (CC1), R3.2
unnamed: J2.B5 (CC2), R4.2
unnamed: C9.1, J4.3, U6.5 (OUT), U6.6 (OUT), U6.7 (SENSE)
unnamed: R2.2, U7.3 (D)
unnamed: C10.1, U6.8 (SS)
USB+_N: J2.A7 (D1-), J2.B7 (D2-), R6.1
USB+_P: J2.A6 (D1+), J2.B6 (D2+), R2.1, R5.1
USB_N: R6.2; also elsewhere on the board
USB_P: R5.2; also elsewhere on the board
USB_PU: R7.2, U7.1 (G); also elsewhere on the board
VDD: J4.2, U7.2 (S); also elsewhere on the board
VIN: J4.1; also elsewhere on the board
V_USB: C8.1, J2.A4 (VBUS1), J2.A9 (VBUS2), J2.B4 (VBUS3), J2.B9 (VBUS4), U6.1 (EN), U6.3 (IN), U6.4 (IN); also elsewhere on the board

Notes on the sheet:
USB C Connector
Regulator

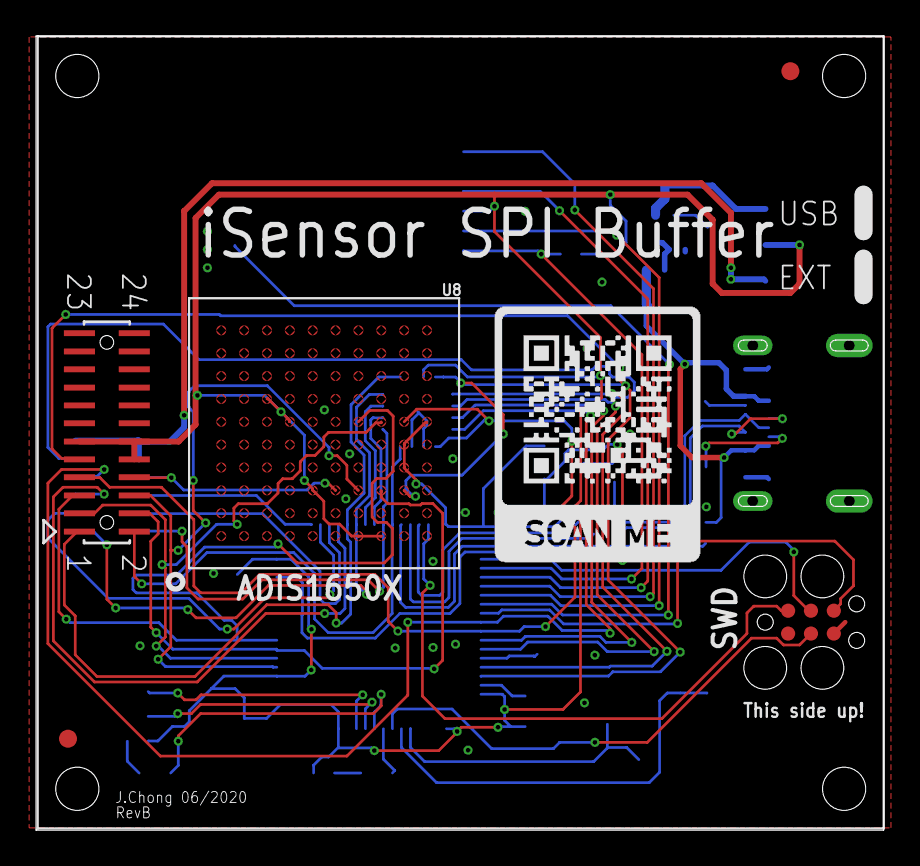
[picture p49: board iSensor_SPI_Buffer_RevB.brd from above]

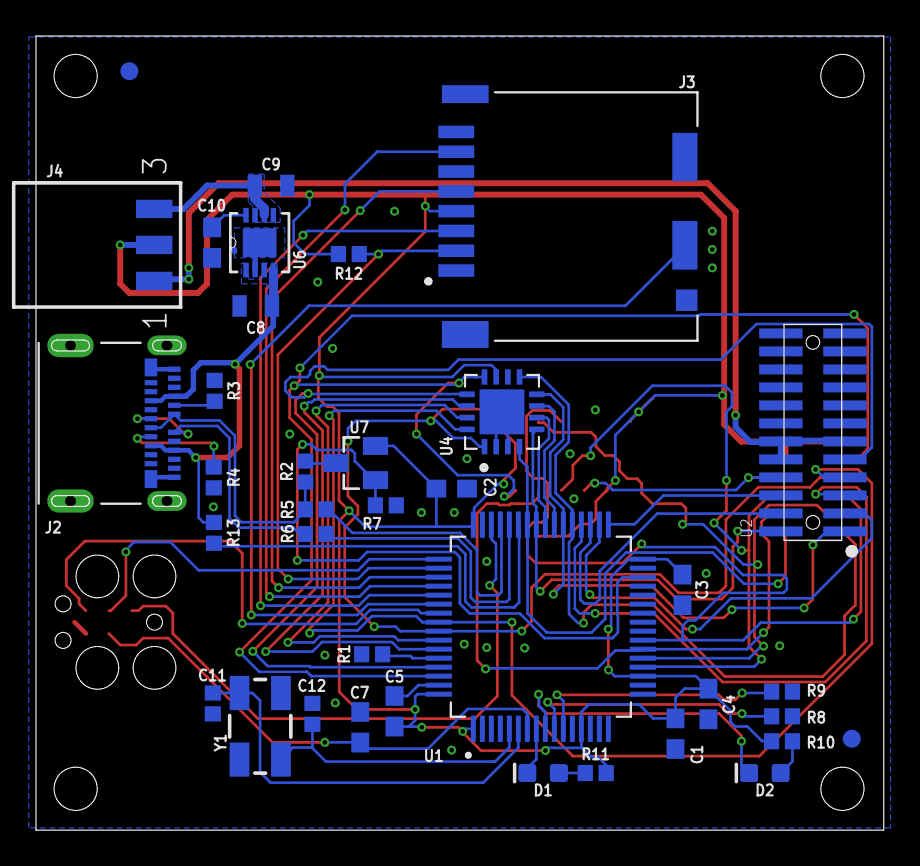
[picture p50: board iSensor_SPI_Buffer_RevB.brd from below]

Board: 2 copper layers, 47.1 x 44.1 mm, 42 parts (37 on the bottom side), 54 nets.

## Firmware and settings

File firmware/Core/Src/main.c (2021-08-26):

/**
  * Copyright (c) Analog Devices Inc, 2020
  * All Rights Reserved.
  *
  * @file		main.c
  * @date		3/14/2020
  * @author		A. Nolan (alex.nolan@analog.com)
  * @brief		iSensor-SPI-Buffer main. Contains STM init functions and application cyclic executive.
 **/

#include "usb.h"
#include "main.h"
#include "reg.h"
#include "imu.h"
#include "usbd_cdc_if.h"
#include "usb_device.h"
#include "sd_card.h"
#include "buffer.h"
#include "user_interrupt.h"
#include "flash.h"
#include "led.h"
#include "watchdog.h"
#include "timer.h"
#include "dio.h"
#include "adc.h"
#include "dfu.h"
#include "user_spi.h"
#include "data_capture.h"
#include "script.h"

/* Private function prototypes */
static void SystemClock_Config();
static void MX_GPIO_Init();
static void DMA_Init();

/** IMU SPI Rx DMA handle. Global scope */
DMA_HandleTypeDef g_dma_spi1_rx;

/** IMU SPI Tx DMA handle. Global scope */
DMA_HandleTypeDef g_dma_spi1_tx;

/** User SPI Tx DMA handle. Global scope */
DMA_HandleTypeDef g_dma_spi2_tx;

/** SPI handle for IMU master port. Global scope */
SPI_HandleTypeDef g_spi1;

/** SPI handle for slave port (from master controller). Global scope */
SPI_HandleTypeDef g_spi2;

/** Track the cyclic executive state */
static uint32_t state;

/**
  * @brief The application entry point.
  *
  * @return main status code. Should not return.
  */
int main()
{
  /* Check if application needs to reboot into DFU mode prior to any config */
  DFU_Check_Flags();
  /* Reset of all peripherals, Initializes the Flash interface and the Systick. */
  HAL_Init();
  /* Configure the system clock */
  SystemClock_Config();
  /* Enable watch dog timer (2 seconds period) */
  Watchdog_Enable(2000);
  /* Check if system had previously encountered an unexpected fault */
  Flash_Fault_Log_Init();
  /* Initialize GPIO */
  MX_GPIO_Init();
  /* Init misc timers  */
  Timer_Init();
  /* Initialize IMU SPI port */
  IMU_SPI_Init();
  /* Initialize SD card interface */
  SD_Card_Init();
  /* Initialize USB hardware */
  MX_USB_DEVICE_Init();
  /* Load register values */
  Reg_Init();
  /* Check for logged error codes and update FAULT_CODE */
  Flash_Check_Logged_Fault();
  /* Check if system previously reset due to watch dog */
  Watchdog_Check_Status();
  /* Init buffer */
  Buffer_Reset();
  /* Config IMU SPI settings */
  IMU_Update_SPI_Config();
  /* Init DIO outputs */
  DIO_Update_Output_Config();
  /* Init DIO inputs (data ready and PPS) */
  DIO_Update_Input_Config();
  /* Disable data capture initially */
  Data_Capture_Disable();
  /* Set DR int priority (lower than user SPI - no preemption) */
  HAL_NVIC_SetPriority(EXTI9_5_IRQn, 1, 0);
  /* Init ADC for housekeeping */
  ADC_Init();
  /* Configure and enable user SPI port (based on loaded register values) */
  User_SPI_Update_Config(false);
  /* Trigger a USB re-enum on host */
  USB_Reset();
  /* Init and Enable DMA channels */
  DMA_Init();
  /* Check for script auto-run set immediately before entering cyclic executive */
  SD_Card_Script_Autorun();

  /* Set state to 0 */
  state = 0;
  /* Clear all update flags before entering loop (shouldn't be set anyways, but it doesn't hurt) */
  g_update_flags = 0;

  /* Infinite cyclic executive loop */
  while(1)
  {
	  /* Process buf dequeue every loop iteration (high priority) */
	  if(g_update_flags & DEQUEUE_BUF_FLAG)
	  {
		  /* Only proceed once burst start flag is cleared */
		  if(g_user_burst_start == 0u)
		  {
			  g_update_flags &= ~DEQUEUE_BUF_FLAG;
			  Reg_Buf_Dequeue_To_Outputs();
		  }
	  }

	  /* Check user interrupt generation status */
	  User_Interrupt_Update();

	  /* Feed watch dog timer */
	  Watchdog_Feed();

	  /* State machine for non-timing critical processing tasks */
	  switch(state)
	  {
	  case STATE_CHECK_FLAGS:
		  /* Handle capture disable */
		  if(g_update_flags & DISABLE_CAPTURE_FLAG)
		  {
			  g_update_flags &= ~DISABLE_CAPTURE_FLAG;
			  /* Make sure both can't be set */
			  g_update_flags &= ~(ENABLE_CAPTURE_FLAG);
			  Data_Capture_Disable();
		  }
		  /* Handle change to DIO input config (validate only, no enable) */
		  else if(g_update_flags & DIO_INPUT_CONFIG_FLAG)
		  {
			  g_update_flags &= ~DIO_INPUT_CONFIG_FLAG;
			  DIO_Validate_Input_Config();
		  }
		  /* Handle capture enable */
		  else if(g_update_flags & ENABLE_CAPTURE_FLAG)
		  {
			  g_update_flags &= ~ENABLE_CAPTURE_FLAG;
			  Data_Capture_Enable();
		  }
		  /* Handle user commands */
		  else if(g_update_flags & USER_COMMAND_FLAG)
		  {
			  g_update_flags &= ~USER_COMMAND_FLAG;
			  Reg_Process_Command();
		  }
		  /* Handle capture DIO output config change */
		  else if(g_update_flags & DIO_OUTPUT_CONFIG_FLAG)
		  {
			  g_update_flags &= ~DIO_OUTPUT_CONFIG_FLAG;
			  DIO_Update_Output_Config();
		  }
		  /* Handle change to IMU SPI config */
		  else if(g_update_flags & IMU_SPI_CONFIG_FLAG)
		  {
			  g_update_flags &= ~IMU_SPI_CONFIG_FLAG;
			  IMU_Update_SPI_Config();
		  }
		  /* Handle change to user SPI config */
		  else if(g_update_flags & USER_SPI_CONFIG_FLAG)
		  {
			  g_update_flags &= ~USER_SPI_CONFIG_FLAG;
			  User_SPI_Update_Config(true);
		  }
		  /* Advance to next state */
		  state = STATE_CHECK_PPS;
		  break;
	  case STATE_CHECK_PPS:
		  /* Check that PPS isn't unlocked */
		  Timer_Check_PPS_Unlock();
		  /* Advance to next state */
		  state = STATE_READ_ADC;
		  break;
	  case STATE_READ_ADC:
		  /* Update ADC state machine */
		  ADC_Update();
		  /* Advance to next state */
		  state = STATE_CHECK_USB;
		  break;
	  case STATE_CHECK_USB:
		  /* Handle any USB command line Rx activity */
		  USB_Rx_Handler();
		  /* Advance to next state */
		  state = STATE_CHECK_STREAM;
		  break;
	  case STATE_CHECK_STREAM:
		  /* Check stream status for CLI */
		  Script_Check_Stream();
		  /* Advance to next state */
		  state = STATE_STEP_SCRIPT;
		  break;
	  case STATE_STEP_SCRIPT:
		  /* Call SD script step function */
		  SD_Card_Script_Step();
	  default:
		  /* Go back to first state */
		  state = STATE_CHECK_FLAGS;
		  break;
	  }
  }

  /* Should never get here */
  return 0;
}

/**
  * @brief  This function is executed in case of error occurrence.
  *
  * @return void
  *
  * During init, errors are logged, then init continues. This is
  * done to reduce potential for a fault locking the device in a reset
  * loop.
  */
void Main_Error_Handler()
{
	/* Log error for future retrieval */
	Flash_Log_Fault(ERROR_INIT);
}

/**
  * @brief Init all DMA channels in use and configure DMA interrupts
  *
  * @return void
  *
  * Currently use three DMA channels, on DMA peripheral 1:
  * DMA2/3 - IMU SPI port, used for burst reads from IMU
  * DMA5 - User SPI port, Used for buffer burst outputs. Rx not used
  *
  * All DMA channels are configured to generate interrupts upon the completion
  * of a transfer. The user SPI DMA interrupt is used just to check for any
  * error events which might have occurred during the burst read process.
  *
  * The IMU DMA interrupts are used to determine when a burst read from the
  * IMU has completed. Both the Tx and Rx channels must be done for a burst
  * read to have completed (Tx should finish last).
  */
static void DMA_Init()
{
	/* DMA controller clock enable */
	__HAL_RCC_DMA1_CLK_ENABLE();

	/* SPI1 DMA Init */

	/* SPI1_RX Init */
	g_dma_spi1_rx.Instance = DMA1_Channel2;
	g_dma_spi1_rx.Init.Direction = DMA_PERIPH_TO_MEMORY;
	g_dma_spi1_rx.Init.PeriphInc = DMA_PINC_DISABLE;
	g_dma_spi1_rx.Init.MemInc = DMA_MINC_ENABLE;
	g_dma_spi1_rx.Init.PeriphDataAlignment = DMA_PDATAALIGN_HALFWORD;
	g_dma_spi1_rx.Init.MemDataAlignment = DMA_MDATAALIGN_HALFWORD;
	g_dma_spi1_rx.Init.Mode = DMA_NORMAL;
	g_dma_spi1_rx.Init.Priority = DMA_PRIORITY_HIGH;
	if (HAL_DMA_Init(&g_dma_spi1_rx) != HAL_OK)
	{
	  Main_Error_Handler();
	}
	__HAL_LINKDMA(&g_spi1,hdmarx,g_dma_spi1_rx);

	/* SPI1_TX Init */
	g_dma_spi1_tx.Instance = DMA1_Channel3;
	g_dma_spi1_tx.Init.Direction = DMA_MEMORY_TO_PERIPH;
	g_dma_spi1_tx.Init.PeriphInc = DMA_PINC_DISABLE;
	g_dma_spi1_tx.Init.MemInc = DMA_MINC_ENABLE;
	g_dma_spi1_tx.Init.PeriphDataAlignment = DMA_PDATAALIGN_HALFWORD;
	g_dma_spi1_tx.Init.MemDataAlignment = DMA_MDATAALIGN_HALFWORD;
	g_dma_spi1_tx.Init.Mode = DMA_NORMAL;
	g_dma_spi1_tx.Init.Priority = DMA_PRIORITY_HIGH;
	if (HAL_DMA_Init(&g_dma_spi1_tx) != HAL_OK)
	{
	  Main_Error_Handler();
	}
	__HAL_LINKDMA(&g_spi1,hdmatx,g_dma_spi1_tx);

	/* SPI2_TX Init */
	g_dma_spi2_tx.Instance = DMA1_Channel5;
	g_dma_spi2_tx.Init.Direction = DMA_MEMORY_TO_PERIPH;
	g_dma_spi2_tx.Init.PeriphInc = DMA_PINC_DISABLE;
	g_dma_spi2_tx.Init.MemInc = DMA_MINC_ENABLE;
	g_dma_spi2_tx.Init.PeriphDataAlignment = DMA_PDATAALIGN_HALFWORD;
	g_dma_spi2_tx.Init.MemDataAlignment = DMA_MDATAALIGN_HALFWORD;
	g_dma_spi2_tx.Init.Mode = DMA_NORMAL;
	g_dma_spi2_tx.Init.Priority = DMA_PRIORITY_VERY_HIGH;
	if (HAL_DMA_Init(&g_dma_spi2_tx) != HAL_OK)
	{
	  Main_Error_Handler();
	}
	__HAL_LINKDMA(&g_spi2,hdmatx,g_dma_spi2_tx);

	/* DMA interrupt init */

	/* DMA1_Channel2_IRQn interrupt configuration */
	HAL_NVIC_SetPriority(DMA1_Channel2_IRQn, 0, 0);
	HAL_NVIC_EnableIRQ(DMA1_Channel2_IRQn);

	/* DMA1_Channel3_IRQn interrupt configuration */
	HAL_NVIC_SetPriority(DMA1_Channel3_IRQn, 0, 0);
	HAL_NVIC_EnableIRQ(DMA1_Channel3_IRQn);

	/* DMA1_Channel5_IRQn interrupt configuration */
	HAL_NVIC_SetPriority(DMA1_Channel5_IRQn, 0, 0);
	HAL_NVIC_EnableIRQ(DMA1_Channel5_IRQn);
}

/**
  * @brief System Clock Configuration
  *
  * @return void
  */
static void SystemClock_Config()
{
  RCC_OscInitTypeDef RCC_OscInitStruct = {0};
  RCC_ClkInitTypeDef RCC_ClkInitStruct = {0};
  RCC_PeriphCLKInitTypeDef PeriphClkInit = {0};

  /** Initializes the CPU, AHB and APB busses clocks
  */
  RCC_OscInitStruct.OscillatorType = RCC_OSCILLATORTYPE_HSE;
  RCC_OscInitStruct.HSEState = RCC_HSE_ON;
  RCC_OscInitStruct.PLL.PLLState = RCC_PLL_ON;
  RCC_OscInitStruct.PLL.PLLSource = RCC_PLLSOURCE_HSE;
  RCC_OscInitStruct.PLL.PLLMUL = RCC_PLL_MUL9;
  RCC_OscInitStruct.PLL.PREDIV = RCC_PREDIV_DIV1;
  if (HAL_RCC_OscConfig(&RCC_OscInitStruct) != HAL_OK)
  {
    Main_Error_Handler();
  }
  /** Initializes the CPU, AHB and APB busses clocks
  */
  RCC_ClkInitStruct.ClockType = RCC_CLOCKTYPE_HCLK|RCC_CLOCKTYPE_SYSCLK
                              |RCC_CLOCKTYPE_PCLK1|RCC_CLOCKTYPE_PCLK2;
  RCC_ClkInitStruct.SYSCLKSource = RCC_SYSCLKSOURCE_PLLCLK;
  RCC_ClkInitStruct.AHBCLKDivider = RCC_SYSCLK_DIV1;
  RCC_ClkInitStruct.APB1CLKDivider = RCC_HCLK_DIV2;
  RCC_ClkInitStruct.APB2CLKDivider = RCC_HCLK_DIV2;

  if (HAL_RCC_ClockConfig(&RCC_ClkInitStruct, FLASH_LATENCY_2) != HAL_OK)
  {
    Main_Error_Handler();
  }
  PeriphClkInit.PeriphClockSelection = RCC_PERIPHCLK_USB
		  	  	  	  	  	  	  	  |RCC_PERIPHCLK_TIM2
									  |RCC_PERIPHCLK_TIM34
									  |RCC_PERIPHCLK_ADC12
									  |RCC_PERIPHCLK_TIM8
  	  	  	  	  	  	  	  	  	  |RCC_PERIPHCLK_TIM16;
  PeriphClkInit.USBClockSelection = RCC_USBCLKSOURCE_PLL_DIV1_5;
  PeriphClkInit.Tim2ClockSelection = RCC_TIM2CLK_HCLK;
  PeriphClkInit.Tim34ClockSelection = RCC_TIM34CLK_HCLK;
  PeriphClkInit.Adc12ClockSelection = RCC_ADC12PLLCLK_DIV16;
  PeriphClkInit.Tim8ClockSelection = RCC_TIM8CLK_HCLK;
  PeriphClkInit.Tim16ClockSelection = RCC_TIM16CLK_HCLK;
  if (HAL_RCCEx_PeriphCLKConfig(&PeriphClkInit) != HAL_OK)
  {
    Main_Error_Handler();
  }
}

/**
  * @brief GPIO Initialization Function
  *
  * @return void
  */
static void MX_GPIO_Init()
{
	GPIO_InitTypeDef GPIO_InitStruct = {0};

	/* GPIO Ports Clock Enable */
	__HAL_RCC_GPIOA_CLK_ENABLE();
	__HAL_RCC_GPIOB_CLK_ENABLE();
	__HAL_RCC_GPIOC_CLK_ENABLE();
	__HAL_RCC_GPIOD_CLK_ENABLE();

	/*Configure GPIO port A pin Output Level (high) */
	HAL_GPIO_WritePin(GPIOA, GPIO_PIN_3, GPIO_PIN_SET);

	/*Configure GPIO port B pin Output Level */
	HAL_GPIO_WritePin(GPIOB, GPIO_PIN_6|GPIO_PIN_7, GPIO_PIN_RESET);

	/*Configure GPIO port C pin Output Level */
	HAL_GPIO_WritePin(GPIOC, GPIO_PIN_0|GPIO_PIN_1|GPIO_PIN_8|GPIO_PIN_9, GPIO_PIN_RESET);

	/*Configure GPIO port A input pin : PA8 PA9 */
	GPIO_InitStruct.Pin = GPIO_PIN_8|GPIO_PIN_9;
	GPIO_InitStruct.Mode = GPIO_MODE_INPUT;
	GPIO_InitStruct.Pull = GPIO_NOPULL;
	HAL_GPIO_Init(GPIOA, &GPIO_InitStruct);

	/*Configure GPIO port A output pins : PA3 (IMU Reset) */
	GPIO_InitStruct.Pin = GPIO_PIN_3;
	GPIO_InitStruct.Mode = GPIO_MODE_OUTPUT_PP;
	GPIO_InitStruct.Pull = GPIO_NOPULL;
	GPIO_InitStruct.Speed = GPIO_SPEED_FREQ_HIGH;
	HAL_GPIO_Init(GPIOB, &GPIO_InitStruct);

	/*Configure GPIO port B input pins : PB4 PB5 PB8 PB9 */
	GPIO_InitStruct.Pin = GPIO_PIN_4|GPIO_PIN_5|GPIO_PIN_8|GPIO_PIN_9;
	GPIO_InitStruct.Mode = GPIO_MODE_INPUT;
	GPIO_InitStruct.Pull = GPIO_NOPULL;
	HAL_GPIO_Init(GPIOB, &GPIO_InitStruct);

	/*Configure GPIO port B output pins : PB6 PB7 (Switch control) */
	GPIO_InitStruct.Pin = GPIO_PIN_6|GPIO_PIN_7;
	GPIO_InitStruct.Mode = GPIO_MODE_OUTPUT_PP;
	GPIO_InitStruct.Pull = GPIO_NOPULL;
	GPIO_InitStruct.Speed = GPIO_SPEED_FREQ_HIGH;
	HAL_GPIO_Init(GPIOB, &GPIO_InitStruct);

	/*Configure GPIO port C input pins : PC2 PC3 PC6 PC7 */
	GPIO_InitStruct.Pin = GPIO_PIN_2|GPIO_PIN_3|GPIO_PIN_6|GPIO_PIN_7;
	GPIO_InitStruct.Mode = GPIO_MODE_INPUT;
	GPIO_InitStruct.Pull = GPIO_NOPULL;
	HAL_GPIO_Init(GPIOC, &GPIO_InitStruct);

	/*Configure GPIO port C output pins : PC0 PC1 PC8 PC9 (LED, Switch control) */
	GPIO_InitStruct.Pin = GPIO_PIN_0|GPIO_PIN_1|GPIO_PIN_8|GPIO_PIN_9;
	GPIO_InitStruct.Mode = GPIO_MODE_OUTPUT_PP;
	GPIO_InitStruct.Pull = GPIO_NOPULL;
	GPIO_InitStruct.Speed = GPIO_SPEED_FREQ_HIGH;
	HAL_GPIO_Init(GPIOC, &GPIO_InitStruct);

	/**TIM3 GPIO Configuration PA4     ------> TIM3_CH2 */
	GPIO_InitStruct.Pin = GPIO_PIN_4;
	GPIO_InitStruct.Mode = GPIO_MODE_AF_PP;
	GPIO_InitStruct.Pull = GPIO_NOPULL;
	GPIO_InitStruct.Speed = GPIO_SPEED_FREQ_LOW;
	GPIO_InitStruct.Alternate = GPIO_AF2_TIM3;
	HAL_GPIO_Init(GPIOA, &GPIO_InitStruct);

	/*Configure GPIO port D input pins : PD2 (SD card detect) */
	GPIO_InitStruct.Pin = GPIO_PIN_2;
	GPIO_InitStruct.Mode = GPIO_MODE_INPUT;
	GPIO_InitStruct.Pull = GPIO_NOPULL;
	HAL_GPIO_Init(GPIOD, &GPIO_InitStruct);
}

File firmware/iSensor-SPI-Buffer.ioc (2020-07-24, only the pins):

Mcu.UserName=STM32F303RETx
PA11.Signal=USB_DM
PA12.Signal=USB_DP
PA13.Signal=SYS_JTMS-SWDIO
PA14.Signal=SYS_JTCK-SWCLK
PA15.Signal=SPI3_NSS
PA4.Signal=S_TIM3_CH2
PA5.Signal=SPI1_SCK
PA6.Signal=SPI1_MISO
PA7.Signal=SPI1_MOSI
PA8.Signal=GPIO_Output
PA9.Signal=GPIO_Input
PB12.Signal=SPI2_NSS
PB13.Signal=SPI2_SCK
PB14.Signal=SPI2_MISO
PB15.Signal=SPI2_MOSI
PB3.Signal=SYS_JTDO-TRACESWO
PB4.Signal=GPIO_Output
PB5.Signal=GPXTI5
PB6.Signal=GPIO_Output
PB7.Signal=GPIO_Output
PB8.Signal=GPIO_Output
PB9.Signal=GPIO_Input
PC10.Signal=SPI3_SCK
PC11.Signal=SPI3_MISO
PC12.Signal=SPI3_MOSI
PC6.Signal=GPIO_Input
PC7.Signal=GPIO_Output
PC8.Signal=GPIO_Output
PC9.Signal=GPIO_Output

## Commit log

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2020-03-18 Added regmap
    [iSensor_SPI_Buffer_RegDataFile.csv]
2020-03-18 Implemented register interface. Still has some issues, in the process of debugging
    [SpiPassthrough.c, iSensor-SPI-Buffer.ioc, main.c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]
2020-03-19 Improved register logic, updated regmap and readme
    [iSensor_SPI_Buffer_RegDataFile.csv]
2020-03-19 Reordered some regs to make more sense
    [iSensor_SPI_Buffer_RegDataFile.csv]
2020-03-19 Added new buffer max count register, implemented buffer logic (untested)
    [iSensor_SPI_Buffer_RegDataFile.csv]
2020-03-19 Added settings verification to buffer reset function
    [main.c, registers.c]
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2020-03-19 Added support for setting IMU sclk and stall time
    [SpiPassthrough.c, registers.c, registers.h]
2020-03-19 Created adis1650x spi buffer regmap
    [ADIS1650x_SPI_Buf_Regmap.csv]
2020-03-19 Added code to automatically get build date
    [iSensor_SPI_Buffer_RegDataFile.csv]
2020-03-20 Reworked ISR to not use HAL calls (saves time). Added status register (currently has SPI overflow bit, transaction counter)
    [iSensor_SPI_Buffer_RegDataFile.csv]
2020-03-20 Fixed issue with buffer logic, is now working as expected. Added test code to place entry into buffer when user scratch 0 is written
    [main.c, registers.c, registers.h]
2020-03-20 Added init code for DWT timer, fixed using wrong SPI controller for IMU, updated regmap
    [ADIS1650x_SPI_Buf_Regmap.csv]
2020-03-23 Set up code to manually drive CS, not working correctly atm
    [ADIS1650x_SPI_Buf_Regmap.csv]
2020-03-23 Updated docs to reflect register map changes
    [iSensor_SPI_Buffer_RegDataFile.csv]
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2020-04-24 Updated pin assignments to match schematic. Added init for SPI3 and all GPIO
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2020-04-24 Fixed issue where status wouldnt properly clear. Fixed issue where extra data would pile up in transmit buffer if stall is too short
    [main.c, registers.c]
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2020-04-24 Fixed using wrong PLL multiplier, added ability to change IMU sclk freq on the fly, changed default divider setting to 64 (1.1MHz sclk)
    [SpiPassthrough.c, iSensor-SPI-Buffer.ioc, main.c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]
2020-04-24 Updated register documentation
    [ADIS1650x_SPI_Buf_Regmap.csv, iSensor_SPI_Buffer_RegDataFile.csv]
2020-04-25 Fixed DIO config validation function
    [registers.c, user_interrupt.c]
2020-04-27 Updated DIO master pin assignments in docs. All now trigger same exti interrupt
2020-04-27 Added new DR config register
    [ADIS1650x_SPI_Buf_Regmap.csv, iSensor_SPI_Buffer_RegDataFile.csv]
2020-04-27 Reworked clock config, changed reg defaults
    [iSensor-SPI-Buffer.ioc, main.c, registers.c]
2020-04-27 Implemented factory reset command
    [flash.c, isr.c, registers.c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]
2020-04-27 Added new endurance register, added interrupt functionality, DR setup functionality
    [ADIS1650x_SPI_Buf_Regmap.csv, iSensor_SPI_Buffer_RegDataFile.csv]
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2020-04-27 Added basic data capture implementation - will fix once verified as working
    [isr.c, main.c]
2020-04-27 Fixed DR parsing masking polarity bit, moved firmware rev to correct location
    [registers.c]
2020-04-27 Fixed DR interrupt to actually clear interrupt flag. Added buffer interrupt bit to status reg
    [isr.c, registers.h, user_interrupt.c]
2020-04-27 Added interrupt source clear to enable/disable functions. Fixed parsing DR pin wrong
2020-04-27 Added logic to change SPI settings in runtime. Is kinda wonky because you have to have SPI access in the first place to change the settings
2020-04-28 Updated docs to have new registers. Fixed bug in user spi update function making spi port go to the wrong CPHA mode
    [ADIS1650x_SPI_Buf_Regmap.csv, iSensor_SPI_Buffer_RegDataFile.csv]
2020-04-28 Implemented flash update routine. Changed factory reset to not reset endurance counter
    [flash.c, registers.c, registers.h]
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2020-04-28 Added led control module, added function to get hardware id code (currently unused)
2020-04-28 Added 2us offset to imu spi stall time to compensate for function delay
    [spi_passthrough.c]
2020-04-28 Changed init to configure slave SPI based on saved user spi config register value
2020-04-28 Made it so green LED is on while data capture enabled, red led is on when STATUS error flags are set
    [led.c, main.c, registers.c]
2020-04-28 Changed SPI config parsing to use defines instead of hard coded masks
2020-04-28 Moved enable user SPI out of main - user SPI is now configured only in one location, based on config register value
2020-04-28 added fault handlers to isr file. Planning on making it so device logs error info to flash and reboots
    [isr.c, main.c, registers.c]
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2020-04-29 Fixed lower case file exention on image linnk
2020-04-29 Updated status reg bits, fixed typo in flow chart
    [registers.h]
2020-04-29 Updated status clear mask to include all sticky bits, changed error parsing for LED status to include status bits 0 - 9
    [led.c, registers.h]
2020-04-29 Moved capture enable/disable processing to main loop to prevent SPI overrun from occurring when changing pages
    [main.c, registers.c, registers.h]
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2020-04-29 A bunch of misc changes, added error handling to fault ISRs, added new register to report the type of a given hard fault, added 4 more user scratch regs, moved around some registers in memory
    [ADIS1650x_SPI_Buf_Regmap.csv, iSensor_SPI_Buffer_RegDataFile.csv]
2020-04-29 Made it so capture enable occurs in main loop, capture disable directly in ISR. This should prevent poor stall time when disabling capture
    [main.c, registers.c, registers.h]
2020-04-30 Implemented watchdog reset timer
    [main.c]
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2020-05-27 Inverted LED polarity
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2020-05-28 Updated documentation to include new buffer timestamp registers
    [ADIS1650x_SPI_Buf_Regmap.csv, iSensor_SPI_Buffer_RegDataFile.csv]
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2020-05-28 Added timestamp to buffer entry, fixed regmap
    [ADIS1650x_SPI_Buf_Regmap.csv]
2020-05-28 Added some test function stubs, implemented stall time test
2020-05-29 Added metadata to regmap
    [iSensor_SPI_Buffer_RegDataFile.csv]
2020-05-29 Fixed duplicate declarations for i
    [registers.c]
2020-05-29 Renamed status and count registers on page 255
    [iSensor_SPI_Buffer_RegDataFile.csv]
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2020-06-02 Added three new registers - flash sig, derived flash sig, buffer sig
    [iSensor_SPI_Buffer_RegDataFile.csv]
2020-06-02 Removed factory reset for bad register contents, made it so derived flash sig reg is populated
    [flash.c, registers.h]
2020-06-02 Moved around some registers to better align with how data is stored in buffer entry
    [iSensor_SPI_Buffer_RegDataFile.csv]
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2020-06-03 Updated combined falcon regmap
    [ADIS1650x_SPI_Buf_Regmap.csv]
2020-06-18 Added adis 1649x regmap (with SPI buffer), moved to regmaps folder
    [ADIS1649x_SPI_Buf_Regmap.csv, ADIS1650x_SPI_Buf_Regmap.csv, iSensor_SPI_Buffer_RegDataFile.csv]
2020-06-25 Added hardware resource files for PCB Rev B
    [iSensor_SPI_Buffer_RevB.brd, iSensor_SPI_Buffer_RevB.sch]
2020-06-25 Updated the 50x register map
    [ADIS1650x_SPI_Buf_Regmap.csv]
2020-06-25 Fixed incorrect polarity for switch control IC
    [user_interrupt.c]
2020-06-26 Added 3d-printable interposer
    [SPI-Buffer-Interposer.ipt, SPI-Buffer-Interposer.stl]
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2020-06-26 Fixed buffer overflow issue
    [registers.c]
2020-06-26 Updated docs to add new register for PPS timestamp functionality and error interrupt output
2020-06-26 Did some major code refactoring. Added new timer and DIO modules to allow for better organization. Added 5 new registers, and functionality for PPS timestamp synchronization, error interrupt generati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
    [iSensor_SPI_Buffer_RegDataFile.csv]
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2020-06-27 Changed default IMU SPI stall to 15us
    [registers.h]
2020-07-01 Added implementation for USB_CONFIG register. Added new delim command to USB CLI
    [iSensor_SPI_Buffer_RegDataFile.csv]
2020-07-06 Reworked output GPIO configuration logic
    [dio.c, timer.c]
2020-07-06 Updated regmaps with new registers
    [ADIS1649x_SPI_Buf_Regmap.csv, ADIS1650x_SPI_Buf_Regmap.csv]
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2020-07-06 Added UTC timestamp to buffer entry. Removed delta time
    [iSensor_SPI_Buffer_RegDataFile.csv]
2020-07-06 Fixed buf data base address define
    [isr.c]
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2020-07-06 Updated regmaps (again...)
    [ADIS1649x_SPI_Buf_Regmap.csv, ADIS1650x_SPI_Buf_Regmap.csv]
2020-07-07 Fixed bug where LSB first mode wouldnt actually change
    [registers.c]
2020-07-07 Added more commenting for missing documentation
    [flash.c, imu_spi.c, registers.h]
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2020-07-07 Fixed GPIO init function to actually set LEDs as outputs
    [main.c]
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2020-07-09 Fixed buf_config default, removed status TC test
    [iSensor_SPI_Buffer_RegDataFile.csv]
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2020-07-10 temp reading now produces and scales data. Think the wrong source is set, output values are way off
    [adc.c, adc.h, main.c]
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2020-07-15 Fixed issue where you would sometimes get invalid IMU stall time
    [isr.c]
2020-07-21 Renamed adc module to temp, got everything working
    [iSensor_SPI_Buffer_RegDataFile.csv]
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2020-07-23 Added burst regs to regmap
    [iSensor_SPI_Buffer_RegDataFile.csv]
2020-07-24 Fixed register bit assignments to actually match docs
    [isr.c, main.c, registers.c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]
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2020-07-27 Reworked user burst significantly. Now only uses tx DMA and interrupts on CS rising edge
    [isr.c, main.c]
2020-07-28 Reworked user SPI interface to interrupt on rising edge of CS in all modes
    [isr.c, registers.c, registers.h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]
2020-07-28 Fixed overflow error handling case to now load more data
    [isr.c]
2020-07-28 added PPS unlock detection for pps period error of more than 1%
    [timer.c]
2020-07-28 Replaced trash reads with (void) cast
    [isr.c]
2020-07-29 Fixed extra word being placed in SPI Tx FIFO when an overrun error event is generated
    [isr.c]
2020-07-29 Flagged timestamp registers as 32 bit in regmap
    [iSensor_SPI_Buffer_RegDataFile.csv]
2020-07-29 Added IMU reset function
    [imu_spi.c]
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2020-07-29 Fixed file close calls to use file handle, whoops
    [sd_card.c]
2020-08-02 Reverted flash reg routine to error correct by performing a factory reset and flash update if a flash error is detected on startup. Moved flash register array to the middle of flash to avoid contenti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
    [flash.c, main.c]
2020-08-02 Fixed issue with CS PWM timer configuration making changes take one period to be applied. Now compare register is updated immediately
    [imu_spi.c]
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2020-08-02 Implemented SD card detect function. Doesn't seem to be working - starting script causes a watchdog timeout on file enumeration
    [sd_card.c]
2020-08-02 Made it so factory reset does not calculate new flash_sig_drv. This register value is now only set at init
    [main.c, registers.c]
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2020-08-05 changed the function which applied the IMU SPI config to actually reset the SPI peripheral using the reset control unit (should behave the same as coming out of POR)
    [imu_spi.c]
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2020-08-05 added 1us offset to spi passthrough stall time
    [imu_spi.c]
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2020-08-06 Added call to errorhandler which was somehow removed
    [temp.c]
2020-08-06 Removed reset from error handler. Probably safer to attempt to start up (enabling debug) rather than getting stuck in a reset loop
    [main.c]
2020-08-06 Fixed issue where IMU data ready interrupt would be cleared by CS rising edge ISR. Fixed issue where sometimes user SPI would not properly reset before a burst, resulting in a data offset
    [isr.c, main.c, registers.c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]
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2020-08-07 Added BUF_RETRIEVE stall time test (register mode)
2020-08-09 Added watchdog reset check to script autorun function
    [sd_card.c]
2020-08-10 Fixed a few issues, USB CLI now working again
    [main.c, script.c]
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2020-08-10 Fixed potential buffer overflow issue. Reworked blocking USB transmit function call
    [script.c]
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2020-08-23 Added VDD output to register definition
    [iSensor_SPI_Buffer_RegDataFile.csv]
2020-08-23 SD card logging implementation should be done. Still work remaining to debug some misc bugs. Made changes to remove all compiler warnings
    [sd_card.c]
2020-08-23 Reworked main state machine to be cleaner
    [main.c]
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2020-08-23 Added decimation to temp reading to make it less noisey
    [adc.c, adc.h]
2020-08-24 Added two new script info registers - line counter, and error status register
    [iSensor_SPI_Buffer_RegDataFile.csv]
2020-08-24 Implemented script error and line register functionality
    [sd_card.c]
2020-08-24 Added new regs to the IMU reg maps
    [ADIS1649x_SPI_Buf_Regmap.csv, ADIS1650x_SPI_Buf_Regmap.csv]
2020-08-24 Made it so VREFINT is sampled prior to temp sensor. This prevents issue where TEMP warning is set in STATUS on startup, due to Vdd register being zero when first temp sensor value is calibrated
    [adc.c, adc.h]
2020-09-06 Renamed USB_CONFIG to CLI_CONFIG
    [iSensor_SPI_Buffer_RegDataFile.csv]
2020-09-06 Continued SD card data logging implementation. Script file load now working, program throws error creating result text file however
    [sd_card.c]
2020-09-16 Added critical section to buf dequeue to prevent potential issues if interrupted by IRQ
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2020-09-21 Fixed DIO write mask
    [dio.c]
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2020-09-28 Changed delay microseconds function to reset DWT timer
    [timer.c]
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2020-10-01 Fixed issue in SD card disk I/O driver causing buffer overflow by 1 byte
    [sd_card.c]
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2020-10-01 Reverted so output file is opened in append mode. Fixed bug in SD tx handler
    [sd_card.c]
2020-10-01 Fixed issue with script start message having extra null char at the end
    [sd_card.c]
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2020-10-01 Fixed some missing function documentation, updated header file to exclude functions from doxygen output
    [adc.h]
2020-10-01 Added more missing documentation
    [adc.h, main.c, script.c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]
2020-10-05 Resolved some issues where potentially you could get an extra delimiter on the last line of a read/stream
    [script.c]
2020-10-05 Made CLI tx handlers return for count of 0, fixed issue where two newlines could be inadvertently inserted
    [script.c, sd_card.c]
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2020-10-09 Added new DFU module, and command to enable reboot into DFU mode. Modified linker script to reserve 4bytes of RAM at the end of the memory for storing flags through a reset
    [main.c, registers.c, registers.h]
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2020-10-12 Changed scr0 -> btn config
    [iSensor_SPI_Buffer_RegDataFile.csv]
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2020-10-18 Added 40ms (min) delay between sending commands. Should not be a big issue - it is recommended to use stream for any real data capture. Read/write is just for configuration
    [spi_buf_cli.py]
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2020-10-22 Fixed bug where cancelling a stream would make the last line be invalid
    [spi_buf_cli.py]
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2020-10-24 Some pretty major changes here. I added a new feature which allows the buffer board to generate an internal sync clock that can be passed to IMU, or used as buffered capture trigger for testing. Deci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
    [ADIS1649x_SPI_Buf_Regmap.csv, ADIS1650x_SPI_Buf_Regmap.csv, iSensor_SPI_Buffer_RegDataFile.csv]
2020-10-24 Updated g_regs extern reference to specify size for all files. Fixed some incorrect reg indexes
    [adc.c, dio.c, flash.c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]
2020-10-25 Added more tests, fixed issue where calling stop stream prior to start would cause error
    [spi_buf_cli.py, test.py]
2020-10-25 Fixes issue with running stream repeatedly. Added stream benchmark program
    [spi_buf_cli.py]
2020-11-08 Fixed issue where calling stream stop prior to start would cause crash
    [spi_buf_cli.py]
2020-11-08 Added helper functions to set IMU sclk freq, stall time, and enable burst stream
    [spi_buf_cli.py]
2020-11-09 Imagine spending literally hours trying to debug an issue and the root cause of the issue is that I am apparently partly dsylexic
    [spi_buf_cli.py]
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2021-04-23 Added scale factor for temp and VDD outputs to regmap
    [iSensor_SPI_Buffer_RegDataFile.csv]
2021-04-23 Fixed bug where writing to DIO_INPUT_CONFIG then enabling PPS would inadvertently start a capture early by enabling the IMU DR interrupt
    [dio.c, main.c, timer.c]
2021-05-11 Removed USB disconnect function - this was not working as expected. Added function to toggle the USB PU pin to trigger a device re-enumeration. This function is always run on startup
    [main.c, registers.c]
2021-05-11 Updated functional timing doc. Fixed issue where power cycle test did not power off DUT long enough
2021-05-11 Marked buffer timestamp regs as 32-bit
    [iSensor_SPI_Buffer_RegDataFile.csv]
2021-05-11 Reworked logic to enable/disable capture. Now capture is only enabled once when page 255 is first selected. This resolves an issue where samples would be skipped if page 255 was selected multiple tim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
    [registers.c]
2021-07-22 Moved rev B hardware design files to their own folder. Uploaded initial schematic, layout, and BOM for rev C board
    [05-067508-01-a.csv, SPI-Buffer-Interposer.ipt, SPI-Buffer-Interposer.stl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]
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2021-08-24 Reworked user SPI to operate in byte mode rather than 16-bit mode. In 16-bit mode, data was being discarded when CS went high without a full word being received. With the current config, each byte is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
    [isr.c, user_spi.c]
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2021-08-24 Made some tweaks to the SPI interrupt handler to improve error handling
    [isr.c]
2021-08-24 Changed user SPI to operate in byte mode and interrupt once two bytes of data have been received. This improves consistency of behavior. There is still some risk if you transmit an extra byte that th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
    [isr.c, user_spi.c]
2021-08-24 Working on trying to get the burst to work. It seems like changing the DMA to byte mode has caused the endianness of the burst outputs to become swapped. Might have to reconfigure SPI word size for b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
    [isr.c, main.c, reg.c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]
2021-08-25 Reworked the scheme for how burst works. I need to make a flow chart for this so it is clear. Essentially, burst operates with the SPI in 16-bit mode, while register access operates in 8-bit mode. Th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
    [isr.c, main.c, reg.c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]
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2021-08-26 Made some tweaks to the burst setup process. Now, when a burst read is first requested, the software waits for a CS posedge before reconfiguring the SPI for a burst read. This avoids an issue where t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
    [isr.c, main.c, reg.c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]
2021-08-26 Updated 49x regmap to use buffer board output registers for burst read
    [ADIS1649x_SPI_Buf_Regmap.csv, BufferOutputRegList.csv]
2021-08-26 Corrected buffer output registers being flagged as signed
    [ADIS1649x_SPI_Buf_Regmap.csv, ADIS1650x_SPI_Buf_Regmap.csv]
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2021-08-27 Made a small change to the IMU passthrough function. Added stall time to the end of each tranfer to prvent potential stall time violations if back to back reads are issued
    [imu.c]
2021-08-30 Cleaned up the burst handler to fix issue when exiting burst mode
    [isr.c]
2021-11-05 Rebuilt doxygen output
    [copper_bottom.gbr, copper_top.gbr, drill_1_16.xln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]
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

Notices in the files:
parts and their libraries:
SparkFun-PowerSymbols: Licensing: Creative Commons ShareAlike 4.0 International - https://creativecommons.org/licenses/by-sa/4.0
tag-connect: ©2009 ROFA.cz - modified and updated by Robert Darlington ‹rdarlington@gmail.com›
